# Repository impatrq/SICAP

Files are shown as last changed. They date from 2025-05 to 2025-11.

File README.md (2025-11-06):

erasebg-transformed (2)_Edited

<div align="center">

🔗 Visitanos en  
👉 <a href="https://sicap.site" target="_blank" rel="noopener noreferrer"><strong>sicap.site</strong></a>

## 🎥 Presentación oficial del proyecto

<a href="https://www.youtube.com/watch?v=k7C2opmh9fs" target="_blank" rel="noopener noreferrer">
  
</a>

<br><br>

<a href="https://www.instagram.com/proyecto.sicap/" target="_blank" rel="noopener noreferrer">
  Instagram
  @proyecto.sicap
</a>

</div>

---

## Logros y Reconocimientos

🏅 **Ganadores del 1° puesto en la categoría Prototipos - ONIET 2025** (puntaje: 96/100)  
🎖️ **5° puesto en SysApp - ONIET 2025** (puntaje: 87/100)  
📍 Representando a la **E.E.S.T. N°7 “Taller Regional Quilmes”**, Buenos Aires, Argentina

## Nuestra Propuesta

**SICAP** (Sistema Inteligente de Control de Almacén y Pañol) es una solución automatizada pensada para mejorar la gestión de herramientas, materiales e insumos en talleres, escuelas técnicas y empresas. Utiliza RFID, ESP32 y servidores locales para registrar entradas y salidas de forma confiable.

---

## Cómo surgió el proyecto

Observamos que muchos entornos técnicos carecen de un sistema eficiente para controlar el stock de herramientas. Esto genera pérdidas, desorganización y retrabajo. A partir de esa problemática, decidimos desarrollar SICAP como una solución real, útil y adaptable.

---

## Características Principales

- Lectura RFID con ESP32  
- Interfaz web responsive  
- Base de datos local  
- Control por ID de usuario  
- Placa RS232 a TTL desarrollada a medida  
- Registro de entradas/salidas automático  
- Acceso desde cualquier dispositivo conectado a la red

---

## Arquitectura del Sistema

SICAP se compone de tres módulos principales:

1. **Módulo de Lectura RFID (Hardware):**  
   Basado en un lector UHF SAMSys MP9320 y un microcontrolador **ESP32**, encargado de enviar los datos de las etiquetas detectadas al servidor mediante HTTP.

2. **Servidor Backend (Software):**  
   Desarrollado en **Django (Python)**, gestiona la base de datos, las peticiones del ESP32 y la administración del sistema.

3. **Interfaz Web (Frontend):**  
   Programada en **TypeScript con Ionic**, permite visualizar, editar y gestionar los registros de herramientas, empleados e insumos de forma intuitiva.

---

## Integrantes

WhatsApp Image 2025-08-27 at 11 02 59
<div align="center">

| Nombre | Contacto | Redes |
|:--|:--|:--|
| **Patella Tiziano** | 📧 tizianopatella40@gmail.com |  &nbsp;  &nbsp;  |
| **Lautaro Santolucito** | 📧 lauty.santolucito@icloud.com |  &nbsp;  &nbsp;  |
| **Facundo Spagnoletta** | 📧 facu.spagnoleta@gmail.com |  &nbsp;  &nbsp;  |
| **Facundo Ledesma** | 📧 facundoledesma140@gmail.com |  &nbsp;  &nbsp;  |
| **Pablo Osores** | 📧 pablooosores@gmail.com |  &nbsp;  &nbsp;  |

</div>

---

## Agradecimientos

Agradecemos a nuestros docentes, especialmente al profesor **Medina y Carlassara**, por su acompañamiento constante, y a **Transporte Miloser S.A.; Ledmull; La Popular Hamburguesas; Checkpoint** por su apoyo como sponsor durante el desarrollo del proyecto.

---
## Información de Contacto

🌐 Sitio web oficial: [sicap.site](https://sicap.site)  
📸 Instagram: [@proyecto.sicap](https://www.instagram.com/proyecto.sicap/) 📱🙌🎉  
📧 Correo: **proyecto.sicap08@gmail.com**

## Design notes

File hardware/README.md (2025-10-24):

# 🧰 Hardware – Proyecto SICAP

El directorio **`hardware/`** reúne todos los diseños, esquemas, prototipos y componentes físicos desarrollados para el proyecto **SICAP**.  
Aquí se documenta la parte **electrónica y estructural** del sistema, incluyendo las placas de conexión, adaptadores, antenas y configuraciones del lector RFID.

---

## ⚙️ Propósito del módulo de hardware

El objetivo del área de hardware dentro del proyecto SICAP es **garantizar la comunicación estable y confiable entre el lector RFID SAMSys MP9320, el microcontrolador ESP32 y las antenas UHF**, asegurando que el sistema funcione correctamente tanto a nivel eléctrico como de señal.

## 🔩 Componentes principales

| Componente | Función | Descripción |
|---|---|---|
| **SAMSys MP9320** | Lector RFID UHF | Captura las etiquetas EPC Gen2. |
| **ESP32 DevKit V1** | Microcontrolador | Ejecuta el firmware y envía datos al servidor. |
| **Conversor RS232–TTL** | Adaptador de señal | Permite la comunicación entre el lector y el ESP32. |
| **Antenas UHF** | Módulo lector pasivo | Detectan las etiquetas dentro del área de cobertura. |

---

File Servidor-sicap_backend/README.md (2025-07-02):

# SICAP - Backend

Este es el backend del sistema S.I.C.A.P., hecho con Django. Se encarga de recibir los datos enviados por el ESP32 (por ejemplo, los tags RFID) y guardarlos automáticamente en una base de datos.

Dicho en pocas palabras, el servidor interno de S.I.C.A.P.

---

## ¿Qué hace este servidor?

- Recibe datos a través del endpoint `/api/recibir/` en formato JSON.
- Guarda esos datos en la base, incluyendo el tag y la fecha/hora en que llegó.
- Más adelante, estos datos se van a poder consultar desde la web del proyecto.

---

## ¿Qué estructura tiene el proyecto?

- El proyecto Django se llama `sicap_backend`.
- Adentro hay una app llamada `registros`, que maneja todo lo relacionado a los tags RFID.

---

## ¿Qué modelo usamos para guardar los datos?

Dentro de la app `registros`, hay un modelo llamado `RegistroTag`. Guarda dos cosas:
- `tag_id`: el tag que mandó el ESP32.
- `fecha_hora`: se guarda automáticamente cuando llega el dato.

---

## ¿Qué falta?

- Conectar el ESP32 y hacer que mande el JSON real.
- Hacer pruebas con hardware real.
- En el futuro, conectar este backend con la página web para consultar todos los registros.

---

## Estado: 🟡 En pruebas

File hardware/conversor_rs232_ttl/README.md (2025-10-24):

# 🔌 Placa Conversora RS232 ↔ TTL – Proyecto SICAP

La **placa conversora RS232 ↔ TTL** fue diseñada como parte del sistema **SICAP** con el fin de permitir la comunicación directa entre el **lector RFID industrial SAMSys MP9320** y el **microcontrolador ESP32**.  
Dado que ambos dispositivos trabajan con niveles eléctricos diferentes, este circuito actúa como **interfaz de adaptación de señal** para garantizar una comunicación serial estable, segura y bidireccional.

---

## ⚙️ Propósito de la placa

- Adaptar los niveles de voltaje entre el lector RFID (RS232 ±12 V) y el ESP32 (TTL 3.3 V).  
- Permitir la transmisión y recepción de comandos seriales sin distorsión.  
- Asegurar la integridad de los datos durante la comunicación continua.  
- Reducir el riesgo de daño en los pines del microcontrolador por diferencia de tensiones.

---

## 🧠 Descripción técnica

El circuito está basado en el integrado **MAX3232**, un conversor de nivel de voltaje compatible con microcontroladores modernos de 3.3 V.  
Su función es traducir las señales **TX** y **RX** del lector RFID a niveles seguros y comprensibles para el ESP32, y viceversa.

### Características principales
- **Chip:** MAX3232 (compatible con 3.3 V y 5 V).  
- **Alimentación:** 3.3 V proveniente del ESP32.  
- **Entradas/salidas:**  
  - Lado RS232: conector DB9 (lector RFID).  
  - Lado TTL: pines TX, RX, GND hacia el ESP32.  
- **Frecuencia de transmisión:** hasta 250 kbps.  
- **Protección:** capacitores de desacople y diodos de protección en líneas críticas.

---

## 🧩 Integración en el sistema

La placa conversora forma parte del **bloque de hardware principal** del proyecto.  
Cumple el rol de intermediario entre el lector RFID y el microcontrolador:

Lector RFID (RS232)  ⇄  Placa Conversora  ⇄  ESP32 (TTL 3.3V)
El firmware del ESP32 se comunica a través de esta placa utilizando comandos ASCII, como por ejemplo `A,0!`, `Rd`, `Z!`, etc.  
El lector responde con tramas del tipo `{Rd,d:300833B2DDD9014035050000,t:EPC1G2}`, que son luego interpretadas por el firmware y enviadas al servidor SICAP.

---

## 🧪 Pruebas de validación

- **Conversión de señal:** Verificada con osciloscopio y mediciones en ambos lados.  
- **Comunicación estable:** Confirmada entre el lector y el ESP32 a distintas tasas de baudios.  
- **Integridad de datos:** Sin pérdida de información en lecturas prolongadas.  
- **Protección eléctrica:** Validada sin sobrecargas ni fallos por inversión de polaridad.  

---

## 🔩 Materiales utilizados

- 1 × Integrado **MAX3232**  
- 4 × Capacitores de 0.1 µF (para carga y desacople)  
- 1 × Conector DB9 hembra (para el lector)  
- 1 × Header macho 3 pines (TX, RX, GND hacia el ESP32)  
- 1 × Placa PCB diseñada y fabricada por el grupo SICAP  
- Cables Dupont y jumpers de conexión

---

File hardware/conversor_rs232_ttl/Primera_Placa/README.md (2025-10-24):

# ⚙️ Primera Placa – Conversor RS232 ↔ TTL

Esta carpeta contiene los archivos y documentación correspondientes a la **primera versión** de la **placa conversora RS232 ↔ TTL** desarrollada para el proyecto **SICAP**.  
Fue el primer prototipo funcional diseñado para adaptar las señales eléctricas entre el **lector RFID SAMSys MP9320** (nivel RS232 ±12V) y el **microcontrolador ESP32** (nivel TTL 3.3V).

---

## 🧠 Objetivo

El objetivo de esta primera placa fue **probar la comunicación física entre el lector y el ESP32**, validando la correcta conversión de voltajes y la transmisión de datos por puerto serial.

Se buscó construir un **circuito compacto, confiable y reproducible**, que reemplazara los adaptadores comerciales utilizados durante las pruebas iniciales.

---

## ⚠️ Error detectado en la versión

Durante las pruebas de funcionamiento se detectó un **error en el diseño del circuito impreso (PCB)**.  
El problema consistía en **una pista faltante** que impedía la correcta conexión entre una de las líneas de transmisión del chip MAX3232 y el conector correspondiente.

Como resultado:
- El circuito **alimentaba correctamente el integrado**,  
  pero **no transmitía señal entre el lector y el ESP32**.  
- Las pruebas con osciloscopio mostraron ausencia de datos en el pin TX del lado TTL.  
- Se descartaron fallas del chip o del cableado, confirmando un **error de diseño** en la placa.

---

## 🔄 Resultado y corrección

A partir de este error, se procedió al rediseño completo de la placa, dando origen a la **Segunda_Placa**, que incluyó:
- Corrección de la pista faltante.  
- Reubicación de componentes para mayor claridad.  
- Trazado más limpio de las líneas de comunicación.  
- Testigo de funcionamiento (LED)
- Verificación del esquema con simulación previa a la fabricación.

Esta mejora permitió establecer una comunicación estable y definitiva entre el **lector RFID** y el **ESP32**.

---

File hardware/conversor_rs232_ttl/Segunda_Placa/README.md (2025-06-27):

# RS232 a TTL

Este módulo es un conversor de señal RS232 a TTL, utilizado en el proyecto SICAP para permitir la comunicación entre el microcontrolador ESP32 y el lector RFID que trabaja con señal RS232.

---

**¿Por qué lo hicimos?**  
Los lectores RFID comerciales que conseguimos trabajan bajo el protocolo RS232, pero el ESP32 solo puede interpretar señales TTL (3.3V/5V). Por eso, diseñamos e implementamos esta plaqueta para hacer la conversión y asegurar una lectura estable y sin errores.

---

**🛠️ Componentes usados**  
- MAX232
- Capacitores de desacople (1µF)  
- PCB diseñada a medida (archivos incluidos)  
- Pines macho para conexión a protoboard

---

**📂 Archivos incluidos**  
- `esquematico.pdf`: Diagrama del circuito  
- `pcb_layout.png`: Imagen de la placa diseñada  
- `README.md`: Este archivo  

> Si aún no subiste los archivos, podés preparar esos .pdf y capturas para completar este README.

---

**📈 Estado del módulo**  
✅ Probado con ESP32 y lector RFID  
✅ Confirmada la lectura estable de tarjetas

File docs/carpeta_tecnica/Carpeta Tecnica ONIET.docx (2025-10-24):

# Proyecto S.I.C.A.P – Carpeta Técnica Oficial

Sistema Integral de Control Automatizado del Pañol (SICAP)

“Orden inteligente, control eficiente”

## 1. Introducción y Objetivos

El Proyecto S.I.C.A.P. (Sistema Integral de Control Automatizado del Pañol) surge como respuesta a un problema cotidiano en talleres, escuelas técnicas y empresas: la pérdida de herramientas y la falta de trazabilidad en su uso. Este sistema propone modernizar la gestión del pañol de herramientas mediante tecnología RFID e IoT, evitando pérdidas, mejorando la organización y permitiendo decisiones informadas basadas en datos actualizados .

Objetivo general: Desarrollar e implementar un sistema integral y automatizado de control de activos (herramientas) en un pañol, capaz de registrar en tiempo real la entrada y salida de herramientas y quién las toma, eliminando registros manuales y mejorando la eficiencia en la gestión.

Objetivos específicos:

- Identificación automática por RFID: Equipar cada herramienta con una etiqueta RFID UHF y cada usuario con una tarjeta/pulsera RFID para detectar su identidad al retirar o devolver herramientas.
- Detección y registro en tiempo real: Implementar un portal RFID en la entrada/salida del pañol que, mediante antenas y un lector controlado por ESP32, detecte automáticamente qué herramienta sale o ingresa y qué usuario la porta.
- Servidor local de datos: Desplegar un servidor local (Raspberry Pi) con una base de datos integrada que reciba los datos de cada evento (herramienta retirada/devuelta, usuario, fecha y hora) y los almacene automáticamente.
- Interfaz de gestión web: Desarrollar una aplicación web accesible desde cualquier dispositivo en la red interna, para visualizar el inventario en tiempo real (qué herramientas están disponibles o en uso, quién las tiene, cuándo fueron retiradas), así como administrar usuarios y herramientas.
- Seguridad y control: Restringir el sistema a una red local dedicada para asegurar que solo el personal autorizado pueda acceder, y mantener un registro histórico de movimientos para auditorías o análisis futuros.
- Integración pedagógica: Permitir a los desarrolladores (estudiantes) aplicar conocimientos de electrónica, redes y programación en un proyecto integrador real, aprendiendo sobre microcontroladores, bases de datos, backend web y desarrollo frontend, al tiempo que resuelven un problema concreto de su entorno educativo.

## 2. Justificación Técnica y Pedagógica

Justificación técnica: Muchas instituciones educativas y talleres enfrentan pérdida de herramientas, desorden y falta de control en sus pañoles. Un sistema automatizado como SICAP mejora significativamente la eficiencia al eliminar registros manuales y reducir extravíos, brindando control y responsabilidad compartida. La tecnología RFID UHF fue elegida por su capacidad de identificar múltiples objetos a distancia, incluso varios metros, sin requerir línea de vista. Esto la hace ideal para monitorear herramientas en tiempo real sin intervención humana, evitando errores y registrando todo automáticamente. Además, el uso de una arquitectura IoT local (ESP32 + servidor Raspberry Pi) garantiza que el sistema funcione aunque no haya Internet, manteniendo los datos dentro de la institución para mayor seguridad y velocidad de acceso.

Justificación pedagógica: El proyecto SICAP se desarrolló en un contexto escolar técnico, por lo que su implementación tuvo también fines educativos. Los estudiantes involucrados reforzaron competencias en diversas áreas de la tecnología:

- Electrónica y hardware: diseño de circuitos (por ejemplo, un conversor RS232-TTL para el lector RFID), integración de sensores/antenas RFID con microcontroladores, y ensamblaje de un portal de detección.
- Programación embebida: desarrollo de código en MicroPython para el ESP32, manejando comunicación serial (UART) y protocolos de red (WiFi).
- Administración de sistemas: configuración de un servidor Linux (Raspberry Pi), instalación de servicios (servidor web Django, base de datos SQLite) y configuración de redes LAN/WiFi.
- Desarrollo web: implementación de un backend con Django (incluyendo APIs REST) y una interfaz web frontend (web app) usando frameworks modernos (Ionic/Angular), aplicando principios de diseño web responsivo.
- Gestión de proyectos: documentación técnica completa, pruebas de funcionamiento y trabajo colaborativo, simulando un entorno de desarrollo profesional. Se integraron áreas de software y hardware, lo que brindó a los alumnos una experiencia holística de ingeniería de sistemas.

Desde el punto de vista pedagógico, SICAP sirvió como proyecto integrador que permitió a los estudiantes aplicar en la práctica contenidos de años anteriores y resolver problemas reales de su institución. Asimismo, se fomentó el trabajo en equipo, la resolución de problemas, la creatividad en el diseño de soluciones y la comunicación efectiva (por ejemplo, presentando el proyecto a la comunidad y buscando sponsors para componentes). En resumen, SICAP no solo aporta una solución tecnológica versátil y funcional al control de activos físicos , sino que también representa un valioso logro pedagógico al consolidar el aprendizaje multidisciplinar en un proyecto tangible.

## 3. Alcance y Limitaciones

Alcance del sistema: El alcance de SICAP es modular y escalable, lo que significa que puede adaptarse a distintos entornos y escalas de uso . Inicialmente, el proyecto se centró en un pañol de herramientas de un taller escolar, pero la misma solución es aplicable a otros escenarios:

- En bibliotecas, para control automatizado de préstamos y devoluciones de libros mediante etiquetas RFID en libros y carnés .
- En depósitos de insumos o almacenes, para monitorear stock en tiempo real y registrar movimientos de inventario automáticamente .
- En laboratorios, para seguimiento de equipos y materiales sensibles.
- En general, cualquier espacio que necesite gestión eficiente y trazable de objetos físicos podría beneficiarse de SICAP .

El sistema abarca todos los componentes necesarios para su funcionamiento autónomo dentro de la institución:

- Un portal RFID físico instalado en el acceso al pañol.
- Múltiples etiquetas RFID UHF adheridas a cada herramienta, y tags RFID personales para identificar usuarios (p. ej., en tarjetas o pulseras).
- Un dispositivo lector (ESP32) conectado a las antenas RFID del portal, encargado de leer los tags y transmitir los datos.
- Una infraestructura de red local (router WiFi dedicado) que conecta inalámbricamente el ESP32 con el servidor central.
- Un servidor central (Raspberry Pi) ejecutando el backend (Django) y alojando la base de datos local donde se almacenan los registros.
- Una aplicación web accesible a través de la red local para consultar el estado del sistema e interactuar (gestionar usuarios, etc.).

Limitaciones del proyecto: Si bien SICAP se diseñó para ser versátil, en su implementación actual presenta las siguientes limitaciones:

- Alcance físico limitado: El sistema está pensado para operar en la red local de la institución. No cuenta con acceso remoto vía Internet (aunque podría incorporarse en el futuro), lo que significa que para usar la web app o consultar datos, el dispositivo cliente debe estar conectado al router interno de SICAP.
- Cobertura RFID específica: Se emplearon etiquetas y antenas UHF optimizadas para distancias de varios metros. Sin embargo, la efectividad de detección puede variar según el ambiente: presencia de metal u obstáculos, orientación de las etiquetas, interferencias, etc. Es posible que algunas lecturas fallen si una etiqueta está bloqueada o demasiado alejada de la antena. Se calibró el portal para cubrir la entrada del pañol, pero áreas más amplias o múltiples accesos requerirían antenas adicionales (no implementadas en este prototipo).
- Capacidad de procesamiento local: La Raspberry Pi y la base de datos SQLite manejan eficientemente la escala de un pañol escolar (decenas de herramientas y usuarios, eventos diarios). En instalaciones mucho más grandes (ej. cientos de herramientas pasando continuamente), podría requerirse un servidor más robusto o una base de datos diferente (PostgreSQL/MySQL) para mejor rendimiento.
- Seguridad básica: La red WiFi dedicada emplea contraseña WPA2 para acceso. El backend Django actualmente no implementa autenticación sofisticada para la API de recepción de tags (se permitió envío sin token ni TLS dado el entorno cerrado). Para producción se recomendaría añadir autenticación en la API, cifrado en tránsito (HTTPS) y gestión de roles de usuario en la aplicación web.
- Disponibilidad de energía y mantenimiento: El portal RFID requiere que el lector ESP32 y las antenas estén alimentados continuamente mientras el pañol está en uso. Se debe prever una fuente de alimentación estable cerca de la puerta. Asimismo, las etiquetas RFID en herramientas pueden dañarse o despegarse con el uso rudo; se debe implementar un mantenimiento periódico para reponer etiquetas defectuosas y calibrar el lector.
- Integración con sistemas existentes: Actualmente SICAP funciona de manera autónoma y no está integrado con otros sistemas de la escuela (por ejemplo, no se enlaza con sistemas de gestión escolar). Su adopción masiva requeriría evaluar cómo vincular o exportar datos a plataformas de gestión si fuese necesario.
- Estado de prototipo: Este proyecto es un prototipo funcional de fin de curso. Si bien cumple con las funcionalidades básicas esperadas, no ha sido sometido a uso prolongado en un entorno de producción. Algunas características avanzadas quedaron fuera del alcance (ver sección de mejoras futuras), y podrían implementarse en desarrollos posteriores.

## 4. Arquitectura General del Sistema

Descripción general: La arquitectura de SICAP sigue un modelo IoT local, con componentes distribuidos que se comunican a través de una red interna. A continuación se presenta el diagrama de bloques e interconexiones entre los módulos principales:

- Etiquetas RFID (UHF): Cada herramienta del pañol lleva adherida una etiqueta RFID pasiva UHF on-metal, con un código único. Asimismo, cada usuario autorizado posee una pulsera RFID UHF personal. Estas etiquetas son los identificadores que permiten al sistema distinguir qué objeto y qué persona están interactuando.
- Portal RFID de acceso: En la entrada/salida del pañol se instaló un portal con antenas RFID UHF capaces de leer las etiquetas a distancia. El portal está compuesto por un marco (similar al de detectores de metales en accesos) donde se montan las antenas de forma que cubren el ancho del paso (ver diseño en la imagen a continuación). Cuando un usuario ingresa o sale por el portal llevando herramientas, las antenas detectan simultáneamente la etiqueta del usuario y las de las herramientas en cuestión .

Figura 1: Diseño del portal RFID UHF para el ingreso al pañol. Se muestran las dimensiones estructurales y ubicación de antenas. Este marco permite detectar automáticamente qué herramientas pasan y quién las lleva al atravesar el portal .

- Módulo ESP32 (Lector RFID): Un microcontrolador ESP32 ubicado en el portal actúa como cerebro embebido del lector RFID. Está conectado a las antenas mediante un módulo lector RFID UHF. En este proyecto se utilizó un lector cuyo módulo de radiofrecuencia comunicaba por interfaz serial (RS-232) los códigos de etiquetas detectadas. Dado que el ESP32 funciona a niveles TTL, se incorporó un conversor RS232-TTL personalizado para interconectar el lector con el ESP32 (ver Figura 2). El ESP32 se encarga de:
  - Leer continuamente los datos enviados por el módulo RFID (códigos de tags de 8 bytes en nuestro caso, recibidos por UART).
  - Filtrar y procesar los eventos de lectura: por ejemplo, evita registrar duplicados inmediatos del mismo tag (misma herramienta pasando varias veces en corto tiempo) usando temporizadores.
  - Determinar cuándo se ha detectado un usuario y una o más herramientas simultáneamente al pasar por el portal.
  - Conectarse a la red WiFi interna y enviar los datos al servidor. Cuando se identifica un evento válido (p. ej., herramienta X retirada por usuario Y), el ESP32 formatea esa información en un mensaje JSON y lo envía vía HTTP POST al endpoint del servidor Django (ver sección 5.4).
- Router y Red Local (LAN): Para la comunicación, se instaló un router WiFi dedicado con SSID propio (en nuestro caso llamado "SICAP") y contraseña WPA2. Tanto el ESP32 como la Raspberry Pi servidor se conectan a este router, formando una red local aislada. No se requiere acceso a Internet para el funcionamiento, aunque el router podría estar conectado a Internet para actualizaciones si se desea. La elección de un router dedicado garantiza un canal de comunicación confiable y privado.
  - Configuración de red: Se configuró el router con el rango de IP 192.168.111.0/24 (por ejemplo) para evitar conflictos con otras redes comunes. La Raspberry Pi tiene una IP fija (o reservada por DHCP) – en el prototipo se usó 192.168.111.218 – de modo que el ESP32 conoce de antemano a qué dirección enviar los datos del tag leído. Es importante asignar IP fija al servidor para que los dispositivos embebidos puedan apuntar siempre al mismo host.
  - La red interna permite también que otros dispositivos (p. ej. una PC, tablet o smartphone del encargado) se conecten vía WiFi para acceder a la aplicación web de SICAP. Al ser una intranet local, solamente quienes tengan la contraseña WiFi podrán conectarse, añadiendo una capa de seguridad.
- Servidor Principal (Raspberry Pi): El corazón del sistema es una Raspberry Pi 4 (u otro modelo equivalente), que actúa como servidor web y base de datos local. La Raspberry Pi se conectó por WiFi al router SICAP (y puede también estar conectada por cable Ethernet al mismo router para mayor estabilidad). En este servidor corren los siguientes servicios:
  - Backend Django: Una aplicación web desarrollada con el framework Django (Python) que expone endpoints para recibir datos y una interfaz administrativa para gestionar la información. El rol del backend es recibir los mensajes JSON enviados por el ESP32 con cada lectura de RFID y almacenarlos en la base de datos. Además, provee una API para que la aplicación web de gestión pueda consultar los registros de herramientas, estado de usuarios, etc. (Ver detalles en sección 5.4).
  - Base de datos local: Se utiliza una base de datos SQL alojada en la misma Raspberry Pi para persistir los datos. Cada evento de retirada/devolución de una herramienta se guarda como un nuevo registro (con ID de tag). Asimismo, se almacenan tablas de usuarios autorizados, herramientas, y otros datos de configuración del sistema. La elección de SQLite simplifica la instalación (no requiere un servidor de BD separado) y es suficiente para el alcance del proyecto. No obstante, la arquitectura Django permite migrar fácilmente a otro motor de base de datos en el futuro si es necesario.
  - Servidor web y aplicación de gestión: La Raspberry Pi también sirve la aplicación web de SICAP, accesible a través de un navegador por URL local (http://192.168.111.218:5000). Esta interfaz web permite a un administrador o encargado del pañol visualizar información y administrar el sistema (ver sección 5.5). Django provee la entrega de esta interfaz, ya sea mediante templates renderizados en servidor o sirviendo una aplicación frontend separada. En el prototipo, se implementaron plantillas HTML básicas para login y dashboard, y también se integró un proyecto front-end separado para explorar funcionalidades más avanzadas (descrito más adelante).
- Dispositivos cliente (Web App): Cualquier dispositivo (PC de escritorio, laptop, tablet, smartphone) conectado al WiFi interno de SICAP puede acceder a la aplicación web a través del navegador. Esto permite, por ejemplo, que:
  - El bibliotecario o encargado del pañol consulte en su computadora qué herramientas están fuera y con quién.
  - Los docentes desde sus teléfonos vean si hay herramientas disponibles o quién las tomó.
  - Se realicen altas/bajas de herramientas o usuarios desde una interfaz amigable.

El siguiente esquema resume el flujo principal del sistema:

1. Identificación RFID: Cuando un usuario atraviesa el portal con herramientas, las antenas RFID leen simultáneamente la etiqueta personal del usuario y las etiquetas de cada herramienta que lleva .
2. Procesamiento embebido: El ESP32 recibe los códigos de tags vía UART, los interpreta y determina el evento (ej. “Herramienta A y B retiradas por Usuario X”). Aplica un filtro de repetición para evitar múltiples envíos del mismo evento. En nuestro código, si un tag leído es distinto al último enviado o ha transcurrido más de 2 segundos, lo consideramos un nuevo evento válido.
3. Envío al servidor: El ESP32 se asegura de estar conectado al WiFi (SSID “SICAP”). Luego envía un mensaje JSON al servidor Django haciendo una petición HTTP POST al endpoint correspondiente (por ejemplo /api/v1/register/tag/) con el contenido {"tag": "<ID_lectura>"}. Cada lectura se envía inmediatamente (con un pequeño retardo programado de ~1 segundo entre lecturas para no saturar).
4. Registro en base de datos: Al llegar la petición al backend, la vista de Django correspondiente parsea el JSON, extrae el tag y crea un nuevo registro en la base de datos con el código de tag y la fecha/hora actual. De esta forma queda persistente la operación. Si el tag corresponde a un usuario o herramienta conocidos, se puede enlazar esa referencia (en este prototipo, por simplicidad, se almacenan los tags crudos; un desarrollo futuro podría tener tablas separadas y relaciones, ver sección 6).
5. Visualización web: Los registros guardados pueden ser consultados desde la aplicación web. Por ejemplo, un módulo de “Movimientos” listaría las últimas entradas/salidas con campos de herramienta, usuario, hora, etc. También se ofrece al usuario de la web app una vista general del inventario actualizado en tiempo real: qué herramientas están en el pañol y cuáles están actualmente prestadas (y en manos de quién) . Esto es posible porque cada vez que llega un registro nuevo, la base de datos refleja el cambio de estado de esa herramienta (pasó de disponible a en uso, o viceversa). La web app puede consultar periódicamente o vía solicitud del usuario para refrescar estos datos.

Esta arquitectura modular garantiza que cada subsistema (embebido, red, servidor, frontend) pueda desarrollarse y diagnosticarse de forma independiente, a la vez que se integran en un todo funcional.

## 5. Descripción Detallada de los Módulos

A continuación, se describen en detalle todos los módulos y componentes del proyecto SICAP, incluyendo hardware y software, con ejemplos de código, esquemas y consideraciones técnicas para replicar cada parte.

### 5.1 Módulo ESP32 (Lector RFID)

Rol en el sistema: El módulo basado en ESP32 funciona como dispositivo lector RFID inteligente en el portal. Su responsabilidad es captar los datos crudos de las etiquetas RFID a través del lector/antena y procesarlos mínimamente para luego enviarlos al servidor central. Esto descarga al servidor de la tarea de lidiar con la comunicación de bajo nivel con el hardware RFID.

Hardware utilizado:

- Microcontrolador ESP32 (modelo ESP32-WROOM-32 dev kit): seleccionado por su conectividad WiFi integrada, su buen desempeño y su familiaridad en programación (soporta entornos Arduino C++ o MicroPython). Se alimenta con 5V (por el cable USB o fuente externa) y regula internamente a 3.3V.
- Módulo lector RFID UHF externo: se empleó un lector UHF de largo alcance que comunica las lecturas vía interfaz serial RS-232. Este módulo está conectado a antenas UHF (al menos 2 antenas para cubrir ambos lados del portal). Los detalles específicos del modelo pueden variar; en nuestro prototipo se utilizó un kit con antenas tipo panel UHF y un módulo lector capaz de leer tags EPC Class1 Gen2.
- Conversor RS-232 a TTL: dado que la UART del ESP32 maneja niveles TTL (3.3V) y el lector entregaba RS-232 (+/- 12V), se fabricó un pequeño conversor basado en MAX3232. Este circuito incluye un MAX3232CPE y capacitores de bomba de carga para traducir las señales RX/TX. El conversor se implementó en una placa impresa casera (Figura 2) con un conector DB9 hacia el módulo lector y pines hembra hacia el ESP32 (GPIO17 y GPIO16 utilizados para RX/TX respectivamente en el UART2 del ESP32).

Figura 2: Fotografía del conversor RS232-TTL diseñado para conectar el lector RFID serial al ESP32. Se observa el chip MAX3232 y el conector DB9 para la interfaz RS-232 del módulo RFID. Este conversor adapta los niveles de voltaje y permite al ESP32 comunicarse con el lector sin dañar sus puertos.

- Antenas RFID: antenas UHF polarización circular, montadas en el marco del portal. Conectadas al módulo lector mediante coaxiales (tipo SMA/N). Se ubicaron de forma enfrentar la zona de paso, garantizando un campo de lectura adecuado.
- Fuente de alimentación: El ESP32 y el conversor se alimentan con 5V (tomado del USB del ESP32 o una fuente regulada). El módulo lector RFID UHF suele requerir 12V DC y consume corriente significativa al activar las antenas (varios amperios pico); se usó una fuente de 15V 4A dedicada para el lector. Importante conectar todas las tierras comunes.

Conexiones principales:

- ESP32 GPIO16 (RX2) ⇔ TX del conversor (desde lector RFID).
- ESP32 GPIO17 (TX2) ⇔ RX del conversor (hacia lector RFID) – aunque en nuestro caso el lector se configura para output continuo de tags, por lo que la comunicación es principalmente unidireccional. Aun así, se dejó conectada la vía de transmisión por si se requiere enviar comandos al lector (p.ej. para configurar potencia, inicio/parada de lectura).
- ESP32 3.3V ⇔ Vcc del MAX3232 (el MAX3232 opera a 3.3V).
- Conversor DB9 ⇔ Puerto serie del lector RFID.
- ESP32 VIN (5V) ⇔ Fuente 5V (alimentación del ESP32).
- Lector RFID 12V ⇔ Fuente 12V.
- Todos GND unidos (ESP32 GND, conversor GND, lector GND, fuente negativa común).

Programación del ESP32:

Se optó por programar el ESP32 usando MicroPython por su rapidez de desarrollo y facilidad de legibilidad, aunque una alternativa podría haber sido usar C/C++ (framework Arduino ESP32). MicroPython ofreció la ventaja de contar con librerías como urequests para realizar fácilmente peticiones HTTP.

El código se estructuró en tres archivos principales cargados en el ESP32:

- wifi.py – encargado de conectar el ESP32 a la red WiFi SICAP al iniciar.
- Reader.py – clase RFIDReader para manejar la UART y leer bytes de tags.
- app.py – bucle principal que combina todo: inicializa WiFi, instancia el lector, espera detecciones y envía peticiones al servidor.

Conexión WiFi: En wifi.py definimos la función de conectar, fijando SSID y password de la red. Por simplicidad, estos están codificados como constantes en el código:

# Fragmento de wifi.py

import network
import time

def connect_to(ssid : str, passwd : str) -> None:
"""Conecta el microcontrolador a la red indicada.

Parameters
----------
ssid : str
Nombre de la red a conectarse
passwd : str
Contraseña de la red
"""

import network
from time import sleep

sta_if = network.WLAN(network.STA_IF)
if not sta_if.isconnected():
print("Connecting to network...")
sta_if.active(True)
sta_if.connect(ssid, passwd)
while not sta_if.isconnected():
print(".",end="")
sleep(.05)

print()
print("Network config:", sta_if.ifconfig())
print()

Cuando se energiza el ESP32, intenta unirse a la red WiFi interna. Si no lo logra en el lapso dado, se imprime un error crítico y (en nuestro código) se detiene el programa, dado que sin conexión no tendría sentido leer etiquetas. En la práctica, se podría programar reintentos indefinidos.

Lectura de tags por UART: La clase RFIDReader configura la UART2 del ESP32 a 57600 baudios (protocolo del lector RFID). Por ejemplo:

from machine import UART
import time

class RFIDReader:
def __init__(self, tx=17, rx=16, baudrate=57600, uart_id=1):
# Ajustá uart_id/pines/baud según tu hardware
self.uart = UART(uart_id, baudrate=baudrate, tx=tx, rx=rx,
timeout=100, timeout_char=20)
self._buf = "" # acumulador de texto

def _extract_epc_from_text(self, text):

start = text.find("d:")
if start == -1:
return None
start += 2
# Buscar fin de campo
end_candidates = []
for ch in (',', ';', '}'):
pos = text.find(ch, start)
if pos != -1:
end_candidates.append(pos)
if not end_candidates:
return None
end = min(end_candidates)
epc = text[start:end].strip().upper()
# Validamos que sea HEX (0-9 A-F)
if epc and all(c in "0123456789ABCDEF" for c in epc):
return epc
return None

def read_tag(self):
"""
Lee del UART, acumula y devuelve un EPC (Tag ID) si aparece.
Si no hay EPC completo, devuelve None.
"""
data = self.uart.read()
if data:
try:
chunk = data.decode('latin1', 'ignore')
except:
chunk = ""
if chunk:
self._buf += chunk

# Procesar por líneas si vienen \r\n
if '\n' in self._buf or '\r' in self._buf:
lines = self._buf.splitlines(True) # conserva separadores
# Dejo el último fragmento (posible incompleto) en el buffer
tail = ""
for ln in lines:
if ln.endswith('\n') or ln.endswith('\r'):
epc = self._extract_epc_from_text(ln)
if epc:
return epc
else:
tail += ln
self._buf = tail

# Por si vienen sin saltos de línea, buscar en el buffer entero
epc = self._extract_epc_from_text(self._buf)
if epc:
# recorto el buffer para que no crezca infinito
self._buf = self._buf[-256:]
return epc

# limpieza preventiva
if len(self._buf) > 4096:
self._buf = self._buf[-512:]

return None

En nuestro caso, cada tag RFID UHF proporciona un identificador único de 8 bytes que representamos en formato hexadecimal. La función read_tag() devuelve el código del tag leído (por ejemplo "4B01020304AABBCC") o None si no se leyó nada en ese instante. El módulo RFID está en modo continuous read, enviando el ID inmediatamente al detectar una etiqueta nueva dentro del rango.

Lógica principal de envío de datos: En app.py se combinan la conexión WiFi, la lectura de tags y el envío HTTP. Un pseudocódigo simplificado:

1. Conectar WiFi (usando wifi.conectar()).
2. Imprimir “Listo. Esperando tags…” e iniciar bucle infinito.
3. En cada iteración del loop, llamar tag_detectado = lector.read_tag().
4. Si tag_detectado no es None, entonces:
  - Obtener timestamp actual (time.time()).
  - Si el tag es distinto al último enviado o ha pasado más de TIMEOUT_TAG segundos desde el último envío, procesarlo:
    - Imprimir por consola del ESP32 el tag detectado.
    - Formar un JSON {"tag": tag_detectado}.
    - Hacer response = urequests.post(API_URL, json=json_data) donde API_URL es la URL del endpoint del servidor (por ejemplo http://192.168.111.218:8000/api/v1/register/tag/ en nuestro caso).
    - Verificar response.status_code: si está en rango 200 (OK), imprimir confirmación; si es error (>=400), imprimir código y texto de error.
    - Llamar response.close() para liberar la conexión HTTP.
    - Guardar ultimo_tag_enviado = tag_detectado y tiempo_ultimo_envio = tiempo_actual para el control de duplicados.
  - Si el tag es igual al último y ocurrió muy recientemente, se ignora (esto evita inundar de lecturas repetidas cuando una misma etiqueta permanece en rango).
5. Volver al inicio del loop (pequeño delay interno de 1 seg entre iteraciones para no saturar CPU).

import time
from Reader import RFIDReader
import urequests
import wifi

SSID = "SICAP"
PASSWORD = "graciasamigo"
SERVER_IP = "192.168.111.218" # Django
API_URL = f"http://{SERVER_IP}:5000/api/v1/register/tag/"

# Parámetros de robustez
LOOP_DELAY_MS = 50 # 20 Hz de chequeo
STABLE_READS = 3 # lecturas consecutivas iguales para considerar "estable"
ABSENCE_MS = 600 # tiempo sin leer nada = tag retirado

lector = RFIDReader(tx=17, rx=16)

# Estado
current_tag = None # tag "latched" (enviado y sostenido)
stable_tag = None # último tag visto para conteo de estabilidad
stable_count = 0 # lecturas consecutivas del mismo tag
last_seen_ms = time.ticks_ms() # última vez que se leyó ALGÚN tag

print("Iniciando programa...")
wifi.connect_to(SSID, PASSWORD)
print("\nListo. Esperando tags...")

def send_tag(tag_val):
try:
payload = {"tag": tag_val}
resp = urequests.post(API_URL, json=payload)
status = resp.status_code
body = ""
try:
body = resp.text
except Exception:
pass
resp.close()

if 200 <= status < 300:
print("✅ Servidor respondió: Tag registrado.")
else:
print(f"❌ Error del servidor: {status} {body}")

except Exception as e:
print("❌ Error de conexión al enviar el tag:", e)

while True:
now = time.ticks_ms()
tag_detectado = lector.read_tag() # Devuelve el EPC (Tag ID) o None

if tag_detectado:
print(tag_detectado) # 📡 imprime el Tag ID crudo

# Actualizamos la última vez que vimos un tag
last_seen_ms = now

# Debounce por lecturas consecutivas
if tag_detectado == stable_tag:
stable_count += 1
else:
stable_tag = tag_detectado
stable_count = 1

# Si el tag se mantiene estable, lo enviamos al servidor
if current_tag is None and stable_count >= STABLE_READS:
print(f"Tag detectado estable: {stable_tag}. Enviando al servidor...")
send_tag(stable_tag)
current_tag = stable_tag # quedamos en HELD

else:
# Si no hay tag leído y antes había uno, chequeamos si se retiró
if current_tag is not None and time.ticks_diff(now, last_seen_ms) > ABSENCE_MS:
print("Tag retirado. Listo para próximo registro.")
current_tag = None
stable_tag = None
stable_count = 0

time.sleep_ms(LOOP_DELAY_MS)

(Notar que en el código del prototipo se usó un endpoint dentro de /admin/ por simplicidad, aunque finalmente se habilitó uno en /api/v1/. Lo correcto es usar el endpoint de API para no depender de la interfaz admin de Django).

Consideraciones de programación del ESP32:

- El ESP32 se programó cargando MicroPython firmware primero. Luego mediante la herramienta Thonny IDE o ampy, se subieron los archivos .py al sistema de archivos interno del ESP32.
- Se configuró un main.py para que al reiniciar el ESP32 arranque automáticamente el script principal (app.py). Así, en cuanto recibe alimentación, el dispositivo se conecta al WiFi y empieza a monitorear y reportar tags sin intervención manual.
- Se implementaron prints de depuración en serie (como se ve en el código) de modo que durante el desarrollo, conectando el ESP32 por USB al PC, se podía ver en la consola (REPL) qué tags leía y las respuestas del servidor.
- La gestión de errores incluyó reconectar WiFi en caso de desconexión y manejo de excepciones en el envío HTTP (por ejemplo, si el servidor no responde, se imprime el error pero el ESP32 sigue funcionando y tratando de reenviar en la siguiente detección).
- Timing: Dado que el lector UHF puede detectar muchas etiquetas casi simultáneamente, un posible reto es leer múltiples tags juntos. En esta versión, el código read_tag() está orientado a leer de a uno (asumiendo que el módulo RFID envía un tag ID a la vez). Si hubieran múltiples, el módulo suele enviar secuencialmente varias tramas. El ESP32 las irá procesando en bucle. Existe la posibilidad de que si pasan 5 herramientas juntas, se envíen 5 POST seguidos. Esto fue considerado aceptable para nuestro caso ya que la red local puede soportarlo. Sin embargo, si se quisiera optimizar, podría enviarse un solo POST con una lista de tags detectados en un intervalo corto, reduciendo carga. Este tipo de optimización quedó como mejora futura no implementada.

En resumen, el módulo ESP32 actúa como puente entre el mundo físico RFID y el backend digital, dotando al sistema de la capacidad de sentir qué ocurre en el pañol (qué se mueve y quién lo hace) y comunicarlo en tiempo real al servidor.

## 5.2 Módulo Raspberry Pi (Servidor Principal)

### Función

La Raspberry Pi es el servidor central de SICAP: aloja la lógica de backend (Django), la base de datos y expone las APIs REST consumidas por la web app y por el ESP32. Permanece encendida durante el horario de uso del pañol, lista para recibir lecturas RFID y atender consultas desde la interfaz web.

### Hardware y SO

- Raspberry Pi 4 Model B (4 GB RAM). El sistema es liviano; podría correr en una Pi 3.
- Raspberry Pi OS (Bullseye, 32 bits), basado en Debian.
- Conexión recomendada: Ethernet al router (más estable); alternativa: Wi-Fi.
- Configuración inicial con monitor/teclado; operación habitual por SSH.
- IP reservada en el router para acceso consistente en LAN (ej. 192.168.111.218).

### Instalación del entorno software

- Python 3 + venv para aislar dependencias del proyecto.
- Django como framework del backend.
- Django REST Framework (DRF) para las APIs.
- corsheaders para permitir solicitudes desde el front Angular cuando corre en otro origen/puerto.
- WhiteNoise para servir estáticos sin depender de Nginx.
- Gunicorn como servidor WSGI de producción.
- systemd para arranque automático y reinicio del servicio si falla.
- Base de datos por defecto: SQLite3 (suficiente para el alcance del proyecto; escalable a PostgreSQL/MariaDB si se requiere).

### Código del backend

Estructura (carpetas principales del proyecto SICAP_Backend):

- sicap_backend/ (proyecto): settings.py, urls.py, wsgi.py.
- registros/ (app principal):
  - models.py: modelo RegistroTag.
  - views.py: vistas de ingesta de tags, listado y edición.
  - serializers.py: serialización DRF (cuando aplica).
  - urls.py: rutas del módulo.
- usuarios_login/ (autenticación/gestión de usuarios): vistas y serializers básicos para login y administración.
- templates/ (plantillas simples de apoyo para prototipos).

Modelo de datos (extracto conceptual, basado en tu implementación):

from django.db import models
from django.utils import timezone
class RegistroTag(models.Model):
CATEGORIA_AELEGIR = (
('persona', 'Persona'),
('insumo', 'Insumo'),
)
nombre = models.CharField(max_length=100, blank=True, null=True)
tag = models.CharField(max_length=100)
fecha_hora = models.DateTimeField(default=timezone.now)
categoria = models.CharField(max_length=20, choices=CATEGORIA_AELEGIR, blank=True, null=True, default=None )
def __str__(self):
return f"{self.tag} - {self.fecha_hora}"
class Panol(models.Model):
nombre = models.CharField(max_length=100)
icono = models.CharField(max_length=50, default='cube')
def __str__(self):
return self.nombre
class Asignacion(models.Model):
persona_tag = models.CharField(max_length=100)
persona_nombre = models.CharField(max_length=100, blank=True, null=True)
item_tag = models.CharField(max_length=100)
item_nombre = models.CharField(max_length=100, blank=True, null=True)
asignado_en = models.DateTimeField(default=timezone.now)
devuelto_en = models.DateTimeField(blank=True, null=True)
activo = models.BooleanField(default=True)
def __str__(self):
estado = "activo" if self.activo else "devuelto"
return f"{self.persona_tag} <- {self.item_tag} ({estado})"

Nota: nombre y categoria son opcionales para permitir personalización gradual; tag es el identificador efectivo leído por el ESP32.

### Configuración de Django (puntos clave)

- ALLOWED_HOSTS: incluir la IP local de la Pi y localhost para acceso LAN.
- Zona horaria: TIME_ZONE = "America/Argentina/Buenos_Aires" y USE_TZ = True para almacenar en UTC y mostrar en hora local coherente.
- Archivos estáticos: WhiteNoise en MIDDLEWARE y STATIC_ROOT definido para poder colectar/servir CSS/JS del admin y de la app.
- CORS: habilitado (seguro en LAN) cuando el front se sirve desde otro origen (Angular/Ionic).
- REST Framework: permisos por defecto conservadores y relajados en los endpoints públicos (p. ej., ingesta de tags) según necesidad del prototipo.

### Despliegue y servicio (producción en la Pi)

- Gunicorn ejecuta el proyecto Django en 0.0.0.0:5000, permitiendo acceso desde la LAN.
- systemd gestiona un servicio llamado sicap.service:
  - Se inicia automáticamente al encender la Pi.
  - Reinicia el proceso si se cae.
  - Depende de la red (arranca cuando la red está disponible).
- WhiteNoise sirve estáticos (admin y front compilado si se integra) sin necesidad de Nginx.
- Logs: se consumen con journalctl para ver peticiones y errores en tiempo real, útil para diagnóstico con el ESP32 y la web app.

Resultado: el servidor queda siempre prendido y listo para recibir lecturas y atender la web sin intervención manual.

### Endpoints principales del backend (visión funcional)

- Ingesta de tags (/api/v1/register/tag/):
  - Método: POST (desde ESP32).
  - Cuerpo: JSON con "tag".
  - Efecto: crea un RegistroTag y responde estado.
- Listado rápido para la web (/api/v1/register/tag/list/):
  - Método: GET.
  - Devuelve: id, tag, nombre, categoria y created_at (hora local formateada).
- Edición/Personalización (/api/v1/register/tag/<id>/editar/):
  - Método: PUT/PATCH.
  - Cuerpo: puede incluir "nombre" y/o "categoria".
  - Efecto: actualiza el registro (sin cambiar el tag salvo que se envíe explícitamente).
- Admin de Django (/admin/):
  - Gestión visual de RegistroTag, usuarios, etc., pensado para desarrollo/soporte.

(Otros endpoints de usuarios_login/ permiten login y altas simples de usuarios en el entorno del prototipo.)

### Interacción de módulos

- ESP32 → Raspberry (Django): El microcontrolador envía un POST con el tag leído; el backend registra el evento con timestamp y opcionalmente lo muestra nombrado si se personalizó previamente.
- Web App → Raspberry (Django): La web consulta el listado para renderizar tablas y llama a editar para asignar nombre/categoria a cada tag.

### Consideraciones de operación y mantenimiento

- Hora correcta: la Pi usa la zona America/Argentina/Buenos_Aires y sincroniza por NTP; la API convierte la hora a local al exponer created_at.
- Resiliencia: systemd mantiene el servicio arriba; los logs permiten diagnóstico rápido.
- Seguridad: en LAN, CORS habilitado para el front; en despliegues más abiertos conviene limitar orígenes y activar autenticación para endpoints críticos.
- Escalabilidad: la base SQLite del prototipo es migrable a PostgreSQL/MariaDB; el esquema y el uso de Django/DRF permiten extender modelos (p. ej., entidad Herramienta/Usuario con relaciones) sin romper APIs existentes.

### Conclusión

La Raspberry Pi se configuró como servidor de producción liviano: Django + DRF para la lógica y APIs, Gunicorn como WSGI, WhiteNoise para estáticos y systemd para autoarranque y recuperación. Esta arquitectura hace que SICAP sea confiable (siempre disponible), mantenible (logs y admin) y extensible (campos nombre y categoria, nuevos modelos y vistas) dentro de un contexto escolar/industrial ligero.

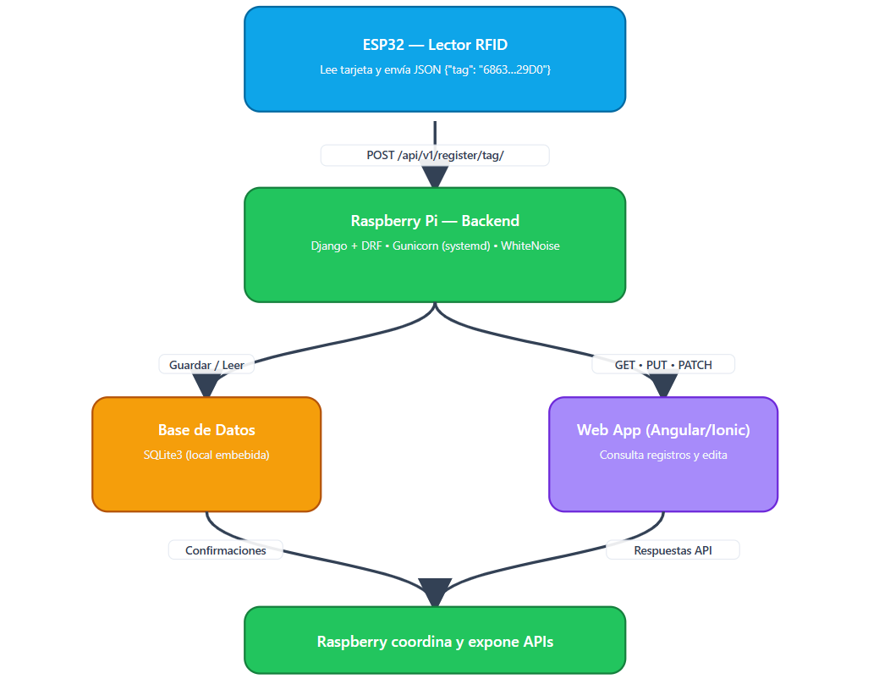
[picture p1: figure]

Figura 5.2: Flujo de comunicación en el módulo Raspberry Pi. El ESP32 captura el tag RFID y lo envía mediante una petición POST al servidor Django corriendo en la Raspberry Pi (gestionado por Gunicorn y systemd). El backend procesa y almacena los datos en la base de datos SQLite3 y expone endpoints REST. La Web App (Angular/Ionic) consume estos endpoints para consultar los registros y permitir operaciones como edición o gestión de los tags.

### 5.3 Módulo Router (Red Interna)

El router dedicado para la red interna de SICAP es un componente sencillo pero fundamental para la comunicación entre los demás módulos. Sus funciones principales son:

- Proveer una red WiFi local segura (SSID propio y contraseña) para conectar el ESP32 y la Raspberry Pi (y eventualmente dispositivos clientes).
- Asignar direcciones IP locales y enrutar la comunicación dentro de la LAN.
- Aislar el sistema de la red institucional general o de internet, salvo que se requiera lo contrario, para mayor seguridad y estabilidad.

Configuración realizada:

- Se utilizó un router TP-Link TL-WR840N (por ejemplo) operando en modo estándar (NAT activado, servidor DHCP activo). Se configuró el SSID = “SICAP” y clave WPA2-PSK = “graciasamigo” (como se ve en el código WiFi del ESP32) para que ambos dispositivos pudieran autenticarse inalámbricamente.
- Rango IP: Se definió el rango 192.168.111.1 – 192.168.111.254 para la red. El router tomó la IP 192.168.111.1. Esto se hizo para evitar colisión con otras redes comunes (como 192.168.0.x o 192.168.1.x) y distinguir claramente la subred de SICAP.
- DHCP: Activo en el router, entregando IPs automáticamente. Sin embargo, se reservó una IP fija para la Raspberry Pi para facilitar su localización. En las opciones DHCP del router, se asoció la dirección MAC de la Raspberry Pi a la IP 192.168.111.218 (en el prototipo). Así, cada vez que la Pi se conecta, recibe esa IP. Esto es importante porque el ESP32 necesita conocer a qué IP enviar los datos. Alternativamente, se pudo configurar la IP estática directamente en la Raspberry Pi, pero la reserva DHCP es conveniente centralmente.
- Puerto de servidor: El backend corre en el puerto 8000. Dentro de la LAN, no se requiere abrir puertos manualmente ya que el tráfico es local. Si se quisiera acceder desde fuera (por ejemplo monitorear desde internet), habría que configurar port forwarding (redireccionar el puerto 8000 a la IP de la Pi) y asegurarse de seguridad (idealmente VPN o firewall, ya que exponerlo públicamente no es recomendable sin auth fuerte). En este proyecto escolar, se decidió no exponer externamente el servidor.
- Sin conexión a internet: El router puede estar desconectado de internet (no tiene WAN). Todos los servicios funcionan offline. Esto es deliberado para que la dependencia sea nula de factores externos. Adicionalmente, al no haber salida a internet, se previene que el ESP32 intente resoluciones DNS o actualizaciones. Todo se maneja por IP locales. (Nota: Durante desarrollo, a veces se conectó temporalmente el router a internet para instalar paquetes en la Pi; pero en producción no haría falta.)

Cobertura WiFi y posicionamiento: El router se colocó en proximidad del pañol para garantizar buena señal. Tanto la Raspberry Pi como el ESP32 estaban en rango (unos pocos metros). El ESP32 en particular, con antena integrada, tenía señal fuerte a esa distancia. Si el pañol estuviera en un taller grande, se puede considerar ubi car el router en un punto central o usar extensores, pero usualmente la cobertura de un router hogareño es suficiente para un área de decenas de metros.

Seguridad de la red: Con WPA2 se asegura que solo personal autorizado con la contraseña pueda unirse. No se entregó la clave a cualquiera, solo al equipo del proyecto y docentes responsables, para evitar intrusos en la red. Por otro lado, dentro de la LAN, el protocolo de envío de tags es sin cifrar (HTTP plano). Esto fue considerado aceptable ya que para interceptarlo alguien tendría que haber roto la WiFi primero. Una mejora sería usar HTTPS incluso en LAN (certificado autofirmado en Pi), pero implica complejidad adicional de manejo de certs en MicroPython. Otra medida implementada: el endpoint de recibir tag está oculto tras /api/v1/ sin anuncio público, y la app web de gestión requiere login. Con esto, aunque alguien se conecte a la WiFi, no puede alterar datos fácilmente.

Configuración de red en Raspberry Pi: La Pi se configuró para usar la IP fija al boot (via DHCP reservado). También se editó el hostname a “sicap-server” para identificarla en la red. El archivo /etc/hosts se ajustó para que sicap-server resolviera a 192.168.111.218 localmente. Esto permitió, por ejemplo, que en el navegador de un cliente se pudiera teclear http://sicap-server:8000 en vez de memorizar la IP (alternativamente se podría usar mDNS/Bonjour con hostname.local). Este detalle es opcional pero aporta comodidad.

Pruebas del router y red: Se verificó que:

- El ESP32 obtenía IP (usando wlan.ifconfig() se pudo ver su IP, máscara, gateway).
- El ESP32 podía hacer ping al Raspberry Pi y viceversa (MicroPython no tiene ping fácil, pero se deduce por el éxito de las peticiones HTTP).
- Latencia en la LAN < 2 ms, pérdidas 0%. Esto asegura que los POSTS del ESP32 llegan casi instantáneamente.
- En la Raspberry Pi, se pudo resolver nombres si se necesitaba (aunque sin internet, solo es relevante para mDNS).
- No hubo interferencias ya que se usó un canal WiFi poco congestionado (el router en canal 6, y se aisló de otras redes cercanas).

En resumen, el router configura un entorno de red controlado para que los dispositivos de SICAP se comuniquen de forma eficiente y segura. Para replicar el proyecto, cualquier router inalámbrico básico sirve, siempre que se configure el SSID/password esperados y se fije la IP del servidor. En caso de modificar esos datos, recordar cambiarlos también en el código del ESP32 y en la documentación.

### 5.4 Backend en Django (Lógica del Servidor)

El backend de SICAP está construido con Django y Django REST Framework (DRF). Expone endpoints REST para:

1. recibir lecturas RFID desde el ESP32,
2. listar/editar esas lecturas,
3. administrar Pañoles (perfiles/espacios del sistema) consumidos por la web-app (Ionic/Angular).

La API está versionada bajo /api/v1/ y entrega/acepta JSON.

## 5.4.1 Estructura de proyecto (módulo registros)

sicap_backend/ # Proyecto Django

├─ sicap_backend/

│ ├─ settings.py # Config global (CORS/CSRF/DRF, apps)

│ └─ urls.py # Monta /api/v1/ → registros.urls

└─ registros/ # App de RFID + Pañoles

├─ models.py # Modelos de datos

├─ serializer.py # Serializadores DRF

├─ views.py # Vistas (funcionales) y ViewSets (DRF)

├─ urls.py # Router + endpoints

└─ admin.py # Registro en Django Admin

El versionado en /api/v1/ permite agregar breaking changes en /api/v2/ sin romper integraciones vigentes.

## 5.4.2 Modelos de datos

### RegistroTag

Representa una lectura RFID.

# registros/models.py

from django.db import models

from django.utils import timezone

class RegistroTag(models.Model):

nombre = models.CharField(max_length=100, blank=True, null=True)

tag = models.CharField(max_length=100, db_index=True)

fecha_hora = models.DateTimeField(default=timezone.now)

categoria = models.CharField(max_length=100, blank=True, null=True)

def __str__(self):

return f"{self.tag} - {self.fecha_hora:%Y-%m-%d %H:%M:%S}"

- tag está indexado para consultas rápidas (p. ej. filtrar por tag).
- nombre/categoria permiten anotar lecturas (ej: T99999 → “Taladro”, U12345 → “Juan Pérez”).
- fecha_hora usa timezone.now para generar un timestamp en el servidor (evita depender del reloj del dispositivo).

### Panol

Espacio/“perfil” administrable en el menú.

# registros/models.py

class Panol(models.Model):

nombre = models.CharField(max_length=100, unique=True)

icono = models.CharField(max_length=50, default='cube')

def __str__(self):

return self.nombre

- nombre es único (dos pañoles no deben llamarse igual).
- icono acompaña el estilo tipo “Netflix” del front.

Extensibilidad: si más adelante necesitás “Herramienta” o “Operario”, se agregan modelos relacionados (FK) sin tocar los contratos existentes.

## 5.4.3 Serializer (DRF)

Los serializers definen el contrato JSON expuesto/aceptado por la API.

# registros/serializer.py

from rest_framework import serializers

from .models import Panol, RegistroTag

class PanolSerializer(serializers.ModelSerializer):

class Meta:

model = Panol

fields = ['id', 'nombre', 'icono']

class RegistroTagSerializer(serializers.ModelSerializer):

# Alias de fecha_hora para el front: campo sólo lectura

created_at = serializers.DateTimeField(source='fecha_hora', read_only=True)

class Meta:

model = RegistroTag

fields = ['id', 'tag', 'nombre', 'categoria', 'fecha_hora', 'created_at']

Notas de diseño:

- Se introduce created_at como alias de fecha_hora porque el front lo consume con ese nombre.
- created_at es read-only (la fuente de verdad es fecha_hora).

## 5.4.4 Vistas y ViewSets

El módulo combina:

- Vistas funcionales (para hardware/ESP32 donde conviene deshabilitar CSRF), y
- ViewSets de DRF (CRUD REST completo para entidades como Panol).

### A) Endpoints “simples” (funcionales)

from django.http import JsonResponse
from django.views.decorators.http import require_GET
from rest_framework.decorators import api_view, permission_classes
from django.views.decorators.csrf import csrf_exempt, ensure_csrf_cookie
from django.db.models import F
from django.utils.timezone import localtime
from django.utils import timezone
from rest_framework.response import Response
from rest_framework import status
from rest_framework import viewsets, mixins, status
from rest_framework.viewsets import ModelViewSet
from rest_framework.decorators import api_view, permission_classes
from rest_framework.permissions import IsAuthenticatedOrReadOnly, AllowAny
from .models import RegistroTag, Panol, Asignacion
from django.shortcuts import get_object_or_404
from .serializer import PanolSerializer, RegistroTagSerializer, AsignacionSerializer
import json

@csrf_exempt
def recibir_tag(request):
if request.method == 'POST':
try:
data = json.loads(request.body)
tag = data.get('tag')
print(tag)
if tag:
RegistroTag.objects.create(tag=tag)
return JsonResponse({'status': 'ok'})
else:
return JsonResponse({'error': 'tag faltante'}, status=400)
except Exception as e:
return JsonResponse({'error': str(e)}, status=500)

return JsonResponse({'error': 'método no permitido'}, status=405)

@csrf_exempt
def editar_tag(request, id):
if request.method == 'PUT':
tag_obj = get_object_or_404(RegistroTag, pk=id)
data = json.loads(request.body or "{}")

if 'nombre' in data:
tag_obj.nombre = data['nombre']

if 'categoria' in data:
raw = data['categoria']
if raw in (None, '', 'null'):
tag_obj.categoria = None
else:
categoria = str(raw).lower().strip()
if categoria not in ['persona', 'insumo']:
return JsonResponse({
'error': 'valor de categoría inválido. Debe ser "persona" o "insumo".'
}, status=400)
tag_obj.categoria = categoria

tag_obj.save()
return JsonResponse({
'status': 'ok',
'id': tag_obj.id,
'nombre': tag_obj.nombre,
'categoria': tag_obj.categoria,
})
return JsonResponse({'error': 'Método no permitido'}, status=405)

@ensure_csrf_cookie
def csrf_ping(request):

return JsonResponse({"detail": "ok"})

@require_GET
def listar_tags(request):
rows = list(
RegistroTag.objects
.order_by("-fecha_hora")
.values("id", "tag", "nombre", "fecha_hora", "categoria")[:200]
)
for r in rows:
r["created_at"] = localtime(r["fecha_hora"]).strftime("%Y-%m-%d %H:%M:%S")
del r["fecha_hora"]

return JsonResponse(rows, safe=False)


@api_view(['POST'])
@permission_classes([AllowAny])
def assignments_auto(request):
data = request.data or {}
persona_tag = str(data.get('persona_tag', '')).strip()
persona_nombre = (data.get('persona_nombre') or '').strip() or None
items = data.get('items') or []

if not persona_tag or not items:
return Response({'error': 'persona_tag e items son obligatorios'}, status=400)

asignados, devueltos = []

for it in items:
item_tag = str((it or {}).get('tag', '')).strip()
item_nombre = ((it or {}).get('nombre') or '').strip() or None
if not item_tag:
continue


a = Asignacion.objects.filter(persona_tag=persona_tag, item_tag=item_tag, activo=True).first()

if a:

a.activo = False
a.devuelto_en = timezone.now()
a.save(update_fields=['activo', 'devuelto_en'])
devueltos.append({
'id': a.id,
'item_tag': item_tag,
'item_nombre': item_nombre or a.item_nombre,
'devuelto_en': a.devuelto_en,
})
else:
Asignacion.objects.filter(item_tag=item_tag, activo=True).update(
activo=False,
devuelto_en=timezone.now()
)

a = Asignacion.objects.create(
persona_tag=persona_tag,
persona_nombre=persona_nombre,
item_tag=item_tag,
item_nombre=item_nombre,
asignado_en=timezone.now(),
activo=True
)
asignados.append({
'id': a.id,
'item_tag': item_tag,
'item_nombre': item_nombre,
'asignado_en': a.asignado_en,
})

return Response({
'status': 'ok',
'persona_tag': persona_tag,
'persona_nombre': persona_nombre,
'asignados': asignados,
'devueltos': devueltos,
'total_asignados': len(asignados),
'total_devueltos': len(devueltos),
}, status=200)


@api_view(['GET'])
@permission_classes([AllowAny])
def assignments_list(request):
qs = Asignacion.objects.all().order_by('-asignado_en')
activo = request.GET.get('activo')
if activo is not None:
qs = qs.filter(activo=(str(activo).lower() in ['1','true','t','yes','y']))
persona_tag = request.GET.get('persona_tag')
if persona_tag:
qs = qs.filter(persona_tag=persona_tag)
ser = AsignacionSerializer(qs, many=True)
return Response(ser.data)


@api_view(['PUT'])
@permission_classes([AllowAny])
def assignments_devolver(request, pk: int):
a = Asignacion.objects.filter(pk=pk, activo=True).first()
if not a:
return Response({'error': 'asignación no encontrada o ya devuelta'}, status=404)
a.activo = False
a.devuelto_en = timezone.now()
a.save()
return Response(AsignacionSerializer(a).data)



class PanolViewSet(ModelViewSet):
queryset = Panol.objects.all().order_by('nombre')
serializer_class = PanolSerializer
permission_classes = [AllowAny]

class RegistroTagViewSet(mixins.CreateModelMixin, mixins.ListModelMixin,viewsets.GenericViewSet):

queryset = RegistroTag.objects.all().order_by('-fecha_hora')
serializer_class = RegistroTagSerializer
permission_classes = [AllowAny]

#### 1) Recibir lectura RFID (ESP32)

@csrf_exempt

def recibir_tag(request):

"""POST JSON {"tag": "..."} desde ESP32."""

if request.method == 'POST':

try:

data = json.loads(request.body or "{}")

tag = data.get('tag')

if not tag:

return JsonResponse({'error': 'tag faltante'}, status=400)

RegistroTag.objects.create(tag=tag)

return JsonResponse({'status': 'ok'})

except Exception as e:

return JsonResponse({'error': str(e)}, status=500)

return JsonResponse({'error': 'método no permitido'}, status=405)

- CSRF: exento para que un microcontrolador pueda postear sin headers especiales.
- Contratos: espera {"tag": "..."}; responde {"status":"ok"} o {"error": "..."}
- Códigos HTTP: 200, 400 (validación), 405 (método), 500 (excepción).

#### 2) Listar últimas lecturas (para la web-app)

@require_GET
def listar_tags(request):
"""Últimos 200 registros, con 'created_at' (alias de fecha_hora)."""
rows = list(
RegistroTag.objects
.order_by("-fecha_hora")
.values("id", "tag", "nombre", "fecha_hora", "categoria")[:200]
)
for r in rows:
r["created_at"] = localtime(r["fecha_hora"]).strftime("%Y-%m-%d %H:%M:%S")
del r["fecha_hora"]
return JsonResponse(rows, safe=False)

- Se expone un array JSON ya con created_at en formato legible.
- Se limita a 200 para evitar respuestas gigantes.

#### 3) Anotar/editar una lectura

@csrf_exempt
def editar_tag(request, id):
"""PUT JSON {"nombre": "...", "categoria": "..."} para anotar un tag."""
if request.method == 'PUT':
tag_obj = get_object_or_404(RegistroTag, pk=id)
data = json.loads(request.body or "{}")
if 'nombre' in data:
tag_obj.nombre = data['nombre']
if 'categoria' in data:
tag_obj.categoria = data['categoria']
tag_obj.save()
return JsonResponse({
'status': 'ok',
'id': tag_obj.id,
'nombre': tag_obj.nombre,
'categoria': tag_obj.categoria,
})
return JsonResponse({'error': 'Método no permitido'}, status=405)

- Permite asignar alias y categoría a una lectura específica.
- Respuesta compacta con el estado final del recurso.

#### 4) CSRF “ping” para inicializar cookies (web-app)

@ensure_csrf_cookie
def csrf_ping(request):
"""Deja cookie CSRF para la web-app."""
return JsonResponse({"detail": "ok"})

- Útil para Angular/Ionic con HttpClientXsrfModule (el navegador guarda cookie y Angular la reenvía en X-CSRFToken).

### B) ViewSets (DRF)

#### PanolViewSet (CRUD REST)

class PanolViewSet(ModelViewSet):
"""CRUD de pañoles para el menú."""
queryset = Panol.objects.all().order_by('nombre')
serializer_class = PanolSerializer
permission_classes = [AllowAny] # endurecer en producción

def create(self, request, *args, **kwargs):
# Evitar duplicados por nombre
nombre = (request.data.get("nombre") or "").strip()
if not nombre:
return Response({"detail": "nombre requerido"},
status=status.HTTP_400_BAD_REQUEST)
icono = request.data.get("icono") or "cube"
obj, created = Panol.objects.get_or_create(
nombre=nombre, defaults={"icono": icono}
)
ser = self.get_serializer(obj)
return Response(ser.data,
status=status.HTTP_201_CREATED if created else status.HTTP_200_OK)

Contratos:

- GET /api/v1/panoles/ → [{id, nombre, icono}, ...]
- POST /api/v1/panoles/ body {"nombre":"...", "icono":"..."} → 201 Created o 200 OK si ya existía.
- PUT/PATCH/DELETE por id (si el front luego los implementa).

#### RegistroTagViewSet (opcional DRF)

class RegistroTagViewSet(mixins.CreateModelMixin,
mixins.ListModelMixin,
viewsets.GenericViewSet):
"""Listar/crear registros vía DRF (alternativa a endpoints simples)."""
queryset = RegistroTag.objects.all().order_by('-fecha_hora')
serializer_class = RegistroTagSerializer
permission_classes = [AllowAny]

- Alternativa REST “pura” a recibir_tag/listar_tags. Útil si el front prefiere un único estilo.

## 5.4.5 Mapeado de Rutas (URLConf)

from django.urls import path, include
from rest_framework.routers import DefaultRouter
from rest_framework import routers
from .views import recibir_tag, listar_tags, PanolViewSet, csrf_ping, RegistroTagViewSet, editar_tag, assignments_list, assignments_auto, assignments_devolver

router = DefaultRouter()
router.register(r'panoles', PanolViewSet, basename='panoles')
router.register(r'tags', RegistroTagViewSet, basename='register-tag')

urlpatterns = [
path('auth/csrf/', csrf_ping,name='csrf-ping'),
path('', include (router.urls)),
path('register/tag/', recibir_tag, name= "recibir-tag"),
path('register/tag/list/', listar_tags, name="listar-tags"),
path('register/tag/<int:id>/editar/', editar_tag, name="editar-tag"),
path('assignments/', assignments_list, name='assignments_list'),
path('assignments/auto/', assignments_auto, name='assignments_auto'),
path('assignments/<int:pk>/devolver/', assignments_devolver, name='assignments_devolver'),
]

urlpatterns += router.urls

Criterio: Se mantiene un estilo híbrido por necesidades del hardware (endpoints simples, sin CSRF) y del front (ViewSets DRF limpios).

## 5.4.6 Formato de datos (contratos)

### Lectura RFID — POST /api/v1/register/tag/

Request

{ "tag": "68630808080235D0" }

Response

{ "status": "ok" }

Errores

{ "error": "tag faltante" } // 400
{ "error": "..." } // 500

### Listado de lecturas — GET /api/v1/register/tag/list/

Response

[
{
"id": 183,
"tag": "68630808080235D0",
"nombre": "Taladro",
"categoria": "herramienta",
"created_at": "2025-09-20 10:09:13"
},
...
]

### Editar una lectura — PUT /api/v1/register/tag/183/editar/

Request

{ "nombre": "Martillo", "categoria": "herramienta" }

Response

{ "status": "ok", "id": 183, "nombre": "Martillo", "categoria": "herramienta" }

### Pañoles — GET/POST /api/v1/panoles/

POST Request

{ "nombre": "Pañol Principal", "icono": "cube" }

POST Response (201 o 200 si ya existía)

{ "id": 1, "nombre": "Pañol Principal", "icono": "cube" }

## 5.4.7 CSRF y CORS (integración con Angular/Ionic)

- Los endpoints DRF (como /panoles/) requieren CSRF si se usan cookies/sesiones.
- Flujo típico del front:
  1. Llamar a /api/v1/auth/csrf/ para que el servidor envíe la cookie csrftoken.
  2. Angular, con HttpClientXsrfModule, reenvía esa cookie como header X-CSRFToken automáticamente.
  3. A partir de ahí, POST/PUT/DELETE funcionan sin fricción.
- CORS: en settings.py se definen los orígenes permitidos del front (ej. http://localhost:4200, http://raspberrypi.local:4200).

Los endpoints del ESP32 están exentos de CSRF por diseño (@csrf_exempt), ya que un microcontrolador no maneja cookies/headers de navegador.

## 5.4.8 Seguridad y permisos

- En desarrollo, los ViewSets usan AllowAny por practicidad.
- En producción, se recomienda:
  - IsAuthenticated o IsAdminUser según el caso,
  - separar endpoints de ingesta IoT (permitidos por IP/red interna o con token precompartido),
  - limitar editar_tag a usuarios autenticados/autorizados.

Ejemplo (endurecer panoles):

# views.py

from rest_framework.permissions import IsAuthenticated

class PanolViewSet(ModelViewSet):
permission_classes = [IsAuthenticated]

## 5.4.9 Administración (Django Admin)

# registros/admin.py

from django.contrib import admin
from .models import Panol, RegistroTag

@admin.register(Panol)
class PanolAdmin(admin.ModelAdmin):
list_display = ("id", "nombre", "icono")
search_fields = ("nombre",)

@admin.register(RegistroTag)
class RegistroTagAdmin(admin.ModelAdmin):
list_display = ("id", "tag", "nombre", "categoria", "fecha_hora")
search_fields = ("tag", "nombre", "categoria")
list_filter = ("categoria", "fecha_hora")

- Permite verificar en segundos que las lecturas llegan y que los pañoles existen, sin depender del front.

## 5.4.10 Extensión prevista (futuro cercano)

- Modelo Herramienta: tag (FK opcional a RegistroTag o CharField), nombre, estado, pertenece_a = FK Panol.
- Modelo Movimiento: agrupar lecturas cercanas (usuario + herramienta ± ventana de segundos) para inferir retiro/devolución.
- Reglas de negocio: alertas por no devolución, bloqueo de herramientas sensibles, trazabilidad por usuario y pañol.
- Paginación DRF y filtros (por fecha/tag/categoría/panol).
- Autenticación basada en sesiones o JWT para paneles de gestión.

### Conclusión del Funcionamiento del Backend:

Con los fragmentos anteriores, el módulo del backend queda:

- Autodocumentado (contratos JSON claros),
- Estable (versionado, validaciones básicas),
- Listo para el front (campos, alias created_at, CSRF/CORS),
- Escalable (nuevos modelos y viewsets sin romper el existente).

### 5.5 Aplicación Web (Interfaz de Gestión de Insumos y Usuarios)

La capa de interfaz de SICAP se implementa como una SPA con Ionic + Angular y consume la API REST de Django. Este apartado documenta la arquitectura, el flujo entre pantallas (Login → Menú de usuarios → Home por usuario), el manejo de cookies/CSRF para operaciones de escritura, y los fragmentos esenciales de código que materializan cada función.

## 5.5.1 Tecnologías y organización

Stack UI

- Ionic Framework (componentes móviles responsivos).
- Angular (enrutado, módulos, DI, HttpClient).
- TypeScript (lógica de componentes/servicios).
- HTML5 + SCSS (maquetación, estilos).
- RxJS (polling y composición de flujos).

Estructura relevante

src/
app/
login/ # Pantalla de autenticación
menu/ # Selección/creación de usuarios (perfiles)
home/ # Panel por usuario, con secciones internas
app-routing.module.ts
app.module.ts
assets/ # Imágenes, logos, animación MP4/Lottie
environments/
environment.ts # API_BASE (dev)
environment.prod.ts # API_BASE (prod)
global.scss

Configuración de entorno (única fuente de verdad para la API)

// environments/environment.ts

export const environment = {
production: false,
API_BASE: 'http://raspberrypi.local:5000/api/v1/' // terminar SIEMPRE con /
};

Módulos Angular utilizados

- HttpClientModule para llamadas a la API.
- FormsModule / IonicModule para formularios y UI.

## 5.5.2 Login (autenticación inicial)

Objetivo. Validar credenciales contra el backend y, en caso de éxito, navegar al Menú de usuarios. En esta versión no se persiste token; la verificación es stateless (se procesa la respuesta y se redirige).

Interfaz. Formulario minimalista con 2 campos (username, password) y botón de envío. Se aplican estilos de Ionic y, opcionalmente, una animación de fondo (Lottie o video MP4 en assets/).

Flujo.

1. El usuario completa el formulario.
2. POST /usuarios/login/ con { username, password }.
3. Si la respuesta es { success: true }, se navega a /menu.

Fragmentos esenciales

HTML:

<ion-header [translucent]="true" *ngIf="animacionTerminada">
</ion-header>

<ion-content [fullscreen]="true">

<div *ngIf="!animacionTerminada" class="splash-container">
<lottie-player
src="assets/Animaciones/animacion.login.json"
background="transparent"
speed="1"
autoplay
(complete)="onAnimationComplete()">
</lottie-player>
</div>

<div *ngIf="animacionTerminada" class="login-content ion-padding">

<div class="logo-container">
<img src="assets/Images/Sicap-grande.png" alt="Logo SICAP" />
</div>

<ion-card>
<ion-card-content>
<form (ngSubmit)="login()">
<ion-item>
<ion-icon name="person-outline" slot="start" color="medium"></ion-icon>
<ion-label position="floating">Usuario</ion-label>
<ion-input type="text" [(ngModel)]="username" name="username"></ion-input>
</ion-item>

<ion-item>
<ion-icon name="lock-closed-outline" slot="start" color="medium"></ion-icon>
<ion-label position="floating">Contraseña</ion-label>
<ion-input type="password" [(ngModel)]="password" name="password"></ion-input>
</ion-item>

<br>

<ion-button type="submit" expand="block" shape="round">
Ingresar
<ion-ripple-effect></ion-ripple-effect>
</ion-button>
</form>
</ion-card-content>
</ion-card>
</div>

</ion-content>


TypeScript:
import { Component } from '@angular/core';

import { NavController, AlertController, LoadingController } from '@ionic/angular';

@Component({
selector: 'app-login',
templateUrl: './login.page.html',
styleUrls: ['./login.page.scss'],
standalone: false,
})
export class LoginPage {

animacionTerminada: boolean = false;
username = '';
password = '';


constructor(
private navCtrl: NavController,
private alertCtrl: AlertController,
private loadingCtrl: LoadingController
) { }

onAnimationComplete() {
this.animacionTerminada = true;
}

async login() {

const loading = await this.loadingCtrl.create({
message: 'Verificando...',
});
await loading.present();

try {
const response = await fetch('http://192.168.111.218:5000/usuarios/login/', {
method: 'POST',
headers: { 'Content-Type': 'application/json' },
body: JSON.stringify({ username: this.username, password: this.password })
});

await loading.dismiss();

if (!response.ok) {

throw new Error('Error en el servidor');
}

const data = await response.json();

if (data.success) {
this.navCtrl.navigateForward('/menu');
} else {

this.mostrarAlerta('Error de Login', data.message || 'Credenciales incorrectas.');
}
} catch (error) {

await loading.dismiss();
this.mostrarAlerta('Error de Conexión', 'No se pudo conectar con el servidor. Por favor, intente más tarde.');
}
}

async mostrarAlerta(titulo: string, mensaje: string) {
const alert = await this.alertCtrl.create({
header: titulo,
message: mensaje,
buttons: ['OK']
});
await alert.present();
}
}

Notas técnicas.

- withCredentials: true se deja habilitado desde el comienzo para mantener coherencia con endpoints que sí requieren cookie/CSRF.
- Si en el futuro se añade sesión basada en cookies o JWT, el punto de integración permanece encapsulado en este mismo método.

## 5.5.3 Menú de usuarios (creación y selección)

El Menú lista los usuarios/perfiles (modelo Pañol en el backend) y permite crear uno nuevo. La pantalla emula un “selector Netflix”: una tarjeta para “Crear Usuario” y tarjetas para cada perfil existente. Al seleccionar un perfil, se navega a su Home.

Requisitos de seguridad. Las operaciones de creación requieren CSRF:

- Antes de operar, se hace GET /api/v1/auth/csrf/ para plantar la cookie csrftoken.
- Peticiones subsecuentes que incluyan { withCredentials: true } enviarán X-CSRFToken automáticamente (con CORS y CSRF confiados correctamente configurados en el backend).

Flujo.

1. Al inicializar la página: GET /auth/csrf/ y luego GET /panoles/.
2. Creación: POST /panoles/ con { nombre, icono }.
3. Navegación: router.navigate(['/home', id]).

Fragmentos esenciales

TypeScript:

import { Component, OnInit } from '@angular/core';
import { HttpClient } from '@angular/common/http';
import { environment } from 'src/environments/environment';
import { Router } from '@angular/router';

type Panol = { id?: number; nombre: string; icono?: string };

@Component({
selector: 'app-menu',
templateUrl: './menu.page.html',
styleUrls: ['./menu.page.scss'],
standalone: false,
})
export class MenuPage implements OnInit {
private API_BASE = environment.API_BASE;
private PANOLES_URL = `${this.API_BASE}panoles/`;
private CSRF_PING_URL = `${this.API_BASE}auth/csrf/`;

panoles: Panol[] = [];
loading = false;
error?: string;

creating = false;
nombreNuevo = '';
saving = false;

constructor(private http: HttpClient, private router: Router) {}

ngOnInit() {
// 1) Plantar cookie CSRF y luego cargar pañoles
this.http.get(this.CSRF_PING_URL, { withCredentials: true }).subscribe({
next: () => this.cargar(),
error: () => this.cargar(), // aunque falle, intento cargar
});
}

cargar() {
this.loading = true;
this.error = undefined;

console.log('👉 PANOLES_URL =', this.PANOLES_URL);

this.http.get<any>(this.PANOLES_URL, { withCredentials: true }).subscribe({
next: (res) => {
this.panoles = Array.isArray(res) ? res : (res?.results ?? []);
this.loading = false;
},
error: () => {
this.error = 'No pude cargar los pañoles';
this.loading = false;
},
});
}

abrirCrear() {
this.nombreNuevo = '';
this.creating = true;
}

cancelarCrear() {
this.creating = false;
this.nombreNuevo = '';
}

crear() {
const nombre = this.nombreNuevo.trim();
if (!nombre) return;

this.saving = true;

this.http
.post<Panol>(
this.PANOLES_URL,
{ nombre, icono: 'cube' },
{ withCredentials: true }
)
.subscribe({
next: (p) => {
this.saving = false;
this.creating = false;
this.nombreNuevo = '';
// lo muestro al toque
this.panoles.unshift(p);
},
error: () => {
this.saving = false;
this.error = 'No pude crear el pañol';
},
});
}

abrirPanol(p: Panol) {
if (!p.id) return;
this.router.navigate(['/home', p.id]);
}
}



HTML:
<ion-content [fullscreen]="true" class="page">
<div class="wrap">

<div class="center" *ngIf="loading"><ion-spinner></ion-spinner></div>
<ion-text color="danger" class="center" *ngIf="!loading && error">{{ error }}</ion-text>

<section class="grid" *ngIf="!loading">

<article class="card new" (click)="abrirCrear()">
<div class="poster plus">+</div>
<div class="name">Crear Usuario</div>
</article>

<article class="card" *ngFor="let p of panoles">
<button class="poster" (click)="abrirPanol(p)">
<ion-icon [name]="'cube'"></ion-icon>
</button>
<div class="name">{{ p.nombre }}</div>
</article>
</section>

<ion-modal mode="md" cssClass="tarjeta-modal" [isOpen]="creating" (didDismiss)="cancelarCrear()" [presentingElement]="null">
<ng-template>
<ion-header>
<ion-toolbar>
<ion-title>Personalizar</ion-title>
<ion-buttons slot="end">
<ion-button (click)="cancelarCrear()" class="btn-close">
<ion-icon name="close-outline"></ion-icon>
</ion-button>
</ion-buttons>
</ion-toolbar>
</ion-header>
<ion-content class="ion-padding">
<ion-item>
<ion-input label="Nombre" labelPlacement="floating" [(ngModel)]="nombreNuevo"></ion-input>
</ion-item>
<div class="row mt">
<ion-button [disabled]="saving || !nombreNuevo.trim()" (click)="crear()">Crear</ion-button>
<ion-button fill="clear" (click)="cancelarCrear()">Cancelar</ion-button>
</div>
<ion-text color="danger" *ngIf="error">{{ error }}</ion-text>
</ion-content>
</ng-template>
</ion-modal>

</div>
</ion-content>

El diseño de cuadrícula se resuelve con SCSS local (tarjetas, poster circular/ícono, hover, etc.), manteniendo la estética “selector de perfiles”.

## 5.5.4 Home por usuario (secciones internas)

El Home se instancia por ruta (/home/:panolId) y concentra cuatro secciones:

- Interfaz Visual (clasificación en tiempo real de tags “En Taller” vs “Fuera del Taller”).
- Inventario (vista única por tag con nombre/categoría).
- Empleados (listado orientado a personas).
- Personalización (reservado para ajustes).

Orígenes de datos.

- GET /api/v1/register/tag/list/ entrega los últimos registros en JSON.
- PUT /api/v1/register/tag/{id}/editar/ permite editar nombre y categoría de un registro.

Animación de fondo. Se utiliza un video MP4 (assets/Animaciones/animacion_sicap.mp4) en bucle, con superposición (.bg-overlay) para fortalecer contraste del contenido.

Interfaz Visual (lógica).

- Se mantiene en memoria un diccionario tagsEstado: { [tag]: 'taller' | 'fuera' }.
- Por cada nuevo registro de un tag:
  - Si el tag no existe aún → se coloca en En Taller.
  - Si estaba En Taller → pasa a Fuera del Taller.
  - Si estaba Fuera del Taller → regresa a En Taller.
- La sección se actualiza cada 3 segundos con RxJS interval.

Fragmentos (procesamiento y polling):

// home.page.ts (fragmento)

const BASE = environment.API_BASE.replace(/\/$/, '');
const API_LIST = `${BASE}/register/tag/list/`;
const API_EDIT = `${BASE}/register/tag`;

activarSeccion(nombre: string) {
this.seccionActiva = nombre;
if (nombre === 'Interfaz Visual') {
this.cargarRegistros();
this.sub = interval(3000).subscribe(() => this.cargarRegistros());
} else {
this.sub?.unsubscribe();
}
}

private procesarRegistro(nuevo: Registro) {
const tag = nuevo.tag;
const estado = this.tagsEstado[tag]; // 'taller' | 'fuera' | undefined
if (!estado) { this.tagsTaller.unshift(nuevo); this.tagsEstado[tag] = 'taller'; return; }
if (estado === 'taller') {
this.tagsTaller = this.tagsTaller.filter(t => t.tag !== tag);
this.tagsFuera.unshift(nuevo);
this.tagsEstado[tag] = 'fuera';
} else {
this.tagsFuera = this.tagsFuera.filter(t => t.tag !== tag);
this.tagsTaller.unshift(nuevo);
this.tagsEstado[tag] = 'taller';
}
}

cargarRegistros() {
this.http.get<Registro[]>(API_LIST).subscribe(rows => {
this.registros = rows;
rows.forEach(reg => {
const yaClasificado = this.tagsTaller.some(t => t.id === reg.id) || this.tagsFuera.some(t => t.id === reg.id);
if (!yaClasificado) this.procesarRegistro(reg);
});
});
}

Inventario (tags únicos).
Se deriva una colección sin duplicados por tag, conservando el más reciente:

// home.page.ts (fragmento)

get tagsUnicos(): Registro[] {
const vistos = new Set<string>();
const unicos: Registro[] = [];
for (let i = this.registros.length - 1; i >= 0; i--) {
const r = this.registros[i];
if (!vistos.has(r.tag)) { vistos.add(r.tag); unicos.unshift(r); }
}
return unicos;
}

Edición inline (nombre/categoría).
Desde Inventario o Empleados se abre un ion-alert con inputs y se envía un PUT:

// home.page.ts (fragmento)

editarTag(reg: Registro, nombre: string, categoria: string) {
this.http.put(`${API_EDIT}/${reg.id}/editar/`, { nombre, categoria })
.subscribe(() => { reg.nombre = nombre; reg.categoria = categoria; });
}

Estructura HTML (extractos clave).
Barra lateral para secciones + contenedor de tarjetas por columna:

<!-- home.page.html (fragmentos) -->
<div class="vertical-toolbar" [class.activa]="seccionActiva">
<ion-button *ngFor="let opcion of opcionesMenu"
[disabled]="opcion === seccionActiva"
(click)="activarSeccion(opcion)">{{ opcion }}</ion-button>
<ion-button color="medium" (click)="volverAlMenuCentral()">Volver</ion-button>
</div>

<!-- Interfaz Visual: dos columnas -->
<div class="cajas-tags" *ngIf="seccionActiva === 'Interfaz Visual'">
<div class="caja-tags">
<h3>En Taller</h3>
<ion-card *ngFor="let r of tagsTaller">...</ion-card>
</div>
<div class="caja-tags">
<h3>Fuera del Taller</h3>
<ion-card *ngFor="let r of tagsFuera">...</ion-card>
</div>
</div>

## 5.5.5 Enrutado

El ruteo conecta las tres pantallas principales y permite instanciar el Home por identificador de usuario:

// app-routing.module.ts (fragmento)

const routes: Routes = [
{ path: '', redirectTo: 'login', pathMatch: 'full' },
{ path: 'login', loadChildren: () => import('./login/login.module').then(m => m.LoginPageModule) },
{ path: 'menu', loadChildren: () => import('./menu/menu.module').then(m => m.MenuPageModule) },
{ path: 'home/:panolId', loadChildren: () => import('./home/home.module').then(m => m.HomePageModule) },
];

## 5.5.6 Estilos y composición visual

Video de fondo
El Home aplica un video en loop con superposición semitransparente para mejorar la legibilidad de tarjetas/labels:

/* home.page.scss (fragmento) */
.has-video-bg {
#bg-video {
position: fixed; inset: 0; width: 100%; height: 100%;
object-fit: cover; z-index: 0;
}
.bg-overlay {
position: fixed; inset: 0;
background: rgba(0,0,0,.35);
z-index: 1;
}
.vertical-toolbar, .visual-content, .botones-menu-central { z-index: 2; position: relative; }
}

Barra lateral y área de trabajo

/* home.page.scss (fragmento) */
.vertical-toolbar {
position: fixed; top: 56px; left: 0; width: 220px;
height: calc(100vh - 56px); padding: 10px; background: #888;
display: flex; flex-direction: column; gap: 8px;
}
.visual-content { margin-left: 220px; padding: 20px; }
.cajas-tags { display: grid; grid-template-columns: 1fr 1fr; gap: 16px; }

Grid del Menú (selector de usuarios)

/* menu.page.scss (fragmento) */
.grid { display: grid; grid-template-columns: repeat(auto-fill, minmax(160px,1fr)); gap: 16px; }
.card { display: grid; gap: 8px; text-align: center; }
.poster { aspect-ratio: 1/1; border-radius: 12px; display: grid; place-items: center; }
.plus { font-size: 48px; }

## 5.5.7 Cookies, CSRF y CORS (desde el frontend)

- CSRF: previo a POST/PUT/DELETE, se realiza GET /api/v1/auth/csrf/ para que el backend emita la cookie csrftoken.
- withCredentials: todas las llamadas que mutan estado se envían con { withCredentials: true } para que el navegador remita cookies y Angular agregue X-CSRFToken.
- CORS: el backend publica CORS_ALLOWED_ORIGINS y CSRF_TRUSTED_ORIGINS coherentes con el host del frontend. No se requiere configuración adicional en el cliente.

### Resumen funcional

1. Login valida credenciales y redirige a Menú.
2. Menú planta CSRF, lista usuarios y permite crear nuevos.
3. Home por usuario consume registros, actualiza la Interfaz Visual en tiempo real, muestra Inventario de tags únicos y permite edición inline (nombre/categoría).

La combinación de Angular (estructura y datos), Ionic (UI) y el contrato de API de Django (JSON simple con CSRF/credenciales) deja un frontend cohesionado, escalable y mantenible.

## 6. Base de Datos: Modelo Relacional, Migraciones y Pruebas

La base de datos de SICAP es el componente que almacena de forma permanente toda la información relevante del sistema: principalmente los registros de movimientos (lecturas RFID), así como datos de usuarios y potencialmente herramientas. Al ser un proyecto de alcance local y relativamente pequeño, se optó por un modelo de base de datos relacional sencillo usando SQLite, que viene integrado con Django.

Modelo de datos (relacional): A continuación se describe el esquema de tablas más importante. Para mejor visualización, se presenta en formato de tabla:

- registros_registrotag – (Tabla de los registros de tags leídos)  Columnas:  • id (Integer, PK, auto-incremental)  • tag (Text) – Almacena el identificador del tag RFID leído. Puede contener letras y números (en formato hex u otro). Ejemplos de valores: “4B01020304AABBCC”.  • fecha_hora (DateTime) – Marca temporal de cuándo se insertó el registro. Ej: “2025-10-03 14:22:10”.  Descripción: Cada fila representa una detección de una etiqueta RFID en el portal, registrada automáticamente al recibirse del ESP32. La combinación de tag + fecha_hora indica qué tag fue detectado y en qué momento exacto.
- auth_user – (Tabla de usuarios, estándar de Django)  Columnas principales: id, username, password (hashed), email, first_name, last_name, is_staff, is_superuser, etc.  Descripción: Almacena las cuentas de usuario para acceder al sistema web. Por defecto Django crea esta tabla. En nuestro caso, contendrá por ejemplo: usuario “admin” (superuser), y cualquier otro creado (p. ej. “juan”, “maria” para operarios con acceso a la web). Contraseñas en hash (no visibles). El campo is_staff se usa para permitir acceso al /admin; is_superuser para todos permisos.
- usuarios_login_pañol – (Tabla de pañoles administrados)  Columnas:  • id (PK)  • nombre (varchar(100)) – Nombre del pañol, ej: “Pañol Electrónica”.  • usuario_id (FK -> auth_user.id) – Referencia al usuario encargado de ese pañol.  Descripción: Si la institución tuviera múltiples pañoles (herramientas, insumos, biblioteca), esta tabla los lista y vincula cada uno a un usuario responsable. En el prototipo se podría tener una fila: nombre=“Pañol Taller”, usuario_id = (id de admin). Esto no se usó ampliamente en la lógica, pero sienta base para expansión multi-área.
- usuarios_login_programmer – (Tabla de programadores del proyecto, auxiliar)  Columnas: id, fullname (varchar(100)).  Descripción: Lista miembros del equipo de desarrollo. Este modelo no interactúa con el funcionamiento de SICAP en producción; fue más bien utilizado para registrar a los desarrolladores como parte del proyecto escolar. Se puede ignorar para replicación (no afecta funcionalidades).
- (Posibles tablas ausentes en esta versión):  Si se extendiera el modelo, podrían agregarse:  • herramientas_herramienta – con campos id, tag, nombre, descripcion, estado, etc.  • operarios_usuario – lista de personas que usan herramientas, si se quieren separar de la tabla auth_user (o se podría reutilizar auth_user con grupos/roles).  • prestamos_prestamo – tabla relacional que vincule herramienta, usuario, fecha_salida, fecha_entrada, etc., de modo explícito en vez de deducir de registros.  En la versión actual, estos no existen; en su lugar, la lógica se infiere de registros.

Migraciones: Django maneja las migraciones de esquema. En el repositorio, en registros/migrations/ se encuentra, por ejemplo, 0001_initial.py (creada al hacer makemigrations) que define la creación de la tabla RegistroTag. También hay 0002_rename_tag_id_registrotag_tag.py – esto sugiere que inicialmente el campo se llamaba tag_id y luego se renombró a tag. Efectivamente, el README menciona tag_id pero en código final quedó tag. Esta migración renombra la columna en la BD.

Al replicar, si se ejecuta migrate, Django aplicará directamente la última estructura (se saltará rename porque será primera vez). Las migraciones se incluyen más por integridad que por necesidad para un nuevo entorno.

Integridad de datos: Actualmente no hay restricciones de clave externa entre RegistroTag y otras tablas, porque guardamos solo el tag string. Esto significa que la integridad referencial (por ejemplo, asegurar que un tag corresponde a una herramienta existente) recae en la capa de aplicación, no en la BD. Para replicar el funcionamiento tal cual, esto no es un problema. Sin embargo, al ampliar, sería recomendable asociar RegistroTag con, por ejemplo, un modelo Herramienta para evitar tags desconocidos. También se podría establecer relación de RegistroTag con User (para registrar quién sacó qué, si el sistema detectara el usuario tag en mismo evento).

Consultas típicas:

- Últimos movimientos: SELECT tag, fecha_hora FROM registros_registrotag ORDER BY fecha_hora DESC LIMIT 10; – Muestra los 10 eventos más recientes.
- Filtrar por tag: SELECT * FROM registros_registrotag WHERE tag = "ABC123" ORDER BY fecha_hora; – ver histórico de un tag en particular (útil para ver cuántas veces se usó una herramienta).
- Usuarios: SELECT username, id FROM auth_user; – lista de usuarios del sistema web.
- Combinar info: Dado que no hay foreign keys directas, una consulta para saber qué usuario tenía tal herramienta en cierto momento requiere deducción. Se podría correlacionar: “buscar registro de usuario X y herramienta Y con timestamps cercanos”. Esto en SQL puro es complejo; es más fácil procesarlo en Python tras obtener listas.

Pruebas de la base de datos: Durante el desarrollo, se realizaron algunas pruebas para asegurar que los modelos funcionaban:

- Tras migrar, se usó la shell de Django (python manage.py shell) para crear manualmente un RegistroTag:

from registros.models import RegistroTag

r = RegistroTag.objects.create(tag="TESTTAG123")

print(r.id, r.fecha_hora)

- Esto confirmó que se guardaba con timestamp actual.
- También se probó leer los registros:

for reg in RegistroTag.objects.all():

print(reg.tag, reg.fecha_hora)

- Esto mostró en consola los que se habían guardado (vía pruebas con curl, etc.).
- Se ingresaron datos de prueba para usuarios (createsuperuser ya crea uno). Adicionalmente:

from django.contrib.auth.models import User

u = User.objects.create_user('juan', password='1234')

- Este usuario luego se probó con la API login (devolviendo success True con contraseñas correctas).
- Integridad: como no hay muchas restricciones, la principal preocupación era no tener duplicados no deseados. Se consideró si debíamos evitar registrar el mismo tag repetido en milisegundos. Ese control se puso en ESP32. En BD no hay restricción unique sobre tag, porque se espera repeticiones a distintos tiempos.

Scripts de prueba automatizados: No se llegaron a integrar scripts de prueba completos, pero se podría crear un script Python para simular la entrada de datos:

import requests, time

tags = ["AAA111", "BBB222"]

for t in tags:

requests.post("http://192.168.111.218:8000/api/v1/register/tag/", json={"tag": t})

Primero envía AAA111 (supongamos es user) luego BBB222 (herramienta). Repetir en orden inverso para simular devolución:

time.sleep(5)

for t in reversed(tags):

requests.post(..., json={"tag": t})

Luego consultar base de datos a ver si hay 4 nuevos registros. Esto fue mentalmente verificado más que codificado.

Respaldo y administración: La BD SQLite es un archivo db.sqlite3 en el directorio del proyecto. Es importante hacer respaldos regulares, sobre todo antes de actualizaciones. Se puede copiar directamente el archivo (con el servidor apagado para consistencia). También se puede usar python manage.py dumpdata > backup.json para exportar datos en JSON si se desea migrar a otra BD.

Para la presentación del proyecto, se podría pre-cargar la BD con algunos datos ficticios para demostrar la interfaz, por ejemplo, unos registros de ejemplo, usuarios de prueba, etc.

Conclusión de BD: La base de datos fue diseñada minimalista pero funcional. Para replicar el proyecto, bastará con ejecutar las migraciones en la nueva instalación, lo cual creará el esquema adecuado. Dado el bajo nivel de complejidad de relaciones en este esquema, es poco propenso a errores de integridad y sencillo de entender para cualquier persona que tome el proyecto. A la vez, es fácil de extender en el futuro conforme se requiera persistir más información (por ejemplo, agregar campos de ubicación de herramienta, estado de mantenimiento, etc.).
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

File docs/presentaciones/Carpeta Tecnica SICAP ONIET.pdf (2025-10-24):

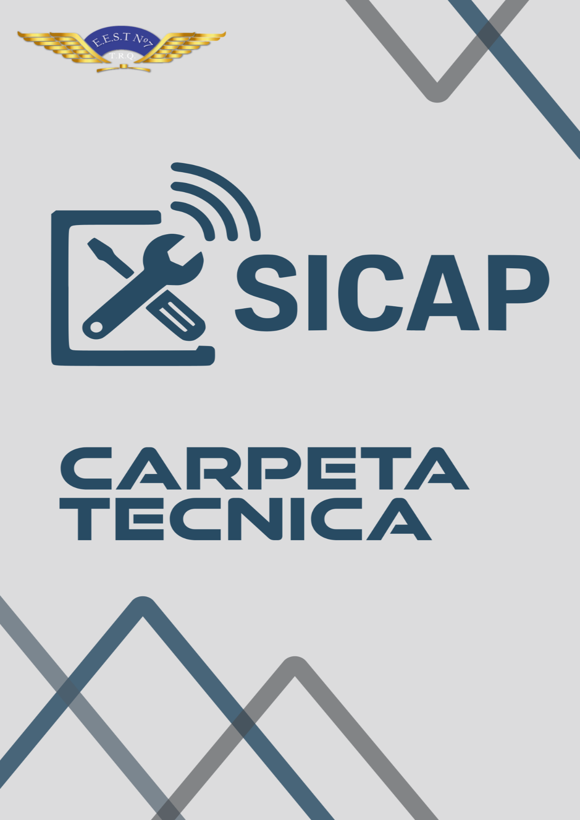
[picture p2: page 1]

# Proyecto S.I.C.A.P – Carpeta Técnica Oficial

Sistema Integral de Control Automatizado del Pañol (SICAP)

“Orden inteligente, control eficiente”

## 1. Introducción y Objetivos

El Proyecto S.I.C.A.P. (Sistema Integral de Control Automatizado del Pañol) surge como respuesta a un problema cotidiano en talleres, escuelas técnicas y empresas: la pérdida de herramientas y la falta de trazabilidad en su uso. Este sistema propone modernizar la gestión del pañol de herramientas mediante tecnología RFID e IoT, evitando pérdidas, mejorando la organización y permitiendo decisiones informadas basadas en datos actualizados .

Objetivo general: Desarrollar e implementar un sistema integral y automatizado de control de activos (herramientas) en un pañol, capaz de registrar en tiempo real la entrada y salida de herramientas y quién las toma, eliminando registros manuales y mejorando la eficiencia en la gestión.

Objetivos específicos:

- Identificación automática por RFID: Equipar cada herramienta con una etiqueta RFID UHF y cada usuario con una tarjeta/pulsera RFID para detectar su identidad al retirar o devolver herramientas.
- Detección y registro en tiempo real: Implementar un portal RFID en la entrada/salida del pañol que, mediante antenas y un lector controlado por ESP32, detecte automáticamente qué herramienta sale o ingresa y qué usuario la porta.
- Servidor local de datos: Desplegar un servidor local (Raspberry Pi) con una base de datos integrada que reciba los datos de cada evento (herramienta retirada/devuelta, usuario, fecha y hora) y los almacene automáticamente.
- Interfaz de gestión web: Desarrollar una aplicación web accesible desde cualquier dispositivo en la red interna, para visualizar el inventario en tiempo real (qué herramientas están disponibles o en uso, quién las tiene, cuándo fueron retiradas), así como administrar usuarios y herramientas.
- Seguridad y control: Restringir el sistema a una red local dedicada para asegurar que solo el personal autorizado pueda acceder, y mantener un registro histórico de movimientos para auditorías o análisis futuros.
- Integración pedagógica: Permitir a los desarrolladores (estudiantes) aplicar conocimientos de electrónica, redes y programación en un proyecto integrador real, aprendiendo sobre microcontroladores, bases de datos, backend web y desarrollo frontend, al tiempo que resuelven un problema concreto de su entorno educativo.

## 2. Justificación Técnica y Pedagógica

Justificación técnica: Muchas instituciones educativas y talleres enfrentan pérdida de herramientas, desorden y falta de control en sus pañoles. Un sistema automatizado como SICAP mejora significativamente la eficiencia al eliminar registros manuales y reducir extravíos, brindando control y responsabilidad compartida. La tecnología RFID UHF fue elegida por su capacidad de identificar múltiples objetos a distancia, incluso varios metros, sin requerir línea de vista. Esto la hace ideal para monitorear herramientas en tiempo real sin intervención humana, evitando errores y registrando todo automáticamente. Además, el uso de una arquitectura IoT local (ESP32 + servidor Raspberry Pi) garantiza que el sistema funcione aunque no haya Internet, manteniendo los datos dentro de la institución para mayor seguridad y velocidad de acceso.

Justificación pedagógica: El proyecto SICAP se desarrolló en un contexto escolar técnico, por lo que su implementación tuvo también fines educativos. Los estudiantes involucrados reforzaron competencias en diversas áreas de la tecnología:

- Electrónica y hardware: diseño de circuitos (por ejemplo, un conversor RS232-TTL para el lector RFID), integración de sensores/antenas RFID con microcontroladores, y ensamblaje de un portal de detección.
- Programación embebida: desarrollo de código en MicroPython para el ESP32, manejando comunicación serial (UART) y protocolos de red (WiFi).
- Administración de sistemas: configuración de un servidor Linux (Raspberry Pi), instalación de servicios (servidor web Django, base de datos SQLite) y configuración de redes LAN/WiFi.
- Desarrollo web: implementación de un backend con Django (incluyendo APIs REST) y una interfaz web frontend (web app) usando frameworks modernos (Ionic/Angular), aplicando principios de diseño web responsivo.

- Gestión de proyectos: documentación técnica completa, pruebas de funcionamiento y trabajo colaborativo, simulando un entorno de desarrollo profesional. Se integraron áreas de software y hardware, lo que brindó a los alumnos una experiencia holística de ingeniería de sistemas.

Desde el punto de vista pedagógico, SICAP sirvió como proyecto integrador que permitió a los estudiantes aplicar en la práctica contenidos de años anteriores y resolver problemas reales de su institución. Asimismo, se fomentó el trabajo en equipo, la resolución de problemas, la creatividad en el diseño de soluciones y la comunicación efectiva (por ejemplo, presentando el proyecto a la comunidad y buscando sponsors para componentes). En resumen, SICAP no solo aporta una solución tecnológica versátil y funcional al control de activos físicos , sino que también representa un valioso logro pedagógico al consolidar el aprendizaje multidisciplinar en un proyecto tangible.
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

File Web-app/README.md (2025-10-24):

# 💻 Web App – Proyecto SICAP

La **aplicación web** del proyecto **SICAP** fue desarrollada para ofrecer una **interfaz moderna, accesible y adaptable a distintos dispositivos**, desde la cual se puede visualizar y gestionar la información proveniente del sistema RFID en tiempo real.  

Este módulo representa la parte **interactiva y visual** del proyecto, permitiendo al usuario consultar datos, verificar lecturas, controlar el estado del sistema y navegar de forma intuitiva entre las distintas secciones.

---

## 🎯 Objetivo

- Mostrar de manera dinámica los datos enviados por el **servidor SICAP**.  
- Permitir el **monitoreo de etiquetas RFID**, antenas activas y estados del sistema.  
- Brindar una interfaz **multiplataforma**, accesible desde navegadores y dispositivos móviles.  
- Integrar visualmente todas las áreas del proyecto (hardware, firmware y backend).

---
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

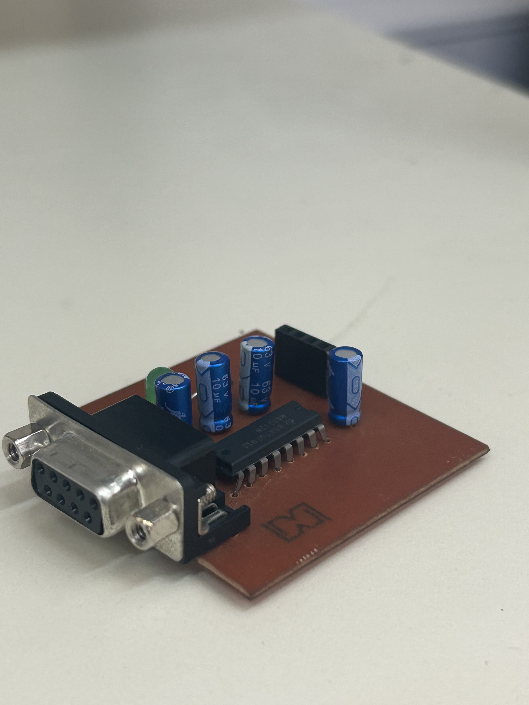
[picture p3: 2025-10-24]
hardware/conversor_rs232_ttl/Segunda_Placa/Imagen_referencia.png

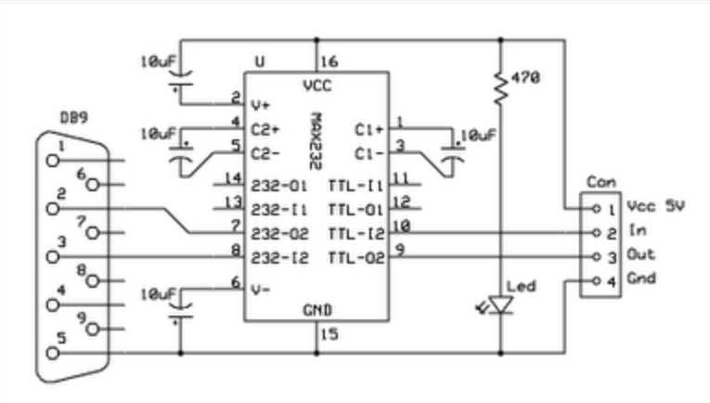
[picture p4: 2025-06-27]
hardware/conversor_rs232_ttl/Segunda_Placa/Esquematico.png

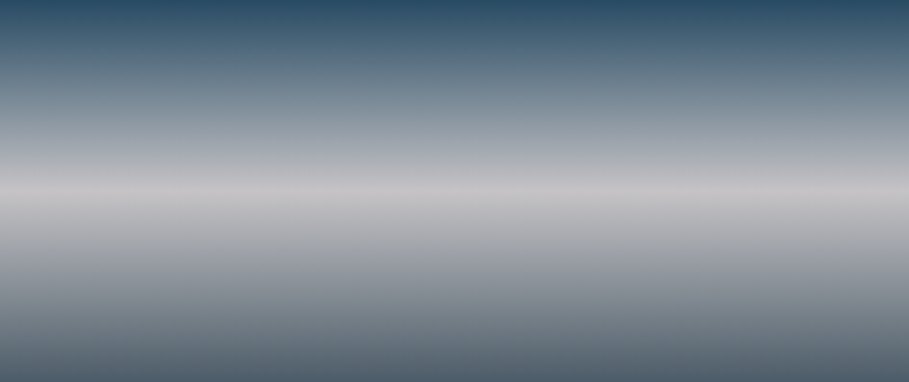
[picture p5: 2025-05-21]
Pagina Web/images/pantalla principal 3.png

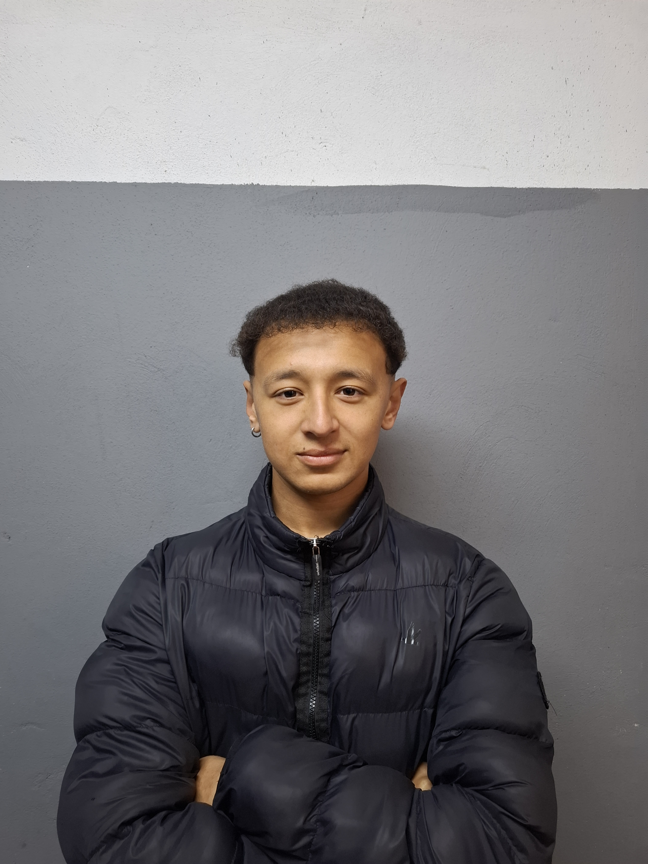
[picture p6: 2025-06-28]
Pagina Web/images/new-titi.jpg

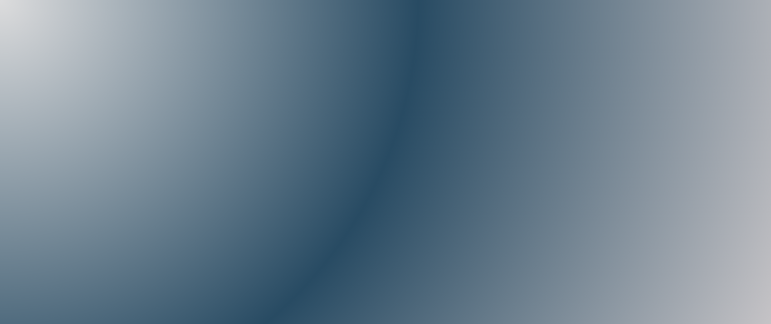
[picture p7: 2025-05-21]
Pagina Web/images/background 1.png

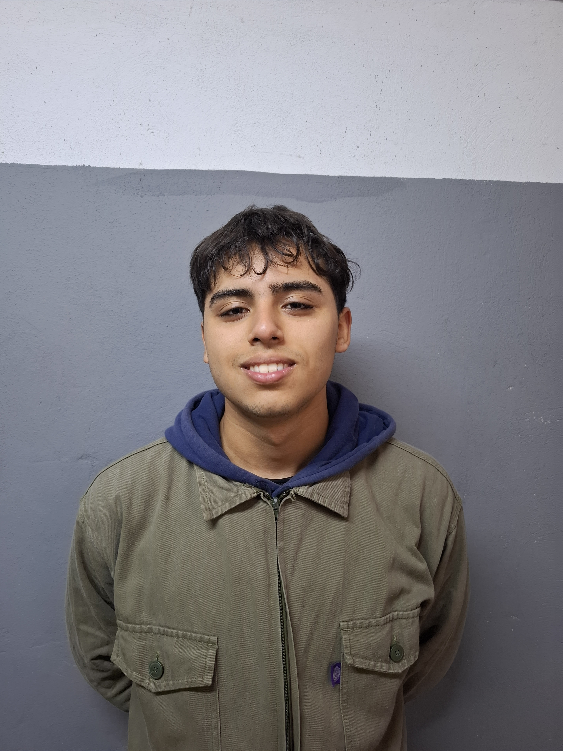
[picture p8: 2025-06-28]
Pagina Web/images/new-facus.jpg

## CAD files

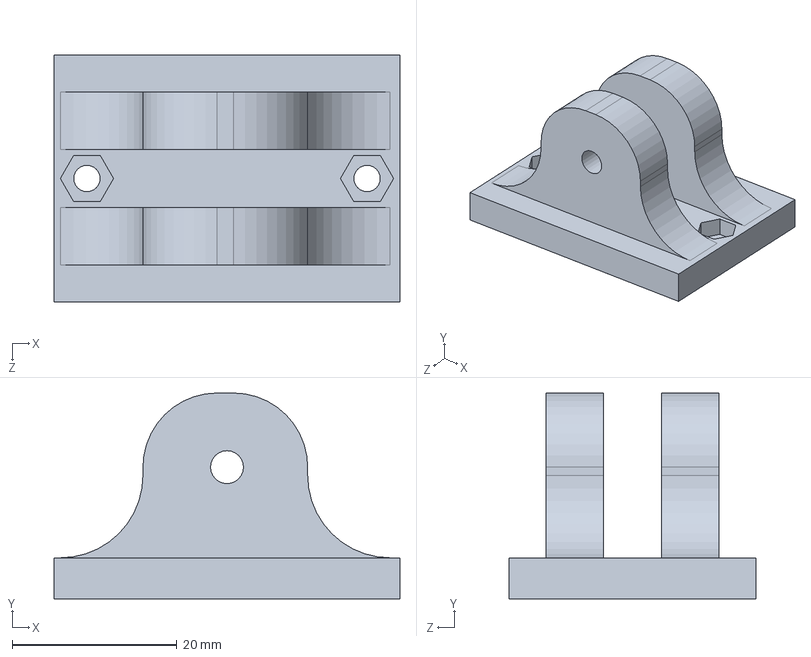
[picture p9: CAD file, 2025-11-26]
Diseños_SolidWorks/soporte antena mkll prt2.SLDPRT
42.0 x 25.0 x 30.0 mm

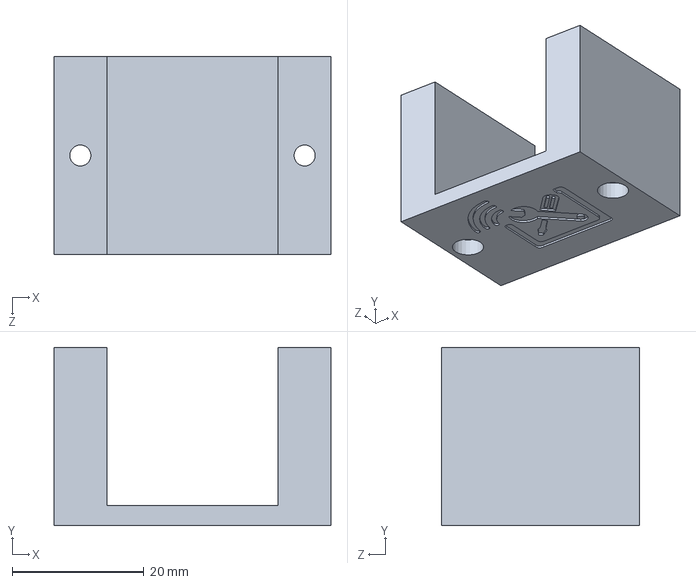
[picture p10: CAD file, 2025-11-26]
Diseños_SolidWorks/soporte antena prt1 mkll.SLDPRT
42.0 x 27.0 x 30.0 mm

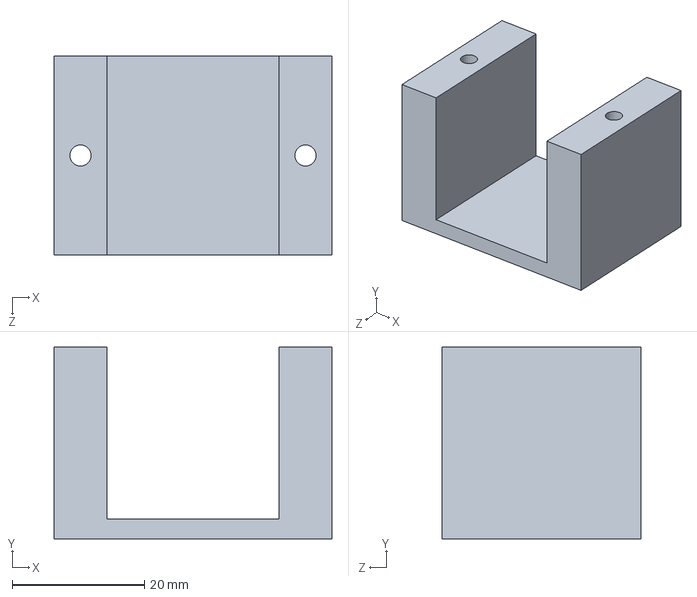
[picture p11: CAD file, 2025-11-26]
Diseños_SolidWorks/soporte antena prt1.SLDPRT
42.0 x 29.0 x 30.0 mm

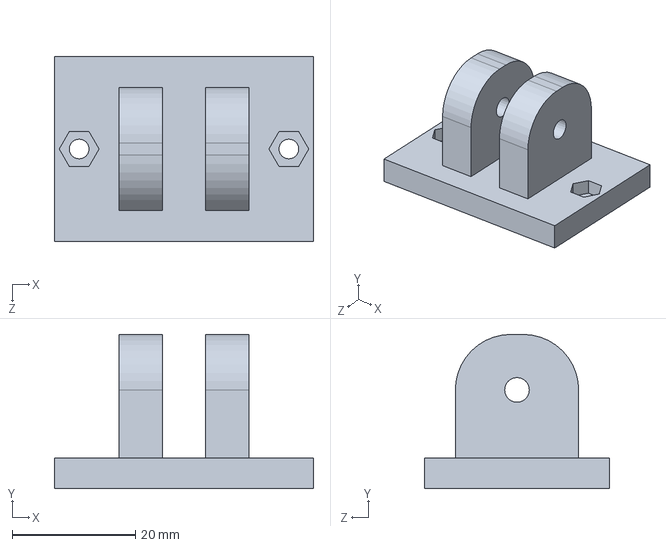
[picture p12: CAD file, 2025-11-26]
Diseños_SolidWorks/soporte antena prt2.SLDPRT
42.0 x 25.0 x 30.0 mm

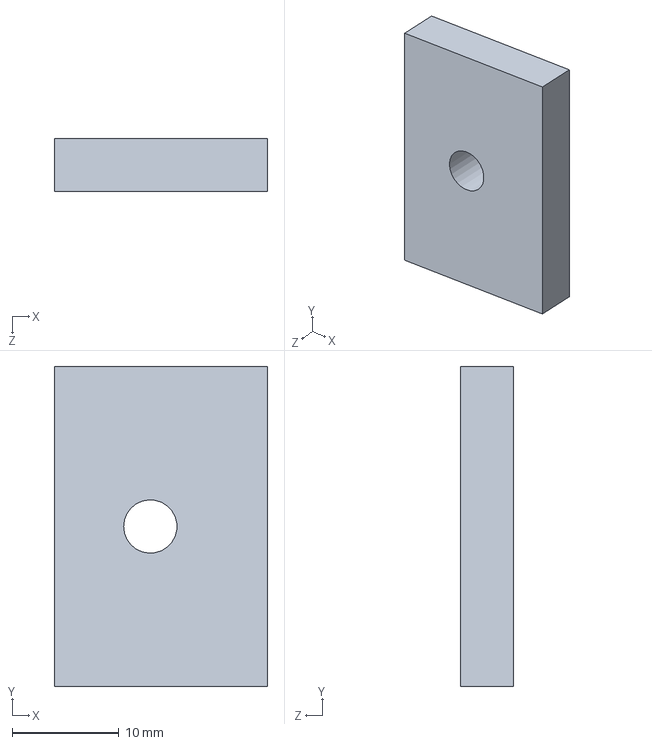
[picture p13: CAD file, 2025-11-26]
Diseños_SolidWorks/soporte de antena2.SLDPRT
20.0 x 30.0 x 5.00 mm

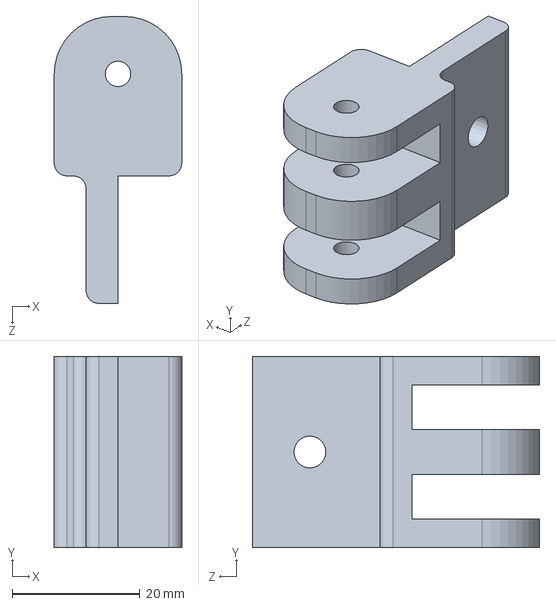
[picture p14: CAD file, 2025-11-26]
Diseños_SolidWorks/soporte de antena.SLDPRT
20.0 x 30.0 x 45.0 mm

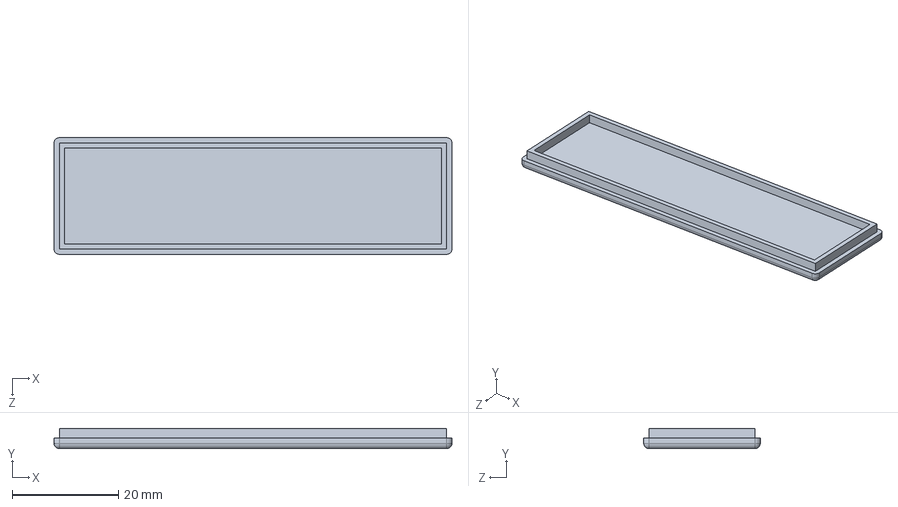
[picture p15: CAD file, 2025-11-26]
Diseños_SolidWorks/tapa pulsera.SLDPRT
75.0 x 3.80 x 22.0 mm

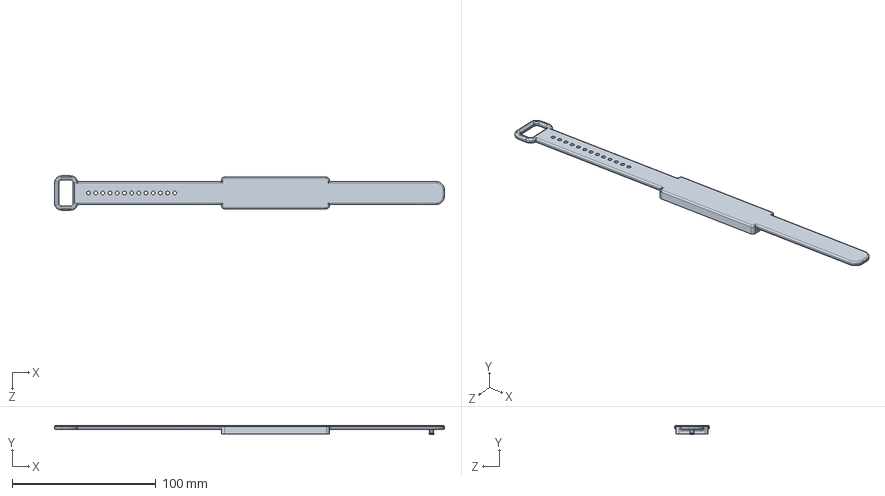
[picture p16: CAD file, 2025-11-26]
Diseños_SolidWorks/pulsera.SLDPRT
271.0 x 6.60 x 24.0 mm

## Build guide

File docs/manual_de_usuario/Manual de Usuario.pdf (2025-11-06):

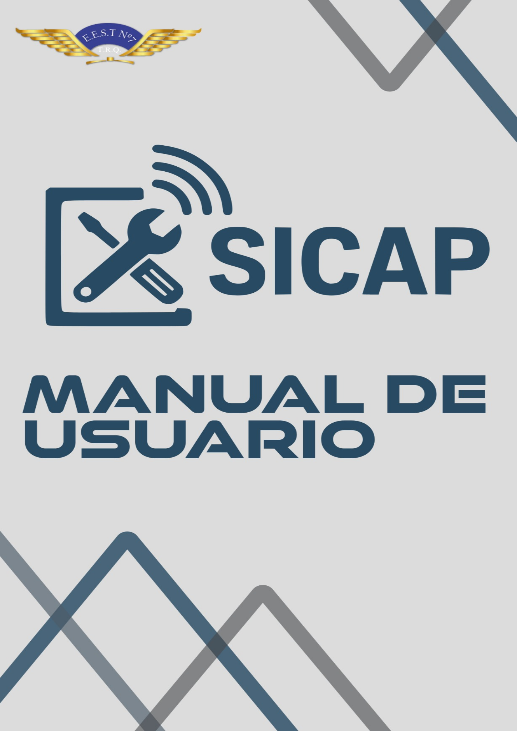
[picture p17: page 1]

# Manual de Usuario – SICAP (Sistema Integral de Control Automatizado del Pañol)

Versión: 2025

Proyecto desarrollado por: Lautaro Santolucito, Pablo Osores, Facundo Spagnoletta, Facundo Ledesma, Tiziano Patella – 7mo 1ra Aviónica

## Índice General

- 1. Glosario
- 2. Introducción

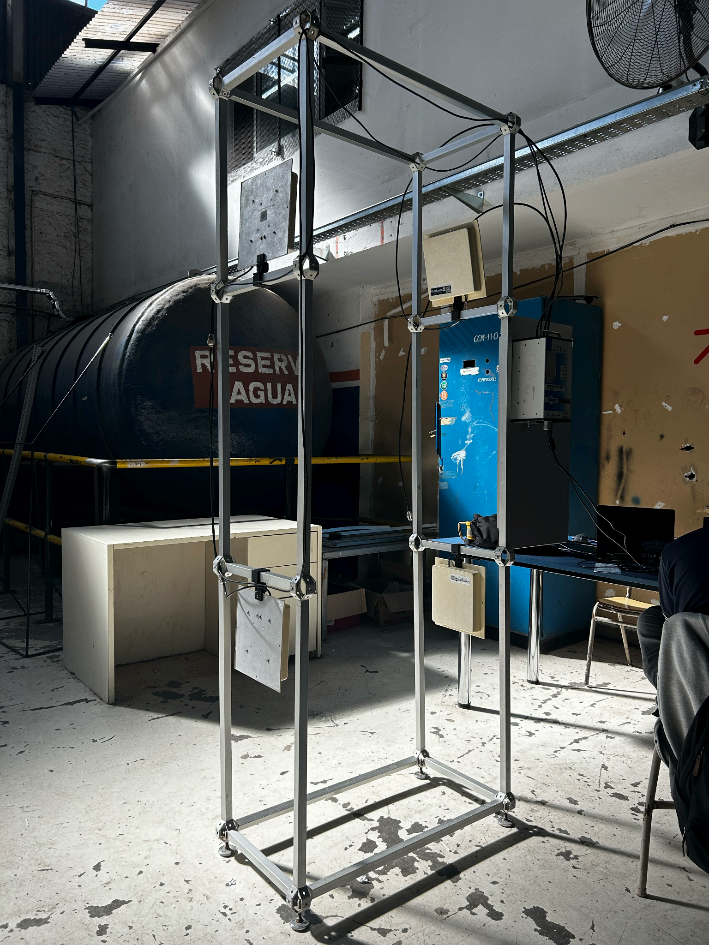
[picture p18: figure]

- 2.1. ¿Qué es SICAP?
- 2.2. Objetivo
- 2.3. Aplicaciones posibles
- 3. Hardware del Sistema
- 3.1. Lista de componentes y función de cada uno
- 4. Precauciones Generales
- 5. Instalación Física
- 5.1. Paso a paso del montaje
- 6. Configuración Inicial
- 7. Guía de Uso del Sistema
- 7.1. Registro inicial de herramientas en el sistema
- 7.2. Administración de herramientas en la interfaz
- 7.3. Registro de usuarios (operarios)
- 7.4. Operación automática del sistema (entradas, salidas, registros, historial)
- 8. Mantenimiento y Buenas Prácticas
- 9. Solución de Problemas Básicos
- 10. Contacto y Soporte Técnico

## 1. Glosario

- ESP32: Microcontrolador de bajo costo y bajo consumo con conectividad Wi-Fi y Bluetooth integrada. Desarrollado por Espressif Systems, cuenta con un procesador de 32 bits de doble núcleo y diversos periféricos, siendo sucesor del popular ESP8266. En SICAP, la placa ESP32 se utiliza como “cerebro” en campo para leer datos de las antenas RFID y comunicarlos al sistema central mediante Wi-Fi.
- RFID (Identificación por Radio Frecuencia): Tecnología de identificación automática que utiliza ondas de radio para identificar objetos a distancia mediante dispositivos llamados etiquetas o tags RFID. Cada etiqueta contiene un chip con información y una pequeña antena. Cuando la etiqueta entra en el campo electromagnético de un lector RFID, transmite su identidad única para ser registrada. Nota: En SICAP se emplea RFID de tipo UHF (Ultra Alta Frecuencia) para poder leer múltiples etiquetas simultáneamente a varios metros de distancia, ideal para controlar herramientas sin requerir escaneo manual.
- Router (Enrutador): Dispositivo de red que interconecta diferentes redes y dirige el tráfico de datos entre ellas, determinando la ruta óptima para enviar cada paquete al destino. En el sistema SICAP, un router Wi-Fi se usa para crear la red local a la que se conectan el ESP32, la Raspberry Pi y los dispositivos de los usuarios, permitiendo el acceso al sistema vía navegador web.
- Antena: Componente metálico diseñado para emitir o recibir ondas electromagnéticas. En RFID UHF, las antenas emiten radiofrecuencia para energizar las etiquetas pasivas y reciben la señal de respuesta de estas. SICAP utiliza al menos una antena RFID UHF conectada al lector; es crucial para detectar los tags cuando las herramientas (o las pulseras de usuarios) pasan por el portal.
- Etiqueta RFID (Tag): Dispositivo minúsculo (puede ser una tarjeta, adhesivo o encapsulado especial) que contiene un microchip y una antena. Las etiquetas pasivas no llevan batería: obtienen energía de la señal del lector RFID para responder con su identificación única. En SICAP, cada herramienta lleva una etiqueta RFID UHF (muchas son de tipo on-metal, aptas para adherir en superficies metálicas) y cada operario lleva una etiqueta RFID personal (por ejemplo, integrada en una pulsera) para su identificación.
- Portal RFID: Estructura física (similar a un arco o marco de puerta) equipada con antenas y un lector RFID UHF. Está diseñada para identificar y rastrear
automáticamente objetos con etiquetas RFID que pasan a través de ella. El portal de SICAP se instala en la entrada/salida del pañol; al atravesarlo, detecta qué herramientas pasan y qué usuario las lleva, sin necesidad de contacto ni acción manual.
- Raspberry Pi: Computadora de placa reducida (Single Board Computer) de bajo costo que corre un sistema operativo (por lo general Linux). En este proyecto, la Raspberry Pi actúa como servidor central: aloja la base de datos y la interfaz web de SICAP, procesando la información enviada por el ESP32 y permitiendo a los usuarios acceder al sistema desde un navegador.

- Pañol: Término utilizado para referirse al almacén o depósito de herramientas e insumos (común en entornos de talleres y escuelas técnicas). Es el espacio físico cuyo inventario es gestionado por SICAP de forma automatizada.

## 2. Introducción

2.1. ¿Qué es SICAP?

SICAP son las siglas de Sistema Integral de Control Automatizado del Pañol, una solución tecnológica creada para optimizar la gestión de herramientas y activos en talleres, escuelas técnicas y empresas. Surge como respuesta a problemas cotidianos: pérdida de materiales, falta de trazabilidad y desorganización en los espacios de trabajo. El sistema combina hardware RFID y software de registro para mejorar la eficiencia en el control del pañol. En esencia, SICAP permite saber en todo momento qué herramienta se retira, quién la retira y cuándo, de forma automática y en tiempo real. De este modo se eliminan las planillas manuales, se evitan extravíos y se promueve la responsabilidad en el uso de los recursos.

### 2.2. Objetivo

El objetivo principal de SICAP es modernizar la gestión de herramientas e insumos, ahorrando tiempo y reduciendo errores humanos en el control de inventario. Mediante la automatización con tecnología RFID, SICAP logra evitar pérdidas, mantener un registro fiable de entradas y salidas, y proporcionar información precisa y actualizada para la toma de decisiones. En pocas palabras, busca transformar un pañol tradicional en un pañol inteligente, donde cada movimiento quede registrado digitalmente sin esfuerzo adicional del personal.

### 2.3. Aplicaciones posibles

Si bien SICAP fue concebido para un pañol de herramientas, su enfoque modular y escalable permite aplicarlo a diversos entornos donde se requiera gestionar objetos físicos de forma eficiente. Algunas aplicaciones destacadas:

- Pañol de herramientas: Controla la retirada y devolución de herramientas en talleres o laboratorios. Registra automáticamente qué herramienta sale, quién la tomó y a qué hora, reemplazando el típico préstamo en papel. Esto aumenta la trazabilidad y la responsabilidad, reduciendo pérdidas y asegurando que las herramientas estén disponibles cuando se necesitan.
- Bibliotecas: Mediante etiquetas RFID en libros y en las credenciales de usuarios, los préstamos y devoluciones pueden registrarse sin intervención manual. Los usuarios simplemente pasan por un portal al llevarse o devolver libros, y el sistema anota la operación. Beneficios: préstamos más ágiles, menos errores y control total sobre el

inventario de libros.

- Control de activos en empresas: Cualquier institución o espacio que necesite saber qué objetos entran o salen y llevar un registro sin trabajo manual puede beneficiarse de SICAP. Por ejemplo, gestionar equipos de medición que se prestan entre departamentos: cada equipo con su tag y cada empleado con su tarjeta RFID, de modo que al mover el equipo quede registrado quién lo tiene. Las aplicaciones son muy amplias gracias a la versatilidad del sistema.

## 3. Hardware del Sistema

A continuación, se detalla la lista completa de componentes que conforman el sistema SICAP, junto con una breve descripción de la función de cada uno en el conjunto:

- Microcontrolador ESP32 (placa de desarrollo): Es el “cerebro” del sistema en campo. La placa ESP32 está programada para comunicarse con el lector RFID, detectar las etiquetas cercanas y enviar los datos relevantes al servidor central. Aprovecha su conectividad Wi-Fi para transmitir en tiempo real qué herramientas y usuarios han sido detectados por el portal. Su bajo consumo y tamaño compacto facilitan integrarlo cerca del lector RFID. (Ejemplo de hardware: módulo ESP32 DevKit V1, 32 bits dual-core, Wi-Fi 2.4 GHz y Bluetooth integrados.)

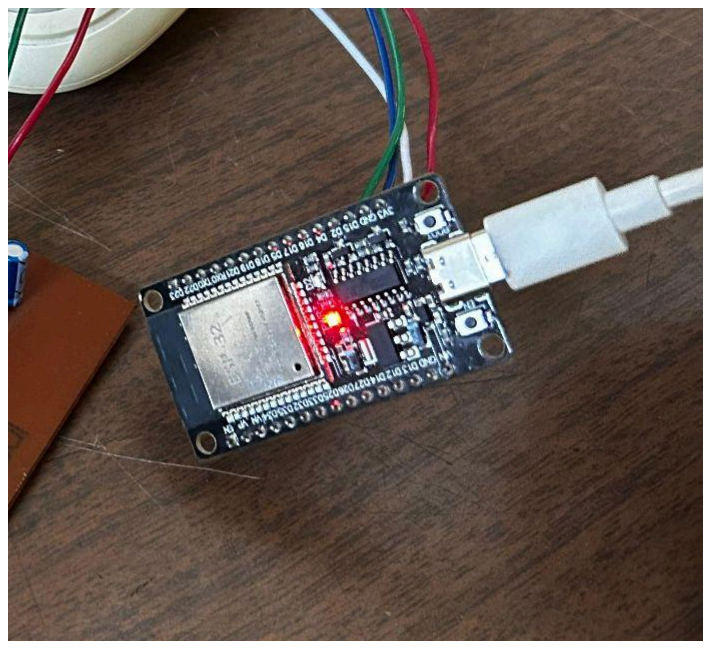
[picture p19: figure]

- Módulo Lector RFID UHF: Dispositivo encargado de emitir la señal de radiofrecuencia UHF y recibir las respuestas de las etiquetas RFID de ultra alta frecuencia. Este módulo genera el campo electromagnético necesario para energizar las etiquetas pasivas y leer sus identificadores únicos. Importante: a diferencia de pequeños lectores RFID de corto alcance, el módulo UHF de SICAP está diseñado para leer múltiples etiquetas a distancia (varios metros), por lo que trabaja con antenas externas y mayor potencia. Su salida de datos (por ejemplo vía interfaz serial UART o SPI) se conecta al ESP32 para el procesamiento de la información. (Modelo referencial: Lector RFID UHF capaz de trabajar en la banda 902–928 MHz, potencia ajustable, compatible con antenas externas.)

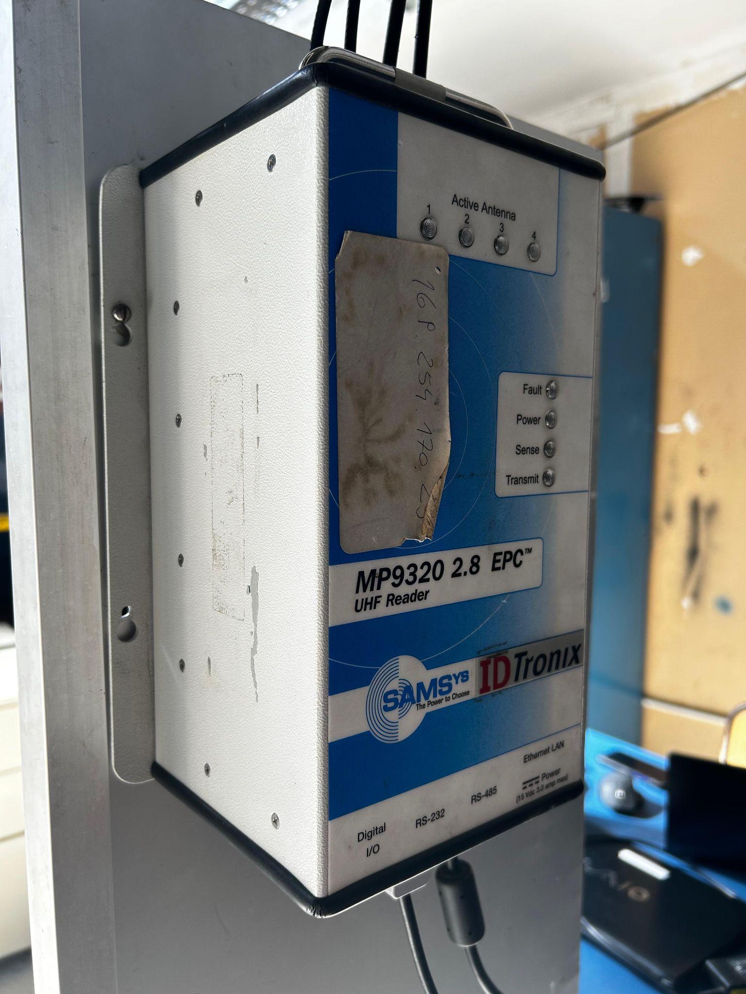
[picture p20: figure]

- Placa conversora RS232 a TTL: Nuevo componente de hardware incorporado para asegurar la comunicación entre el lector RFID UHF y el ESP32. Muchos lectores UHF industriales utilizan una interfaz serial RS232 (señales de ±12V) para enviar datos, mientras que el ESP32 opera con señales UART en nivel TTL (0–3,3V). Esta placa conversora adapta los niveles de voltaje y la lógica de la comunicación serial RS232 al nivel TTL que el ESP32 puede manejar. En otras palabras, convierte la señal serial del lector (voltajes altos RS232, con polaridad invertida) a señal serial compatible con el ESP32. Función: garantizar una comunicación fiable y proteger al ESP32 de voltajes inapropiados. Conexión: el puerto serial RS232 del lector se conecta a la entrada de esta placa (TX/RX RS232), y la salida TTL de la placa (TX/RX TTL) se conecta a los pines RX/TX del ESP32 (TX del conversor hacia RX del ESP32 y viceversa), compartiendo tierra común. Advertencias: alimentar correctamente la placa conversora según especificación (algunos módulos usan 5V, otros admiten 3,3V) y no conectar nunca la salida RS232 del lector directamente al ESP32 sin este conversor, pues podría dañar el microcontrolador.

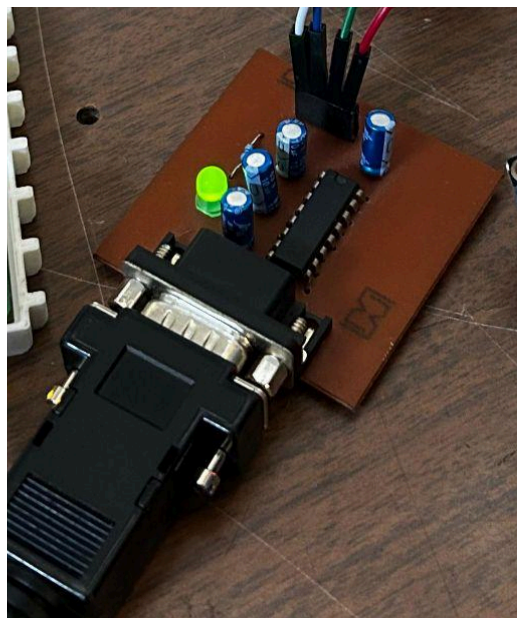
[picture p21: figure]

- Antena(s) RFID UHF: Panel o antena especializada que se conecta al lector RFID UHF. Emite las ondas de radio y recibe las señales de las etiquetas. SICAP incluye al menos una antena direccional UHF montada en el portal, orientada de forma que cubra la zona de paso de herramientas y usuarios. En algunos montajes se pueden usar dos antenas enfrentadas (una a cada lado del portal) para garantizar la cobertura total. La antena utilizada es apta para entornos con metal (muchas herramientas son metálicas) y está calibrada para la frecuencia UHF correspondiente. Su correcta colocación y conexión son críticas para el desempeño del sistema.

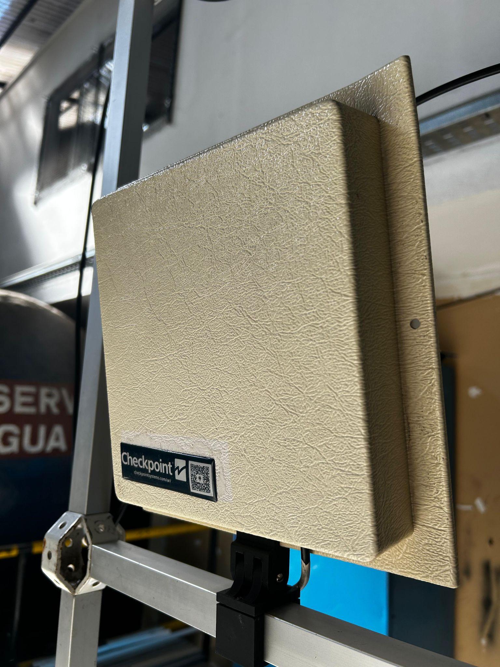
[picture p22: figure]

- Etiquetas RFID UHF pasivas: Pequeñas etiquetas que van adheridas a cada herramienta, y tarjetas o pulseras RFID UHF asignadas a cada usuario. Cada etiqueta contiene un código único identificable por el lector. En el caso de herramientas metálicas, se utilizan tags on-metal (especiales para adherir sobre metal sin perder capacidad de lectura). Las pulseras de los operarios contienen igualmente un tag UHF que identifica al portador. Estas etiquetas no requieren batería y pueden ser leídas simultáneamente por la antena del portal al pasar por ella. Son el elemento fundamental que permite identificar objetos y personas en SICAP.

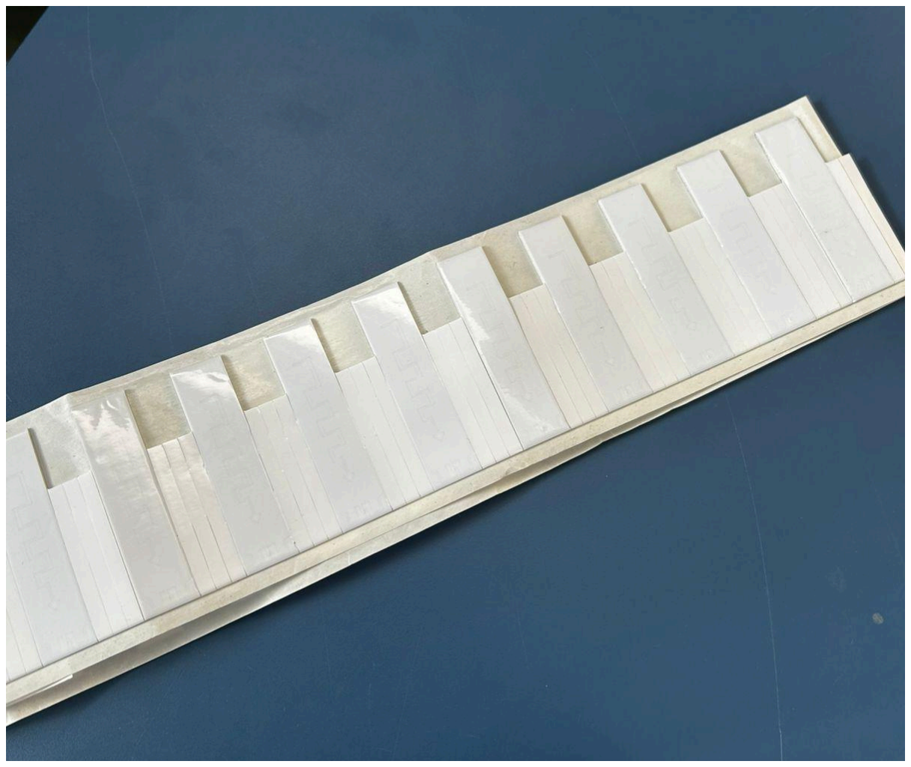
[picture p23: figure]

- Computadora Raspberry Pi (Servidor local): Una mini computadora que actúa como servidor central del sistema. La Raspberry Pi ejecuta el software backend y la base de datos donde se almacenan todos los registros (qué herramienta, quién, cuándo, etc.). También aloja el frontend (interfaz web) al que acceden los usuarios/técnicos desde un navegador. (Ejemplo: Raspberry Pi 4 con Raspberry Pi OS (Linux), conectada vía Ethernet o Wi-Fi al router local.) Su función es recibir los datos enviados por el ESP32, procesarlos (asociando herramientas con usuarios, actualizando el inventario) y ofrecer una plataforma donde visualizar y administrar toda la información.

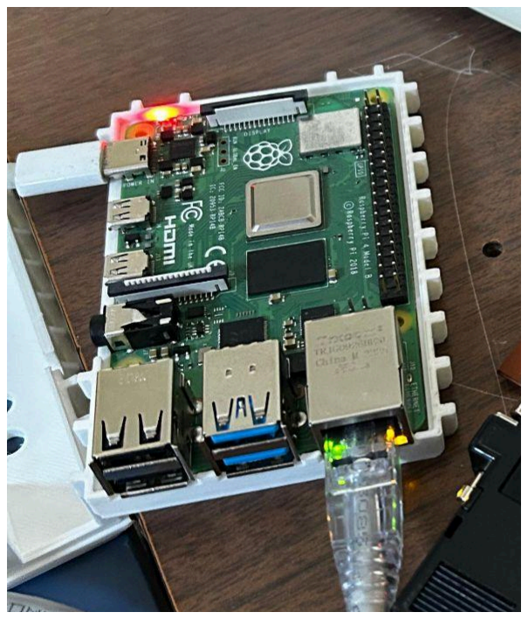
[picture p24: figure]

- Router Wi-Fi / Punto de Acceso: Un router inalámbrico se incluye para crear la red local dedicada al SICAP. Todos los dispositivos (ESP32, Raspberry Pi y cualquier PC o dispositivo móvil de los usuarios) se conectan a este router para comunicarse entre sí. El router asegura una conexión estable y aislada, de modo que el sistema pueda funcionar incluso sin internet, en una intranet local. Además, facilita el acceso al sistema desde, por ejemplo, una laptop o tablet del encargado, con solo conectarse a la red Wi-Fi del pañol. (El modelo de router puede variar; su configuración inicial se detalla más adelante.)

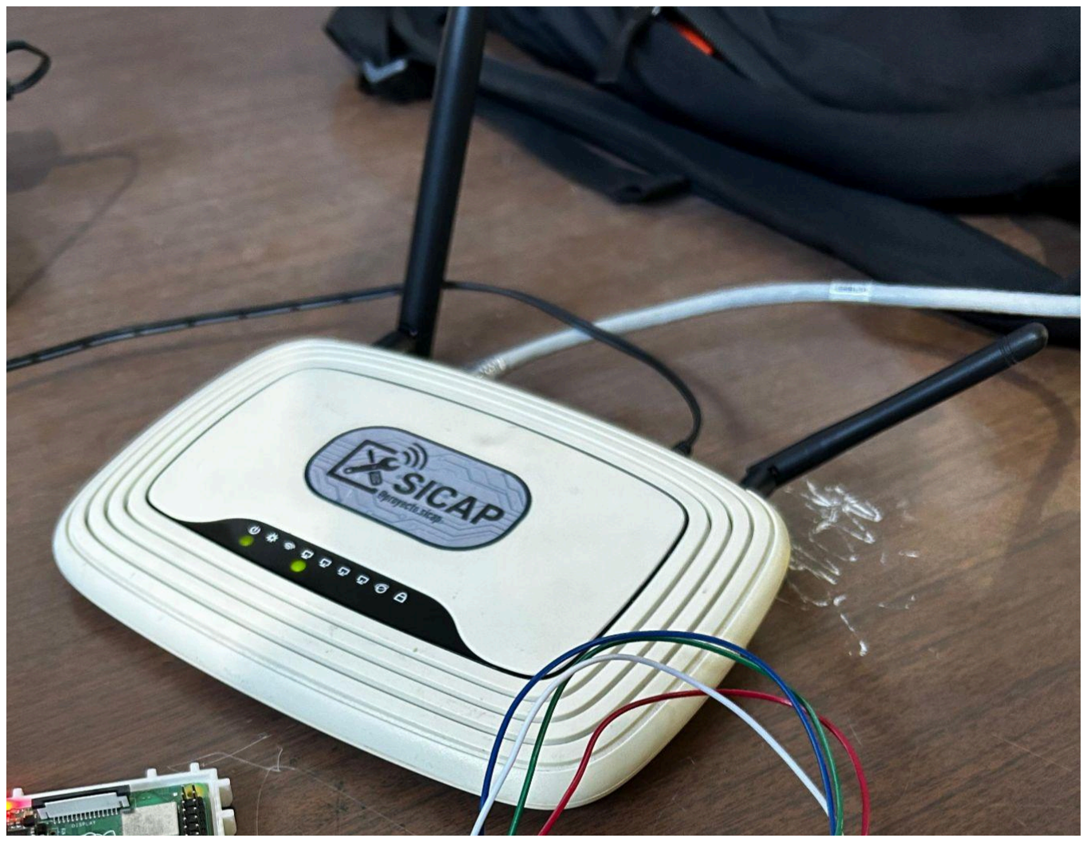
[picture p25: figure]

- Fuente(s) de alimentación: Conjunto de fuentes de poder necesarias para energizar los componentes. Típicamente: una fuente de 5V DC (2.5A o superior) para la Raspberry Pi; una fuente de 5V (o 3,3V) para la placa ESP32 (si no se alimenta vía USB desde la Pi u otro adaptador); y, en caso de que el módulo lector RFID UHF lo requiera, una fuente de 9–12V DC dedicada para darle la corriente suficiente para transmitir. Es vital usar las fuentes recomendadas para garantizar la estabilidad del sistema. Nota: Antes de encender, verificar que los voltajes y polaridades correspondan a cada equipo.
- Estructura de Portal: Soporte físico donde se instalan la(s) antena(s) RFID a la entrada del pañol. Puede ser un marco metálico o de PVC resistente, del tamaño de una puerta o arco por el cual pasarán las personas con sus herramientas. Esta estructura debe ser robusta (para sostener las antenas y soportar tránsito frecuente) y preferentemente fija al suelo o pared. Incluye abrazaderas o soportes para fijar las antenas a la altura y ángulo adecuados. En muchos casos, la electrónica (lector RFID, ESP32, placa conversora, cables coaxiales) está montada en la parte superior o lateral del portal, dentro de una caja de protección.
- Cables y accesorios de conexión: Todos los elementos necesarios para interconectar el sistema: cables coaxiales RF para conectar el lector a las antenas (con sus conectores adecuados, e.g. tipo N o SMA), cables USB/microUSB, cables de red Ethernet (para conectar la Raspberry Pi al router, si se usa conexión cableada), jumpers o arneses entre ESP32 y el módulo RFID (a través del conversor RS232-TTL, si aplica), etc. También entran aquí los elementos de montaje como tornillos, bridas, cintas de doble faz para fijar las etiquetas, cajas o gabinetes para proteger la electrónica, etc. Cada cable cumple un rol específico (datos, alimentación o RF), por lo que es importante identificarlos correctamente durante la instalación.

Resumen del hardware: En conjunto, estos componentes permiten que SICAP funcione de la siguiente manera: las antenas RFID del portal detectan las etiquetas en herramientas y usuarios cuando pasan; el lector RFID convierte esas señales en datos; el ESP32 recibe esos datos brutos (a través de la interfaz serial, usando la placa conversora en caso de RS232), los procesa localmente (filtrando lecturas duplicadas inmediatas, etc.) y los envía vía Wi-Fi al servidor Raspberry Pi. Allí el software registra la entrada/salida en la base de datos y actualiza la información que se muestra en la interfaz web. Todo esto apoyado por la red provista por el router y las etiquetas físicas colocadas en cada objeto/persona. El resultado es un sistema integrado de hardware y software que brinda control automatizado del pañol en tiempo real.

## 4. Precauciones Generales

Antes de poner en marcha el sistema o realizar mantenimiento, es fundamental tener en cuenta las siguientes precauciones de seguridad y buen uso:

- ¡No energizar el lector RFID sin las antenas conectadas! Siempre conecte la(s) antena(s) UHF al módulo lector antes de encender el sistema. Si el lector transmite sin tener una antena conectada (o con menos antenas de las que estén habilitadas en la configuración), la energía de RF no disipada puede dañar irreversiblemente el circuito transmisor. Este es un punto crítico: verifique dos veces las conexiones coaxiales de antena antes de encender. (Advertencia típica de equipos de RF de potencia.)
- Niveles de voltaje de comunicación: Nunca conecte interfaces RS232 directamente a microcontroladores de nivel TTL. Si el módulo lector RFID utiliza RS232, use siempre la placa conversora RS232-TTL para interconectarlo con el ESP32. Las señales RS232 operan con voltajes mucho más altos (y lógica invertida) que los pines del ESP32, lo que puede dañar sus entradas o impedir la comunicación. Asegúrese de cablear correctamente (TX del lector a RX del conversor, TX del conversor a RX del ESP32, y masa común) y de alimentar el conversor según sus requisitos.
- Corte de energía y manipulación segura: Desconecte la alimentación de todos los dispositivos antes de conectar o desconectar cables, componentes o antenas. Manipular los elementos con corriente puede causar cortocircuitos o choques eléctricos. Espere unos segundos tras desconectar para que se descarguen capacitores y luego proceda con la intervención. Use herramientas con aislamiento si es necesario y evite trabajar con las manos húmedas.
- Evitar sobrecalentamiento: Asegúrese de que la Raspberry Pi, el ESP32, la placa conversora y el módulo RFID tengan ventilación adecuada. No los cubra con materiales que atrapen calor. Si el lector RFID UHF va dentro de una caja, ésta debe tener aberturas o ventilación suficiente, ya que al emitir puede calentarse. Mantenga el equipo alejado de fuentes de calor externas y no lo exponga a la luz solar directa prolongadamente.
- No exponer a humedad ni polvo excesivo: Los componentes electrónicos deben estar protegidos en gabinetes o cajas, lejos de líquidos, lluvia o alta humedad que puedan causar corrosión o cortocircuitos. Si el pañol es un ambiente polvoriento (ej. taller mecánico), limpie periódicamente los alrededores del equipo y considere filtros o sellos en las cajas para impedir acumulación de polvo interno. Nunca limpie componentes con solventes fuertes; use paños secos o aire comprimido con el sistema apagado.
- Manejo adecuado de cables y antenas: No doblar excesivamente ni pellizcar los cables coaxiales de la antena; un cable dañado reduce drásticamente el alcance de lectura. Fije los cables para que no cuelguen sueltos ni puedan engancharse al paso de personas. Oriente la antena según las recomendaciones del fabricante (por lo general, de frente a la zona de paso) y fíjela firmemente para que no se mueva con vibraciones o golpes. Evite tocar la antena mientras el sistema está leyendo, para no interferir ni exponerse innecesariamente a la RF (si bien la potencia está dentro de límites seguros,

es buena práctica).

- Integridad de las etiquetas RFID: Las herramientas con etiquetas RFID on-metal deben manejarse con cuidado de no dañar la etiqueta. Aunque suelen ser resistentes, un golpe muy fuerte en la zona de la etiqueta, temperaturas extremas o intentos de despegarla pueden romper el chip o la antena interna. Instrúyase al personal a no quitar ni cubrir las etiquetas. Si una etiqueta se despega o daña, reemplácela por una nueva lo antes posible y actualice el registro del sistema (ver sección de Mantenimiento).
- Apagado correcto del servidor: Al finalizar la jornada, o cuando sea necesario apagar el sistema, apague primero la Raspberry Pi desde el software (por ejemplo, mediante la interfaz web de SICAP o vía comando de apagado en consola). No desconecte la alimentación de la Pi bruscamente sin un shutdown previo, ya que podría corromper la tarjeta SD o la base de datos. Una vez que la Pi indique que se detuvo, entonces sí corte la corriente. En cuanto al ESP32 y al lector RFID, si están alimentados por la Pi o comparten fuente, se apagarán conjuntamente; si no, apáguelos manualmente después de la Pi para evitar lecturas fuera de registro.
- Uso de elementos de protección personal: Si bien SICAP es un sistema electrónico de baja tensión, al instalar componentes en altura (por ejemplo, antenas en un portal elevado) use escaleras seguras y, de ser necesario, casco o guantes. Al manipular herramientas o máquinas cercanas durante la instalación, siga las normas de seguridad del taller. También, evite ubicarse directamente frente a la antena cuando el lector esté funcionando a máxima potencia por periodos prolongados; aunque la radiofrecuencia UHF es no ionizante y de baja potencia, es buena práctica no permanecer innecesariamente en la línea de emisión muy cerca de la antena.

Mantener estas precauciones garantizará una larga vida útil del equipamiento y la seguridad de los técnicos y usuarios que interactúan con el sistema. ¡La prevención es clave para un funcionamiento confiable y seguro de SICAP!

## 5. Instalación Física

En este apartado se describe el paso a paso del montaje físico de todos los componentes de SICAP, desde la instalación del portal RFID hasta la conexión del servidor y la red. Siga cuidadosamente cada paso y consulte las figuras o diagramas correspondientes (se recomienda añadir ilustraciones en esta sección para mayor claridad).

Pasos de montaje del sistema:

1. Montaje del portal RFID: Instale la estructura del portal en la entrada/salida del pañol. Asegúrese de que quede fija y estable. Lo ideal es ubicarla justo en el marco de la puerta o área de paso obligado, de modo que ninguna herramienta pueda salir o entrar sin atravesar el portal. Fije el portal al suelo o paredes utilizando tornillos, tarugos u otro sistema seguro. (Advertencia visual: utilice un nivel para alinear el portal verticalmente; evite inclinaciones que puedan afectar la lectura.)
2. Colocación de la antena RFID: Monte la antena UHF en la estructura del portal. Por ejemplo, si es un panel plano, puede atornillarla en la parte superior central del arco, orientada hacia abajo en diagonal cubriendo la zona de paso. Otra opción es fijarla a un lado del portal, apuntando hacia el lado opuesto para cubrir el ancho. La altura recomendada suele ser alrededor de 2 metros, para abarcar herramientas en mano o en un carro. Ajuste el ángulo si es direccional, siguiendo las indicaciones del fabricante para maximizar la zona de detección. No apriete en exceso los soportes de la antena para no dañar la carcasa, pero sí lo suficiente para que no se mueva. (Espacio para imagen: diagrama del ángulo correcto de la antena.)
3. Instalación del módulo lector RFID: Ubique el módulo lector RFID UHF cerca de la antena para minimizar la longitud del cable coaxial (los cables muy largos atenúan la señal). Lo usual es fijar el lector en la parte superior del portal, o en un lateral, dentro de una caja de protección (por ejemplo, una caja plástica con grado IP54) que lo resguarde del polvo y de manipulaciones no autorizadas. Taladre la caja para pasar los cables necesarios (coaxial de antena, cables de alimentación y cables de datos hacia el ESP32/placa conversora). Monte la caja firmemente en el portal. Asegúrese de que el lector esté apagado en este momento.
4. Conexión de la antena al lector: Tome el cable coaxial RF y conéctelo al puerto de antena del lector RFID UHF. Generalmente, el lector tiene uno o varios puertos etiquetados como ANT1, ANT2, etc. Conecte la antena principal en el puerto designado (por ejemplo ANT1, según documentación del lector). Enrosque el conector con cuidado y firmeza, usando solo la torsión necesaria; no forzar excesivamente para no dañar el conector. Recuerde: tal como se indicó en Precauciones, esta conexión debe estar hecha antes de encender el equipo. Es buena práctica usar cinta aisladora o una llave adecuada para un ajuste final suave, sin excederse.
5. Instalación de la placa ESP32 (y montaje del conversor RS232-TTL): Coloque la placa de desarrollo ESP32 dentro de la misma caja del lector RFID (si el espacio lo permite) u en otra caja cercana protegida. Junto a ella, instale la pequeña placa conversora RS232-TTL si su lector lo requiere (procure que ambas queden firmes, puede fijarlas con tornillos o cinta de doble faz para que no se muevan). El ESP32 debe conectarse con cables al puerto de comunicación del lector. Si el lector ofrece interfaz UART TTL o SPI, puede conectar directamente: por ejemplo pines TX/RX (UART) o pines MOSI/MISO/SCK (SPI) según corresponda al modelo. Si el lector utiliza RS232, conecte sus pines de salida RS232 (Tx, Rx y GND) a la entrada de la placa conversora, luego conecte la salida TTL del conversor a los pines UART del ESP32 (Tx del conversor a Rx0 del ESP32, Rx del conversor a Tx0 del ESP32, y tierras comunes).

Consulte el esquema de pines de su lector RFID para identificar correctamente las conexiones. Mantenga estos cables de datos lo más cortos posible y separados del cable de antena para evitar interferencias.

6. Fuente de alimentación del lector y ESP32: Monte la fuente de poder que alimentará el lector RFID (por ejemplo, una fuente de 12V DC) en un lugar cercano y seguro. Puede estar fuera de la caja del portal si no cabe dentro, pero siempre protegida de polvo/agua. Conecte la salida de esta fuente al puerto de alimentación del lector RFID (respete la polaridad + y − indicada). Si la fuente se conecta a la red eléctrica 220V, hágalo a un tomacorriente estable; se sugiere usar un UPS o protector de sobretensión para mayor seguridad. En cuanto al ESP32, si el lector o el conversor RS232-TTL proveen una salida de 5V, podría alimentarse de allí; de lo contrario, el ESP32 se puede alimentar luego desde la Raspberry Pi (por ejemplo a través de un cable USB) o con una fuente/regulador de 5V dedicado. No energice todavía ninguna de las fuentes; espere a completar todo el montaje antes de encender.
7. Instalación de la Raspberry Pi: Ubique la Raspberry Pi en un área segura de la oficina o del pañol. Nota: La Raspberry Pi no necesita estar físicamente cerca del portal, ya que se conectará por red. Usualmente se coloca en un escritorio o gabinete técnico donde se tenga fácil acceso para mantenimiento. Colóquela dentro de su caja protectora oficial (o una caja 3D impresa) para evitar cortocircuitos. Si es posible, sitúela en un lugar elevado o estante, alejada de imanes fuertes o motores que pudiera haber en el taller (esto evita potenciales interferencias tanto en su funcionamiento como en la señal Wi-Fi).
8. Conexión de la Raspberry Pi al router: Decida si la Raspberry Pi se conectará al router vía cable Ethernet o mediante Wi-Fi, y proceda según el caso:
- Conexión por cable: Conecte un cable de red desde el puerto Ethernet de la Pi hasta uno de los puertos LAN del router. Esta opción suele brindar mayor estabilidad en la comunicación.
- Conexión Wi-Fi: Alternativamente, puede configurar la Raspberry Pi para que se una por Wi-Fi a la red del router (esta configuración de software se realizará en la sección de Configuración Inicial). En caso de usar Wi-Fi, es recomendable ubicar físicamente el router relativamente cerca de la Raspberry Pi para asegurar una señal inalámbrica fuerte, o utilizar una antena/dongle Wi-Fi externo en la Pi si fuera necesario.
9. Coloque el router en una posición central respecto a la Raspberry Pi y el ESP32 (si este último usará Wi-Fi) para asegurar buena cobertura inalámbrica en toda el área.
10. Encendido del router y configuración de la red local: Conecte y encienda el router Wi-Fi. Configure la red local según las instrucciones del fabricante. Por defecto, muchos routers crean una red interna (por ejemplo, rango IP 192.168.0.x). Si el router viene preconfigurado, anote el SSID (nombre de la red inalámbrica) y la contraseña Wi-Fi predeterminada. Puede optar por cambiar el SSID a un nombre identificable (ej: “SICAP_Panol”) y establecer una contraseña conocida por los técnicos encargados. Si no es necesario acceso a Internet desde esta red, se puede dejar el router desconectado de WAN para aislar la red (opcional, según políticas de la institución). Verifique en este punto que, si la Raspberry Pi está conectada por cable, las luces de enlace del puerto Ethernet estén encendidas; o si va a usar Wi-Fi, que la configuración inalámbrica se realizará próximamente.
11. Energización secuencial del sistema: Una vez todo montado y verificado, proceda a encender los equipos en el siguiente orden:
- Encender Raspberry Pi: Enchufe la fuente de la Raspberry Pi (5V). La Pi iniciará su secuencia de arranque; espere ~30 segundos a 1 minuto hasta que esté operativa.
- Encender lector RFID (y ESP32): A continuación, encienda la fuente del lector RFID UHF, lo que energizará el lector (y también alimentará al ESP32 si éste toma corriente de la misma fuente o del lector/conversor). Nota: En algunos diseños, el ESP32 se alimenta desde la Raspberry Pi por USB; en tal caso, conecte el ESP32 a un puerto USB de la Pi o a su adaptador USB 5V dedicado y enciéndalo ahora, antes o al mismo tiempo que el lector.
- Verificar indicadores: Tras energizar, verifique que hay luces indicadoras en el ESP32 y en el lector (según el modelo del lector, puede tener LEDs de power/actividad). Esto indica que están alimentados correctamente. El ESP32 debería conectarse en cuestión de segundos a la red Wi-Fi del router (si ya fue preconfigurado con las credenciales de esta red durante su programación).
12. Muy importante: Asegúrese en este momento de que la(s) antena(s) RFID estén conectadas antes de que el lector comience a transmitir. Si todo es correcto, a esta altura el sistema físico ya estaría encendido y listo para las pruebas iniciales.
13. Pruebas iniciales de hardware: Con el montaje completo y energizado, es recomendable realizar pruebas básicas para confirmar que todo funciona:
- Lectura de una herramienta: Acerque una herramienta con etiqueta RFID al portal y verifique, por medio de la interfaz web de SICAP o mediante los logs de la Raspberry Pi, si el tag de la herramienta es detectado. Muchos lectores UHF tienen también un LED o algún indicador que parpadea al leer una etiqueta; observe estos indicios.

- Lectura de una pulsera de usuario: Haga lo mismo con una pulsera RFID de operario. Aún sin configurar nada en el software, debería detectarse la presencia de la etiqueta UHF de la pulsera cuando pase por el portal (aunque en ese momento el sistema no sabrá de quién es, la idea es verificar la lectura en crudo).
- Comunicación ESP32-Pi: Compruebe que el ESP32 esté comunicando con el servidor. Por ejemplo, si tiene acceso a la consola de depuración del ESP32 (vía USB serial), revise que esté enviando datos de lectura. Alternativamente, la interfaz web de SICAP podría mostrar un estado “Online” del ESP32.
- Recepción en la Raspberry Pi: Confirme que la Raspberry Pi está recibiendo información. Esto se podrá verificar más claramente en la siguiente etapa (configuración de software e interfaz), pero si hay una base de datos registrando, podría empezar a guardar eventos en crudo.
- Si algún paso falla (ej: no se detecta la etiqueta en una prueba), apague el sistema y revise las conexiones correspondientes: antena correctamente conectada, polaridad de las fuentes de alimentación, credenciales Wi-Fi del ESP32 (si no aparece conectado), cableado entre ESP32/conversor y lector, etc. No continúe hasta resolver el problema de hardware. Una vez ajustado, vuelva a encender en secuencia y repita las pruebas.

(En este documento, se pueden insertar diagramas o fotos en cada paso para ilustrar la instalación. Por ejemplo, una figura del portal montado con sus antenas, un esquema de cableado entre el ESP32 (con conversor) y el lector RFID, o una representación de la conexión del router y la Raspberry Pi. Estos recursos visuales ayudarán al técnico a replicar el montaje correctamente.)

Resumen de instalación: Monte el portal y antenas robustamente, conecte correctamente el lector, la placa conversora y el ESP32, configure la red local con el router, y luego encienda todo en el orden recomendado. Preste atención a las advertencias indicadas (especialmente sobre la antena) durante todo el proceso. Tras la instalación física, el sistema estará listo para la configuración de software y las pruebas funcionales.

## 6. Configuración Inicial

Con el hardware instalado y encendido, el siguiente paso es la configuración inicial de software y red para comenzar a usar SICAP. En esta sección se explica cómo acceder al sistema vía navegador web y qué datos iniciales se deben configurar. (Al inicio de este apartado, el técnico instalador puede completar campos específicos de la red, ya que pueden variar según la configuración.)

Pasos para la configuración inicial:

1. Conexión del dispositivo del usuario a la red SICAP: Tome un dispositivo con navegador web (puede ser una computadora portátil, PC de escritorio, tablet o incluso un smartphone) y conéctelo a la red Wi-Fi creada por el router del pañol. Si prefiere usar conexión cableada, conecte ese PC a uno de los puertos LAN del router mediante cable Ethernet. Asegúrese de que el dispositivo esté en la misma red local que la Raspberry Pi y el ESP32. (Ejemplo: si configuró la red Wi-Fi con SSID “SICAP_Panol”, únase a esa red con la contraseña establecida.)
2. Obtener la dirección IP del servidor (Raspberry Pi): Para acceder a la interfaz web, necesita la dirección de red de la Raspberry Pi. Por defecto, la Pi puede recibir una IP dinámica del router (vía DHCP). Si es posible, en la configuración del router asigne una IP fija a la Raspberry Pi para facilitar futuros accesos (por ejemplo, 192.168.0.100). Alternativamente, si el sistema SICAP y la red lo permiten, podría usarse un nombre de host mDNS (ej: sicap.local) para acceder sin conocer la IP numérica. Anote aquí la dirección IP asignada a la Raspberry Pi:

Dirección IP del servidor SICAP: [ ... ] (a completar por el instalador)

Nota: Si no conoce la IP, puede obtenerla entrando al panel de administración del router (buscando en la lista de clientes conectados) o conectando un monitor/teclado a la Raspberry Pi y ejecutando ifconfig en la consola. Es importante registrar la IP para referencia.

3. Acceder al sistema vía navegador: Abra un navegador web actualizado (se recomienda Chrome, Firefox o Edge) en el dispositivo conectado a la red SICAP. En la barra de direcciones, ingrese la URL con la IP o el hostname de la Raspberry Pi. Por ejemplo: http://192.168.0.100/ (reemplazando con la IP real del servidor SICAP obtenida en el paso anterior). Presione Enter. Debería cargar la página de inicio de sesión o bienvenida de SICAP en el navegador.
- Si el sistema está correctamente iniciado, verá la interfaz web de SICAP. En caso de que no cargue nada, verifique lo siguiente:

■ Confirme que el dispositivo esté conectado a la red Wi-Fi correcta del SICAP.

■ Revise que la Raspberry Pi esté encendida (LEDs activos) y que el servicio web del sistema esté corriendo en la Pi.

■ Compruebe si necesita anteponer http:// explícitamente en la dirección (en redes locales suele usarse HTTP por defecto, no HTTPS).

■ Si intentó usar el hostname (ej. sicap.local) y no carga, pruebe con la IP numérica directa.

4. Ingresar credenciales de inicio de sesión: Al acceder al sistema por primera vez, SICAP presentará una pantalla de login solicitando usuario y contraseña. Ingrese las credenciales predeterminadas del sistema o las proporcionadas por los desarrolladores:
- Usuario administrador: [usuario_por_defecto]
- Contraseña: [contraseña_por_defecto]
5. (Estos campos pueden completarse manualmente en el manual una vez conocidos. Por seguridad, se recomienda cambiar estas credenciales tras el primer acceso. Anote la nueva contraseña en un lugar seguro. Si este manual se imprime, puede agregar un espacio para escribir la contraseña actualizada.)

Configuraciones de red adicionales: Si necesita que SICAP sea accesible desde otra red o de forma remota (fuera del alcance del router local), será necesario configurar el acceso adecuadamente (por ejemplo, conectar el router a Internet y habilitar port forwarding o VPN, lo cual no se cubre en este manual básico). Para la mayoría de los usos internos, mantener la intranet local aislada es suficiente y más seguro.

6. Verificación de componentes en la interfaz: Una vez logueado con éxito, navegue por la interfaz web de SICAP para verificar que todos los componentes estén reportando correctamente:
- Compruebe en el panel de estado (si existe) que el lector RFID y el ESP32 figuran como conectados/en línea. Si hubiera algún indicador de error de comunicación, revise la configuración Wi-Fi del ESP32 (debería haberse programado con el SSID y contraseña del router SICAP durante la instalación del software del microcontrolador).
- Revise la sección de Inventario o Herramientas en la interfaz: inicialmente debería aparecer vacía (a menos que se hayan precargado herramientas de ejemplo). No se preocupe, en el siguiente paso se registrarán las herramientas reales.
- Revise la sección de Usuarios: deberían estar pre-registrados los operarios a quienes se entregaron pulseras RFID, si es que se cargaron de antemano. De lo contrario, se podrán agregar durante la etapa de uso del sistema.

En resumen, la configuración inicial consiste en conectar un dispositivo a la red SICAP, acceder vía navegador a la dirección IP del servidor, e iniciar sesión con las credenciales predeterminadas. Tras esto, el sistema estará listo para su uso y personalización (registro de herramientas y usuarios reales). Asegúrese de documentar en este manual la IP, usuario y contraseña establecida para futuras referencias. Si en algún momento se necesita reconfigurar la red (por ejemplo cambiar el SSID Wi-Fi o asignar otra IP fija), se deberá reprogramar el ESP32 con la nueva información de Wi-Fi y actualizar la documentación correspondiente.

## 7. Guía de Uso del Sistema

Una vez instalado y configurado, SICAP se convierte en una herramienta cotidiana para gestionar el pañol. En esta sección se explica cómo utilizar el sistema, desde registrar las herramientas en la base de datos, hasta entender el funcionamiento automático de entradas y salidas, y la consulta de historiales. La interfaz de usuario de SICAP está pensada para ser intuitiva; sin embargo, a continuación se detallan los principales procesos de uso.

### 7.1. Registro inicial de herramientas en el sistema

Antes de comenzar la operación normal, es necesario dar de alta todas las herramientas (y demás activos) que tendrán etiquetas RFID, asociándoles un nombre y datos descriptivos en el sistema. Esto se realiza a través del frontend (interfaz web) de SICAP con un usuario administrador. Siga estos pasos para registrar las herramientas:

1. Preparar las herramientas con sus etiquetas: Asegúrese de que cada herramienta física tenga adherida su etiqueta RFID UHF correspondiente. Idealmente, durante la instalación física ya se habrán colocado las etiquetas a todos los ítems. Verifique que cada etiqueta esté firmemente pegada; si la etiqueta tiene impreso un código (muchos tags UHF llevan un número hexadecimal o decimal impreso), anótelo para identificarla fácilmente al registrar.
2. Acceder a la sección de administración de herramientas: Ingrese al sistema desde un navegador con un usuario que tenga permisos administrativos. En el menú principal de la interfaz web, busque la sección denominada por ejemplo “Inventario” o “Herramientas”. Dentro de esa sección, haga clic en la opción “Agregar nueva herramienta” (también podría llamarse “Registrar herramienta” u similar, dependiendo de la traducción de la interfaz).
3. Escanear o ingresar el ID de la etiqueta: La interfaz le solicitará los datos de la nueva herramienta. Lo primero es obtener el código único (ID) de su etiqueta RFID:
- Lectura directa: Haga clic en un botón del formulario que diga “Escanear tag” (o similar) y luego acerque la herramienta (con su etiqueta puesta) al portal RFID o al lector designado. El sistema detectará la etiqueta UHF y automáticamente rellenará el campo de ID con el código leído.

- Ingreso manual: Alternativamente, puede introducir manualmente el código si lo tiene anotado. Esto es útil en caso de registrar la herramienta sin tenerla físicamente cerca en ese momento. Ingrese el número del tag cuidadosamente (generalmente es una cadena alfanumérica de 8 a 24 caracteres).
4. Nota: La lectura directa suele ser más cómoda y evita errores de tipeo. Si el sistema no detecta el tag al acercarlo, asegúrese de que el ESP32 esté en modo lectura y que el portal esté funcionando correctamente. Si se cuenta con un lector RFID USB independiente para altas (según implementación), también podría usarse para escanear el tag en la PC.
5. Completar datos descriptivos de la herramienta: Además del ID RFID, la interfaz le pedirá ingresar información sobre la herramienta. Complete los campos según corresponda:
- Nombre de la herramienta: Un nombre breve pero identificativo. Ejemplos: “Taladro percutor Bosch 500W”, “Llave fija 13mm N°3”, etc. Este nombre aparecerá en los registros y listados.
- Categoría o tipo: Si el sistema lo permite, seleccione la categoría de la herramienta (ej.: Herramienta eléctrica, Herramienta manual, Instrumento de medición, etc.).
- Descripción adicional / Observaciones: Campo opcional donde detallar el estado de la herramienta, número de serie, u otra identificación interna.
- Ubicación usual: Puede registrar dónde debería guardarse la herramienta (por ejemplo “Estante 2, caja verde”) para ayudar a localizarla cuando esté en el pañol.
6. Llene estos campos de acuerdo a las políticas de inventario de su institución, de manera que la información sea útil para identificar cada ítem.
7. Guardar el registro: Una vez completos los datos, haga clic en “Guardar” o “Agregar”. La nueva herramienta quedará registrada en la base de datos. El sistema típicamente mostrará un mensaje de confirmación (“Herramienta agregada exitosamente”) y la herramienta aparecerá en la lista general de inventario con su nombre e ID.
8. Repetir para cada herramienta: Proceda a registrar de esta forma todas las herramientas etiquetadas. Este proceso inicial puede ser laborioso si son muchas unidades, pero es necesario hacerlo una sola vez. Una vez ingresadas, ya no tendrá que volver a registrar esas herramientas, salvo que incorpore herramientas nuevas al

pañol en el futuro.

Consejo: Es conveniente llevar un orden durante el registro, por ejemplo, registrar por categorías o por estantes, para no olvidar ninguna herramienta. Si dispone de ayuda, dos personas pueden agilizar la tarea: una va pasando o escaneando las herramientas y la otra completando los datos en la interfaz.

Método alternativo – Registro mediante detección: Si prefiere, puede registrar herramientas sobre la marcha aprovechando la detección automática. Por ejemplo, simplemente pase una herramienta con tag por el portal RFID (con el sistema ya en funcionamiento); el sistema la detectará y en la interfaz aparecerá un registro de una etiqueta desconocida. Luego, ingrese a la sección de herramientas en la interfaz y edite ese nuevo ID para asignarle un nombre y detalles. De esta manera está “renombrando” la etiqueta detectada para que en adelante aparezca correctamente identificada. Este método puede usarse para dar de alta herramientas de manera más rápida tras verificar físicamente su lectura, pero asegúrese de documentar cada nueva herramienta adecuadamente luego de detectar su tag.

### 7.2. Administración de herramientas en la interfaz

Una vez registradas, puede ocurrir que con el tiempo se requiera editar la información de una herramienta en el sistema (por ejemplo, corregir un nombre, actualizar la ubicación, o reasignar una etiqueta si la original se dañó). Asimismo, puede haber casos en que se deba dar de baja una herramienta del inventario. Estas tareas se realizan desde la interfaz web, generalmente en la sección de Inventario/Herramientas, y suelen requerir permisos de administrador. A continuación se describen las principales operaciones de administración de herramientas:

- Editar o renombrar una herramienta: En la lista de herramientas del sistema, ubique la herramienta deseada (puede usar la barra de búsqueda si hay muchas entradas). Junto a cada registro suele haber iconos o botones de acción, como Editar (ícono de lápiz). Haga clic en editar para abrir el formulario de edición (similar al formulario de alta). Modifique el campo “Nombre” u otros campos que necesite cambiar (por ejemplo, agregar la potencia al nombre: de “Taladro Bosch” a “Taladro Bosch 550W”). Guarde los cambios. Automáticamente el nuevo nombre aparecerá en los listados y en futuros registros del sistema. (Nota: cambiar el nombre no suele afectar al historial pasado; los registros antiguos podrían seguir mostrando el nombre viejo a menos que el sistema implemente actualización retroactiva. Esto normalmente no es un problema, pero téngalo presente.)*
- Reemplazar la etiqueta RFID de una herramienta: Si una etiqueta se pierde o se rompe y necesita pegar una nueva en la herramienta, hay que actualizar su ID en el sistema. Para hacerlo, edite la herramienta correspondiente en la interfaz y localice el campo de código RFID/ID de tag. Escanee la nueva etiqueta (ya adherida a la herramienta) utilizando la función de lectura, o ingrese manualmente el nuevo código en ese campo. Guarde los cambios. A partir de ese momento, el sistema reconocerá ese nuevo tag como la misma herramienta. Importante: Asegúrese de retirar o inutilizar la etiqueta anterior para que no cause confusiones (por ejemplo, si la etiqueta vieja quedó tirada en el pañol y todavía transmite, podría generar lecturas fantasmas; es mejor descartarla físicamente).
- Baja de una herramienta: Si un objeto deja de formar parte del inventario (ejemplo: herramienta dada de baja permanente, extraviada sin retorno, o retirada del servicio), el sistema ofrece la opción de desactivar o eliminar esa herramienta. Use esta función con precaución, pues podría eliminar también su historial asociado. En algunas implementaciones se prefiere marcar la herramienta como inactiva en lugar de borrarla completamente. Siga las indicaciones de la interfaz (generalmente la opción de baja aparece junto al editar, con un icono de papelera o similar). Confirme la acción cuando se le pregunte. Después de esto, el tag RFID de esa herramienta ya no será reconocido como un ítem válido (si alguien intenta pasarlo por el portal, el sistema lo tomará como etiqueta desconocida, hasta que se vuelva a asignar).
- Revisar herramientas desconocidas: En operación, si el sistema detecta una etiqueta no registrada (por ejemplo una herramienta nueva no dada de alta), esta podría aparecer en la interfaz de alguna forma (un evento de “tag desconocido”). En esos casos, deberá registrar esa etiqueta como herramienta nueva (siguiendo los pasos del punto 7.1) o asociarla a una existente, para que quede identificada correctamente a futuro.
- Registro de usuarios (operarios): Aunque el foco principal son las herramientas, para aprovechar la trazabilidad completa de SICAP es necesario que cada usuario (operario, estudiante, etc.) esté registrado con su identificación RFID (la pulsera u tarjeta asignada). Normalmente hay un módulo de “Usuarios” en la interfaz web. Para añadir un nuevo usuario, ingrese en dicha sección y utilice la opción “Agregar usuario”. Complete el nombre del empleado/estudiante, algún identificador adicional (legajo, departamento, etc. si se requiere) y escanee la pulsera RFID del usuario para capturar su código único, o escríbalo manualmente. Guarde el registro. Una vez hecho esto, el sistema podrá reflejar “quién” retira/deposita las herramientas al leer la pulsera en el portal. Asegúrese de mantener actualizado este listado de usuarios (por ejemplo, dar de baja o desactivar usuarios que ya no están en la institución, y registrar al personal nuevo entregándoles pulseras vinculadas).

### 7.4. Operación automática del sistema (entradas, salidas, registros)

Con todas las herramientas y usuarios cargados, SICAP funciona automáticamente para monitorear las entradas y salidas de herramientas del pañol en el día a día. A continuación se describe cómo es el flujo normal de uso y qué hace el sistema por sí solo, así como consideraciones para el encargado del pañol:

Detección de retiro de herramienta: Cuando un operario necesita una herramienta, él/ella (llevando su pulsera RFID personal) ingresa al pañol, toma la herramienta deseada y sale pasando por el portal RFID con la herramienta en la mano. En ese instante, el portal detecta simultáneamente la etiqueta de la herramienta y la de la pulsera del usuario. El sistema SICAP, a través del ESP32, combina esa información y determina que “el Usuario X está retirando la Herramienta Y”. Automáticamente se crea un registro de Salida en la base de datos, con campos como: Herramienta Y – Retirada por Usuario X – Fecha/Hora tal. Todo esto ocurre sin que el usuario deba detenerse a anotar nada. Si varias herramientas salen juntas (por ejemplo, alguien saca un kit de varias piezas a la vez), las antenas detectarán múltiples tags en la pasada y se registrarán múltiples salidas bajo el mismo usuario (siempre que la pulsera del usuario haya sido leída en ese momento).

Detección de devolución de herramienta: De forma análoga, al retornar la herramienta, el usuario entra al pañol atravesando el portal con la herramienta que va a devolver. El sistema lee nuevamente la etiqueta de la herramienta y la pulsera, registrando ahora un evento de Entrada: Herramienta Y – Devuelta por Usuario X – Fecha/Hora. El inventario se actualiza automáticamente marcando esa herramienta como “Disponible” nuevamente en el pañol. Nuevamente, esto no requiere ninguna acción manual más que pasar por el portal con la herramienta.

Registro de eventos y actualización de estado: Cada entrada o salida queda guardada en la base de datos. La interfaz de SICAP suele contar con un módulo de Historial o Movimientos Recientes, donde el encargado puede ver en tiempo real lo que está sucediendo. Por ejemplo: “Hace 2 min – Martillo N°5 retirado por Juan Pérez”, “Hace 1 hora – Taladro devuelto por Ana López”. Este historial permite resolver dudas comunes (¿Quién tiene tal herramienta actualmente? ¿A qué hora salió? etc.). Además, en la vista de Inventario o listado de herramientas, el estado de cada herramienta se actualiza dinámicamente: puede marcarse con un icono o color si está En uso/Fuera del pañol, o Disponible/En pañol. De esta manera, a simple vista se sabe qué herramientas no se encuentran en el depósito en ese momento y con quién.

Alertas o comportamientos adicionales: Dependiendo de la configuración del software SICAP, puede haber automatizaciones o alertas extra para casos especiales:

- Por ejemplo, si una herramienta sale sin asociar ningún usuario (caso hipotético en que una herramienta pasa por el portal pero ninguna pulsera fue detectada), el sistema podría marcar el evento como “Retiro no autorizado” o “Herramienta retirada sin identificar usuario”. En esos casos, podría notificar al encargado vía correo electrónico o mostrar el evento en la interfaz resaltado en rojo. Es buena práctica que el encargado revise estos casos, pues podría indicar que alguien no registrado tomó algo, o simplemente que el usuario olvidó llevar su pulsera.
- Otro comportamiento posible: alarmas por tiempo excedido. Por ejemplo, si una herramienta permanece fuera más allá de un tiempo predefinido, el sistema podría resaltar ese hecho (ej: “Taladro N°3 lleva 7 días fuera”). Estas reglas de negocio pueden configurarse según las necesidades de la institución (por ejemplo, si se requiere que las herramientas se devuelvan al finalizar cada jornada, etc.).
- Notificaciones en tiempo real: Si está habilitado, el sistema podría enviar mensajes o emails cada vez que ocurre un movimiento, ya sea al propio usuario, al supervisor, o al encargado. Revise la documentación de software de SICAP para ver si existen opciones de notificación que se puedan activar según sus políticas.

Consulta de historial: El encargado del pañol, desde su PC, puede consultar en cualquier momento el historial completo de movimientos. Es posible filtrar por herramienta (por ejemplo: ¿cuándo y quién sacó por última vez el taladro X?), por usuario (¿qué herramientas ha utilizado cierto operario?), o por rango de fechas (movimientos de la última semana, del último mes, etc.). Esto es sumamente útil para auditorías. Por ejemplo, al final del día se puede generar un reporte de todas las herramientas que salieron y verificar cuáles volvieron; aquellas que sigan marcadas como fuera se sabrá con quién están, gracias al registro.

Interacción mínima de los operarios: Los usuarios u operarios que toman las herramientas no necesitan operar ninguna interfaz de SICAP en el día a día; no tienen que tipear datos ni escanear manualmente códigos de barras, etc. Solo deben portar su pulsera personal y pasar normalmente por el portal con las herramientas al entrar o salir del pañol. Se aconseja instruir a los usuarios para que no intenten evadir el portal ni ocultar las herramientas, con la intención de “saltarse” el registro – además de ser un mal procedimiento, es difícil engañar al sistema ya que la lectura UHF atraviesa materiales no metálicos. De cualquier manera, promover una cultura de cumplimiento es importante: el sistema beneficia a todos porque evita pérdidas y elimina disputas sobre quién tomó qué.

Situaciones especiales:

- Préstamo entre compañeros: Si un usuario A tomó una herramienta y luego, sin devolverla al pañol, se la entrega directamente a un usuario B (es decir, un traspaso interno fuera del portal), el sistema no tendrá forma de saberlo en el momento. En los registros seguirá figurando que A tiene la herramienta hasta que esta vuelva a pasar por el portal con B. Es importante que las políticas internas establezcan que las herramientas siempre salgan y entren oficialmente por el pañol (pasando por el portal RFID) para no romper la trazabilidad que brinda el sistema.
- Herramienta extraviada o no devuelta: Si una herramienta no regresa al pañol en el tiempo esperado, el historial indicará quién fue el último en retirarla. Eso ofrece un punto de partida para recuperarla o investigar su paradero. SICAP no evita por sí solo la pérdida intencional, pero deja claros los responsables del último uso.
- Múltiples usuarios juntos: Si dos personas salen juntas por el portal llevando varias herramientas al mismo tiempo, el sistema intentará asociar cada herramienta al usuario cuya pulsera detectó simultáneamente. En el peor de los casos, si ambos usuarios pasan exactamente a la par, el sistema podría leer dos pulseras y varios tags a la vez, generando cierta ambigüedad en la asignación (por ejemplo, podría registrar todas las herramientas a un solo usuario o dividirlas incorrectamente). La recomendación operativa es: que los usuarios pasen de a uno por el portal con sus herramientas, para mayor claridad en los registros. De cualquier forma, todos los tags leídos (tanto de personas como de herramientas) quedarán registrados en la base de datos del evento bruto, lo que permite auditar después si fuera necesario.

En conclusión, el sistema SICAP automatiza la gestión del pañol: toda entrada o salida de herramientas queda registrada con fecha, hora y responsable, sin trabajo administrativo manual en ese momento. El rol del encargado del pañol se vuelve más de supervisión a posteriori mediante la interfaz, en lugar de anotar y controlar físicamente cada movimiento. Es importante, no obstante, que el encargado conozca y use la interfaz regularmente para:

- Verificar que no haya anomalías (ej. eventos de retiro sin usuario, herramientas desconocidas detectadas, etc.).
- Asegurarse de que todas las herramientas que están fuera sean devueltas en un tiempo razonable según las normas.
- Mantener actualizados los catálogos de usuarios y herramientas (altas, bajas, reemplazos de tags).

La guía de uso para los operarios podría resumirse en una sola indicación: “Siempre lleva tu pulsera RFID y no olvides pasar por el portal con las herramientas al entrar o salir.” El resto, SICAP se encarga automáticamente.

## 8. Mantenimiento y Buenas Prácticas

Para garantizar el funcionamiento confiable de SICAP a largo plazo, es necesario realizar tareas periódicas de mantenimiento y seguir ciertas buenas prácticas en el uso diario. A continuación, se enumeran recomendaciones para cuidar los equipos y el sistema en general:

- Revisiones periódicas del hardware: Establezca un cronograma (por ejemplo, mensual) para inspeccionar físicamente todos los componentes críticos del sistema:
- Verifique que las antenas RFID sigan firmemente montadas en el portal y orientadas correctamente. Si encuentra tornillos o abrazaderas flojas, ajústelos. Limpie la superficie de la antena con un paño seco (el polvo excesivo podría, en casos extremos, atenuar la señal).

- Inspeccione los cables coaxiales de antena en busca de desgaste, dobleces pronunciados, cortes en el aislamiento o conectores flojos. Cualquier signo de daño en el cable o en sus conectores debe atenderse de inmediato (reemplazo o reparación), ya que afecta críticamente el alcance de lectura.
- Revise la caja del lector/ESP32: asegúrese de que esté bien sellada, sin humedad en el interior y sin “visitantes” indeseados (insectos u otros). Confirme que los LED indicadores del lector y del ESP32 muestran actividad normal (según el manual específico de cada uno; típicamente un LED de poder encendido fijo y otro de comunicación parpadeando, en el caso del ESP32).
- Compruebe los LEDs del router y la Raspberry Pi: un router con indicadores de falla (p.ej. luz de “Internet” en rojo) no es relevante si la red es aislada sin internet; pero la luz de Wi-Fi debe estar activa mostrando que la red local funciona. La Raspberry Pi suele tener un LED verde parpadeando (actividad de la tarjeta SD) y un LED rojo fijo (alimentación correcta); si ve el LED rojo apagado o parpadeando, puede indicar problemas de voltaje (quizá fuente insuficiente o cable USB de alimentación en mal estado).
- Cuidado de la base de datos y software (Raspberry Pi): Al ser la Raspberry Pi una computadora que maneja datos importantes, requiere algunos cuidados en el ámbito de software:
- Backups regulares: Si es posible, realice copias de seguridad periódicas de la base de datos de SICAP, especialmente antes de hacer actualizaciones o cambios mayores. Esto protegerá el historial y los registros del inventario ante cualquier fallo. Puede hacerlo extrayendo el archivo de base de datos a otra ubicación segura o mediante herramientas de backup que el software SICAP provea.
- Actualizaciones controladas: Aplique actualizaciones del sistema (ya sea del sistema operativo de la Pi o del software SICAP) solo cuando sea necesario y preferiblemente fuera del horario de uso (para no interrumpir el servicio). Documente los cambios realizados. Antes de actualizar, asegúrese de tener un backup reciente y de saber cómo restaurar el sistema si algo falla.
- Integridad de la tarjeta SD: La Raspberry Pi almacena el sistema y datos en una tarjeta microSD, la cual puede degradarse con el tiempo (especialmente con escrituras constantes). Minimice los apagados bruscos para evitar corrupción de datos. Considere usar una tarjeta SD de buena calidad o incluso soluciones de almacenamiento más robustas (ej. un disco SSD externo) si el proyecto lo permite. Tener una tarjeta SD clonada de repuesto con la configuración lista sería ideal para contingencias.

- Mantenimiento de etiquetas RFID: Las etiquetas en las herramientas y pulseras requieren poca atención, pero no olvidarlas:
- Si ve alguna etiqueta despegándose de una herramienta, limpie la superficie y vuelva a adherirla con un adhesivo fuerte, o reemplace la etiqueta por una nueva si está dañada. Cada vez que reemplace una etiqueta, actualice el sistema con el nuevo ID (como se explicó en la Guía de Uso) para que esa herramienta siga siendo reconocida correctamente.
- Mantenga un pequeño stock de etiquetas de repuesto (especialmente tags on-metal y pulseras adicionales) para reponer inmediatamente si alguna se pierde o daña. Así el sistema no quedará con “agujeros” en el control por falta de etiquetas.
- Las pulseras de usuarios, si son de uso diario, podrían desgastarse con el tiempo. Revise periódicamente que el chip interno no esté expuesto ni agrietado. Reemplace la pulsera completa en caso necesario y registre el nuevo código de tag al usuario correspondiente.
- Limpieza y orden en el pañol: Aunque no es directamente parte del sistema electrónico, un pañol ordenado contribuye a un funcionamiento óptimo del SICAP:
- Trate de que las herramientas con etiquetas no queden amontonadas muy cerca de la antena cuando estén guardadas, para evitar lecturas no intencionales. Por ejemplo, si el portal está cerca de la entrada y hay estanterías pegadas al portal llenas de herramientas con tags, podría ocurrir que algunas se lean aun sin haber salido oficialmente. Mantenga cierta distancia entre el área de lectura del portal y el resto del inventario, o coloque una barrera física metálica detrás de la antena para delimitar el campo de lectura. (Esta es más bien una consideración de instalación, pero se menciona aquí como recordatorio operativo.)
- Mantenga despejada la zona del portal: no coloque contenedores metálicos, cajas de herramientas, o muchos objetos justo debajo o alrededor del portal que puedan interferir con la detección de las etiquetas cuando las personas pasan.
- Si hay puertas metálicas en el pañol cerca del portal, procure que la antena no apunte directamente hacia ellas (ya que reflejan la señal RF) o manténgalas abiertas durante el movimiento de entrada/salida de herramientas. Esto ayuda a evitar reflexiones e interferencias que podrían afectar la lectura.
- Pruebas de rutina: Es aconsejable realizar pruebas funcionales periódicas aunque el sistema esté operando normalmente:

- Cada inicio de semana (o diariamente, según la criticidad del pañol) pase intencionalmente una herramienta por el portal y verifique que el sistema la registre adecuadamente (que aparezca el evento en la interfaz). Esto confirma que todo el sistema (antena, lector, ESP32, red, servidor) esté en línea.
- Si recientemente se añadieron usuarios nuevos o se reemplazaron pulseras, pida a esos usuarios que pasen por el portal con alguna herramienta de prueba para verificar que son detectados correctamente y asociados.
- Si nota algún comportamiento extraño en las lecturas (por ejemplo, lecturas duplicadas excesivas, o herramientas que no se leen consistentemente), investigue de inmediato: podría ser señal de algún ajuste necesario en la antena (posición, ángulo), interferencias nuevas en el ambiente, o configuración del lector (quizás haya que ajustar la potencia de salida o la sensibilidad). Pequeños ajustes en la configuración de software/hardware del lector pueden resolver problemas de lectura y generalmente están disponibles en la aplicación de administración de SICAP o en la consola del lector.
- Seguridad y buenas prácticas de uso:
- Control de accesos físicos: Aunque SICAP registra quién entra con qué herramienta, no impide físicamente la salida de objetos. Si se requiere un nivel de control mayor (por ejemplo, anti-robo), podría complementarse el sistema con alarmas sonoras o con puertas de acceso controladas electrónicamente. Por ahora, SICAP asume un entorno de confianza donde el sistema actúa como disuasorio y de registro. Aun así, mantenga las cerraduras del pañol o presencia de personal encargado según las normas de su institución para prevenir accesos no autorizados.
- Privacidad de datos: Los datos sobre quién utiliza qué herramienta pueden considerarse información sensible. Asegúrese de almacenarlos de forma segura y de cumplir con las normas de privacidad que correspondan (por ejemplo, leyes de protección de datos en entornos laborales o educativos). Sólo personal autorizado debe acceder al historial completo de movimientos.
- Soporte eléctrico: Si el pañol y su operación son críticos, considere proteger todo el sistema con un UPS (Sistema de Alimentación Ininterrumpida). Un UPS mantendrá la Raspberry Pi, el router y el lector funcionando por unos minutos en caso de corte de luz, evitando caídas bruscas del sistema. Además, un UPS filtra picos de tensión, protegiendo los equipos de sobretensiones de la red eléctrica.
- Documentación: Mantenga este manual a mano y actualizado. Si realiza alguna modificación al sistema (por ejemplo, agregar una segunda antena, cambiar la IP del servidor, reemplazar el router, etc.), anótelo en la sección correspondiente del manual.

Un pañol puede ser manejado por distintas personas a lo largo del tiempo, y contar con la documentación al día será valioso para entrenar a otros y para resolver problemas rápidamente.

Siguiendo estas buenas prácticas, SICAP se mantendrá en óptimas condiciones. La tecnología RFID y los componentes involucrados requieren un mantenimiento mínimo, pero no nulo. Una atención preventiva periódica evitará sorpresas y prolongará tanto la vida útil del hardware como la confiabilidad de los datos. En caso de dudas o situaciones no cubiertas aquí, contacte al soporte técnico del proyecto (consulte la sección Contacto y Soporte Técnico) antes de intentar soluciones improvisadas.

## 9. Solución de Problemas Básicos

A continuación, se presentan algunos problemas comunes que podrían surgir durante el uso de SICAP, junto con posibles causas y soluciones. Ante cualquier inconveniente, verifique estas sugerencias:

- El sistema no detecta ninguna etiqueta (no lee herramientas ni pulseras):
- Posibles causas: Lector RFID sin alimentación, antena mal conectada o dañada, cables de RF sueltos, ESP32 desconectado o sin comunicación, o la placa conversora RS232-TTL mal conectada (en caso de usarse).
- Soluciones: Verifique que el lector RFID esté encendido y que su LED de funcionamiento indique actividad. Confirme la conexión firme de la antena al lector (y que el puerto de antena usado esté habilitado en la configuración del lector). Revise el cableado entre el lector y el ESP32/conversor: que los cables TX/RX estén correctamente cruzados y en buen estado, y que la placa conversora esté alimentada. Compruebe que el ESP32 esté encendido (LED de power) y conectado a la red (por Wi-Fi). Si todo el hardware parece correcto, reinicie el sistema en el orden adecuado (Pi, luego lector/ESP32) y vuelva a probar.
- Se puede acceder al sistema, pero no aparecen datos de lecturas (herramientas no figuran al pasar):
- Posibles causas: El ESP32 no está enviando datos al servidor (quizás no conectado a Wi-Fi o con el programa detenido), o la comunicación entre ESP32 y lector está fallando. También puede ser que las etiquetas no estén registradas (aparecerían como desconocidas).
- Soluciones: Verifique en la interfaz web si el ESP32 aparece “online” o conectado. Si no, compruebe las credenciales Wi-Fi configuradas en el ESP32 y la cobertura de la señal. Si el ESP32 está conectado pero no llegan lecturas, intente revisar la consola serial del ESP32 (si tiene acceso) para ver si está recibiendo datos del lector. Asegúrese de que la placa conversora RS232-TTL esté correctamente instalada si el lector lo requiere (sin ella, no habría comunicación serial entendible). Si las lecturas sí ocurren pero las herramientas salen listadas como ID desconocido, significa que los tags se detectan pero esas etiquetas no fueron registradas en el sistema: deberá registrar o asignar nombres a esos IDs en la base de datos (ver sección de Registro de herramientas).
- No se puede acceder a la interfaz web (no carga la página de SICAP):
- Posibles causas: Problemas de red o del servidor. La Raspberry Pi puede estar apagada, congelada, sin conexión a la red, o la IP puede haber cambiado. Alternativamente, el servicio web (la aplicación SICAP) no se inició correctamente.
- Soluciones: Compruebe que la Raspberry Pi esté encendida y funcionando (luces LED normales). Intente hacer ping a la IP de la Pi desde otro dispositivo de la red para ver si responde. Si la Pi no responde, conecte un monitor/teclado para verificar su estado, reiniciándola si es necesario. Confirme que el dispositivo desde el que accede esté conectado a la red correcta. Verifique la dirección IP de la Pi nuevamente (por si hubiera cambiado al reiniciar el router, en caso de IP dinámica). Si la Pi está activa en red pero la página web no carga, puede que el servidor de SICAP (servicio backend) no esté corriendo: acceda por SSH o en la propia Pi y reinicie el servicio correspondiente (según indicaciones técnicas del software). Si no tiene esos conocimientos, reiniciar la Raspberry Pi suele reactivar la aplicación en muchos casos.
- El ESP32 aparece desconectado en la interfaz (o no figura en la red):
- Posibles causas: Credenciales Wi-Fi incorrectas en el ESP32, señal Wi-Fi débil, o el ESP32 no inició correctamente su programa.
- Soluciones: Acerque físicamente el ESP32 (portal) más cerca del router para descartar problemas de señal. Verifique que el SSID y contraseña programados en el firmware del ESP32 coinciden con los del router (si no, deberá reprogramar el ESP32 con los datos correctos). Reinicie el ESP32 (cortando y restaurando su alimentación) y observe si se conecta al router (puede mirar en la lista de clientes del router si aparece). Si sigue sin conectarse, puede ser necesario depurar el ESP32 mediante conexión USB para ver mensajes de error en el arranque.

- Lecturas RFID erráticas o inestables:
- Situaciones: El sistema a veces no detecta una herramienta que pasó, o al contrario, registra múltiples veces la misma cuando solo pasó una vez; también pueden aparecer lecturas fantasma de herramientas que en realidad están cerca del portal pero no salieron.
- Posibles causas: Potencia del lector demasiado alta o configuración de sensibilidad que causa lecturas de entornos no deseados; interferencia de materiales metálicos cerca; múltiples reflexiones de la señal; o la antena mal orientada. También un cable coaxial deteriorado puede causar fluctuaciones.
- Soluciones: Revise la configuración del lector RFID: si hay parámetros de potencia o sensibilidad, ajústelos para lograr lectura fiable solo en la zona deseada (por ejemplo, reducir ligeramente la potencia para no leer herramientas que estén guardadas inmediatamente detrás del portal). Asegúrese de que la antena esté firmemente orientada hacia la zona de paso y no hacia estantes de herramientas. Compruebe las recomendaciones de la sección Limpieza y orden en el pañol para reducir lecturas no intencionales (alejar estanterías o colocar pantalla metálica de fondo). Verifique también las conexiones coaxiales y reemplácelas si sospecha de algún defecto.
- El lector RFID no enciende (no se observan luces ni lecturas y debería):
- Posibles causas: Falta de alimentación o falla de la fuente. Cable de poder desconectado. Fusible interno del lector quemado (algunos tienen protección).
- Soluciones: Compruebe la salida de la fuente de alimentación con un multímetro (que entregue el voltaje esperado). Revise que el conector de alimentación esté bien inserto en el lector y con la polaridad correcta. Asegúrese de que la toma eléctrica 220V funciona (pruebe otro dispositivo o use otro enchufe). Si la fuente tiene un LED indicador, vea si está encendido. En última instancia, probar con otra fuente compatible descartará si la original está defectuosa. Si nada enciende en el lector, contacte a soporte técnico ya que podría ser un daño interno del equipo.
- Una herramienta aparece con código en los registros en vez de nombre (ID numérico incomprensible):
- Causa: Esa etiqueta fue leída pero no está registrada con nombre en el sistema. Esto ocurre típicamente cuando pasa por el portal una herramienta nueva que no fue dada de alta, o una etiqueta no reconocida.

- Solución: Diríjase a la sección de Inventario/Herramientas y verifique si hay algún item pendiente o registre una nueva herramienta con ese ID (puede copiar/pegar el código visto en el historial). Asigne el nombre correcto a ese código y guarde. A partir de entonces, las futuras lecturas de ese tag mostrarán el nombre de la herramienta. Puede editar el registro histórico para corregirlo si el sistema lo permite, pero lo importante es que quede registrada para el futuro.

Si el problema persiste después de revisar estos puntos básicos, consulte la sección de Contacto y Soporte Técnico para obtener ayuda especializada. Es mejor no dejar de usar el sistema con fallas prolongadas; una atención temprana garantiza la continuidad y exactitud del control del pañol.

## 10. Contacto y Soporte Técnico

Si enfrenta dificultades técnicas con el sistema SICAP, o tiene preguntas que este manual no responde, no dude en buscar soporte. A continuación, se brindan los datos de contacto para asistencia técnica, así como recursos adicionales de ayuda:

- Equipo desarrollador de SICAP: Para consultas directas al equipo que diseñó e implementó el proyecto (por ejemplo, dudas de configuración avanzada, reporte de bugs en el software, solicitudes de mejora):
- Correo electrónico: proyecto.sicap08@gmail.com
- Instagram (Proyecto SICAP): @proyecto.sicap – Aquí el equipo publica novedades y se puede contactar vía mensaje directo. Es útil para ver actualizaciones o soluciones que compartan con la comunidad de usuarios.
- GitHub del proyecto: github.com/impatrq/SICAP – Repositorio de código fuente. Para reportar issues relacionados con software o colaborar con el desarrollo.
- Materiales de referencia: Documentación y manuales complementarios que pueden ser de ayuda para resolver dudas específicas:
- Manual del lector RFID UHF: Consulte el manual técnico del modelo de lector instalado para detalles sobre sus puertos, indicadores LED, comandos de configuración y solución de problemas comunes del lector (por ejemplo, significados de códigos de error, ajustes de potencia, etc.).
- Guía de usuario de la interfaz SICAP: Si existe documentación específica de la aplicación web (ayuda integrada, sección “?” de ayuda en el menú del sistema), revísela para entender a fondo las funciones del software, ya que este manual se enfocó en la instalación y uso general.
- FAQ sobre tecnología RFID: En el sitio web de SICAP o en recursos generales de RFID (por ejemplo, las preguntas frecuentes de tecnología RFID de proveedores como HID Global) se explican conceptos que pueden clarificar dudas sobre alcance de lectura, interferencias, elección de etiquetas, etc., en caso de tener problemas de rendimiento.
- Servicio técnico in-situ: Si ocurre una falla de hardware que usted no pueda resolver (por ejemplo, una antena averiada, la Raspberry Pi no inicia, el lector RFID presenta una falla interna), coordine con el soporte técnico del proyecto para una visita en sitio. No intente reparar componentes electrónicos avanzados por su cuenta sin la capacitación adecuada, ya que podría invalidar garantías o empeorar la situación.
- Al contactar al soporte: Tenga a mano información clave sobre su instalación para agilizar la asistencia. Por ejemplo: la versión del software SICAP instalada (si aparece en la interfaz, anótela), la fecha de instalación o última actualización, una descripción precisa del problema, y los pasos que llevaron a ese error o falla (si es reproducible). Mientras más detalles provea, más rápida y eficaz podrá ser la ayuda brindada por el equipo de soporte.

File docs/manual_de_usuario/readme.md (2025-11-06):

# 📘 Manual de Usuario – SICAP

**Sistema Integral de Control Automatizado del Pañol**  
**Versión:** 2025  
**Autores:** Lautaro Santolucito, Pablo Osores, Facundo Spagnoletta, Facundo Ledesma, Tiziano Patella  
**Curso:** 7mo 1ra Aviónica – E.E.S.T. N°7 “Taller Regional Quilmes”

---

## 📄 Descripción General

El **Manual de Usuario de SICAP** ofrece una guía completa para la **instalación, configuración y uso** del sistema desarrollado por el equipo.  
SICAP es una solución tecnológica que automatiza el control de herramientas mediante **tecnología RFID**, eliminando registros manuales y aumentando la trazabilidad dentro de talleres, pañoles o empresas.

El documento fue creado para asistir tanto a técnicos instaladores como a usuarios del sistema.

---

## 🧩 Contenidos del Manual

El manual incluye las siguientes secciones:

1. **Glosario:** Definiciones técnicas de todos los componentes (ESP32, RFID, Router, Antena, Raspberry Pi, etc.).  
2. **Introducción:** Explicación del propósito, objetivos y posibles aplicaciones del sistema.  
3. **Hardware del Sistema:** Lista detallada de todos los componentes con su función y conexión correspondiente.  
4. **Precauciones Generales:** Advertencias de seguridad para evitar daños en los equipos o lecturas incorrectas.  
5. **Instalación Física:** Paso a paso para el montaje del portal RFID, conexión del lector, antenas, ESP32 y servidor.  
6. **Configuración Inicial:** Guía para acceder al sistema desde el navegador y ajustar los parámetros de red.  
7. **Guía de Uso:** Registro y administración de herramientas, usuarios y operaciones automáticas de entrada/salida.  
8. **Mantenimiento:** Buenas prácticas, rutinas de revisión y respaldo de datos.  
9. **Solución de Problemas:** Tabla de fallas comunes con causas y soluciones.  
10. **Contacto y Soporte Técnico.**

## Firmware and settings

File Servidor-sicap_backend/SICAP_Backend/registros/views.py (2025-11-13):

from django.http import JsonResponse
from rest_framework.decorators import api_view, permission_classes
from django.views.decorators.csrf import csrf_exempt, ensure_csrf_cookie
from django.views.decorators.http import require_GET
from django.db.models import Q, Max
from django.shortcuts import get_object_or_404
from django.utils import timezone
from django.utils.timezone import localtime
from rest_framework.response import Response
from rest_framework.permissions import AllowAny
from rest_framework.viewsets import ModelViewSet
from rest_framework import mixins, viewsets
from .models import RegistroTag, Panol, Asignacion, PersonaSesion
from .serializer import PanolSerializer, RegistroTagSerializer, AsignacionSerializer
import json


def _norm_cat(raw):
    """Normaliza categoría: solo 'persona' o 'insumo'."""
    if raw is None:
        return None
    k = str(raw).strip().lower()
    if k in (
        "objeto",
        "object",
        "item",
        "herramienta",
        "herramientas",
        "tool",
        "tools",
    ):
        return "insumo"
    if k in ("persona", "person", "usuario", "user", "empleado", "empleados"):
        return "persona"
    if k == "insumo":
        return "insumo"
    return None


@csrf_exempt
def recibir_tag(request):
    """Endpoint principal para recibir tags escaneados."""
    if request.method != "POST":
        return JsonResponse({"error": "método no permitido"}, status=405)
    try:
        data = json.loads(request.body or "{}")
    except Exception as e:
        return JsonResponse({"error": f"json inválido: {e}"}, status=400)

    tag = str(data.get("tag", "")).strip()
    if not tag:
        return JsonResponse({"error": "tag faltante"}, status=400)

    nombre = (data.get("nombre") or "").strip() or None
    categoria_recibida = _norm_cat(data.get("categoria"))
    now = timezone.now()

    reg, created = RegistroTag.objects.get_or_create(
        tag=tag,
        defaults={"nombre": nombre, "categoria": categoria_recibida, "fecha_hora": now},
    )

    if not created:
        if nombre:
            reg.nombre = nombre
        if categoria_recibida in ("persona", "insumo"):
            reg.categoria = categoria_recibida
        reg.fecha_hora = now
        reg.save(update_fields=["nombre", "categoria", "fecha_hora"])
        RegistroTag.objects.filter(tag=tag).exclude(id=reg.id).delete()

    categoria = reg.categoria

    # Lógica para personas
    if categoria == "persona":
        PersonaSesion.objects.filter(activa=True).update(activa=False, fin=now)
        sesion = PersonaSesion.objects.create(
            persona_tag=tag, nombre=nombre, inicio=now, activa=True
        )
        return JsonResponse(
            {
                "status": "ok",
                "accion": "sesion_abierta",
                "persona_tag": tag,
                "sesion_id": sesion.id,
            }
        )

    # Lógica para insumos
    if categoria == "insumo":
        sesion = PersonaSesion.objects.filter(activa=True).order_by("-inicio").first()

        if not sesion:
            return JsonResponse({"status": "ok", "accion": "sin_sesion_persona"})

        asig_activa = Asignacion.objects.filter(item_tag=tag, activo=True).first()

        if asig_activa:
            # Toggle: devolver
            asig_activa.activo = False
            asig_activa.devuelto_en = now
            asig_activa.save()
            return JsonResponse(
                {
                    "status": "ok",
                    "accion": "asignacion_cerrada",
                    "item_tag": tag,
                    "item_nombre": asig_activa.item_nombre,
                    "persona_tag": asig_activa.persona_tag,
                    "persona_nombre": asig_activa.persona_nombre,
                }
            )
        else:
            # Toggle: asignar
            asig = Asignacion.objects.create(
                persona_tag=sesion.persona_tag,
                persona_nombre=sesion.nombre,
                item_tag=tag,
                item_nombre=reg.nombre,
                asignado_en=now,
                activo=True,
            )
            return JsonResponse(
                {
                    "status": "ok",
                    "accion": "asignacion_creada",
                    "item_tag": tag,
                    "persona_tag": sesion.persona_tag,
                }
            )

    return JsonResponse({"status": "ok"})


@csrf_exempt
def editar_tag(request, id):
    """Edita nombre y/o categoría de un tag."""
    if request.method != "PUT":
        return JsonResponse({"error": "Método no permitido"}, status=405)

    tag_obj = get_object_or_404(RegistroTag, pk=id)
    try:
        data = json.loads(request.body or "{}")
    except Exception:
        return JsonResponse({"error": "JSON inválido"}, status=400)

    if "nombre" in data:
        tag_obj.nombre = data["nombre"]

    if "categoria" in data:
        raw = data["categoria"]
        if raw in (None, "", "null"):
            tag_obj.categoria = None
        else:
            categoria = str(raw).lower().strip()
            if categoria not in ["persona", "insumo"]:
                return JsonResponse(
                    {"error": 'Categoría debe ser "persona" o "insumo"'}, status=400
                )
            tag_obj.categoria = categoria

    tag_obj.save()
    return JsonResponse(
        {
            "status": "ok",
            "id": tag_obj.id,
            "nombre": tag_obj.nombre,
            "categoria": tag_obj.categoria,
        }
    )


@csrf_exempt
def eliminar_tag(request, id):
    """Elimina un tag. Requiere force=1 si hay asignaciones activas."""
    if request.method not in ("DELETE", "POST"):
        return JsonResponse({"error": "Método no permitido"}, status=405)

    tag_obj = get_object_or_404(RegistroTag, pk=id)
    force = False

    try:
        if request.method == "POST":
            body = json.loads(request.body or "{}")
            force = bool(body.get("force", False))
    except Exception:
        pass

    if request.GET.get("force") in ("1", "true", "True", "yes", "y"):
        force = True

    tiene_activos = Asignacion.objects.filter(
        Q(persona_tag=tag_obj.tag) | Q(item_tag=tag_obj.tag), activo=True
    ).exists()

    if tiene_activos and not force:
        return JsonResponse(
            {"error": "Hay asignaciones activas. Usa force=1 para forzar"}, status=409
        )

    tag_obj.delete()
    return JsonResponse({"status": "ok", "borrados": 1})
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

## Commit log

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2025-06-22 Prueba 1
    Este es el código con el cual recibimos devuelta el Número asociado al Tag en crudo.
2025-06-25 Actualización de código
    Hubo líneas que no se habían guardado y a su vez, lo hice más compacto para que sea más legible, ahora leo en la misma línea, los datos en crudo y el número del tag.
2025-06-25 COOLDOWN
    Agrego un cooldown, para que cada vez que pase una etiqueta, pase un cierto tiempo hasta que la puedas pasar devuelta.
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2025-06-27 Agregar la info. de la plaqueta y el porque de su existencia
2025-06-27 Se agregaron los archivos de la placa
    Se adjuntaron los archivos que utilizamos para hacer la placa.
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2025-06-27 Donde dice info. de contacto el link de instagram aparecia mal, no como yo queria
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2025-06-27 Me habia equivocado a la hora de subirlo, ahora si le agregue el resto de informacion de contacto
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2025-06-28 Nuevos modales
    Ante la problemática que generaban los modales a la pagina busque una forma de solucionar el trabado que generaban el mal funcionamiento de la pagina. Tras hablar con el profe Medina el me recomendó que el problema podría estar en las imágenes y no en el modal como tal, por lo que tras reducir el peso de la imágenes y ajustar otros valores para que queden mejor las nuevas imágenes se logro solucionar la problemática de los modales.
2025-06-28 Arreglos
    En esta nueva prueba intento arreglar el cooldown y a su vez acomodo los tags de manera que si un tag me sale repetido no se me printee, sino que se me muestre solo ese tag y la cantidad de veces que se detectó.
2025-06-30 Sección de contacto funcional
    Mediante una API logre que se pueda contactar a sicap desde la aplicación web para poder entrar en contacto con personas interesadas en nuestro proyecto.
2025-06-30 Redirección a la pagina web tras envió de formulario
    Hice una pagina para que al enviar el correo a la persona le salga un mensaje de agradecimiento por haberse puesto en contacto con nosotros.
2025-06-30 Ajuste titulo y subtitulo principal
    A los chicos no les gusto el color y el tamaño que tenían el titulo y el sub así que los tuve que cambiar.
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2025-07-01 Actualización Reader
    Corregí el código para que, en lugar de imprimir una línea nueva cada vez que detecta el mismo tag, ahora agrupe todas esas lecturas en una sola. Al lado, le puse un contador que te dice cuántas vece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
2025-07-01 Volviendo a publicar mi parte por que se borraron cosas con otro commit de los chicos
2025-07-01 web-app x Ionic
    cree una carpeta web-app para poder conectarla a ionic y comenzar con el desarrollo de la app
2025-07-01 Segunda Placa Conversora RS232
    Esta es la segunda Placa Concluida solucionando detalles de la anterior.
2025-07-01 Placa RS232
    Agregué los archivos restantes acerca de las dos placas y acomodé en carpetas todo.
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2025-07-02 Cree el archivo de la carpeta de campo de JULIO y agregue mi parte.
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2025-07-02 Agregue mi parte del dia de hoy a la madrugada, todavia nisiquiera fui a la escuela
2025-07-02 Sección Login creada.
    Sección de login creada para conectar con Django y almacenar datos de inicio de sección.
2025-07-02 archivos .py implementados
    hago el commint en caso de error y tener que volver a una etapa previa.
    [urls.py]
2025-07-02 Actualice la carpeta de campo con mi contribucion el dia de hoy
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2025-07-02 web-app "sicap" eliminada
    al comienzo del desarrollo de la webapp cree una aplicación llamada sicap la cual no termine usando al final por lo que la elimino para evitar confusiones y mejorar la organización de los archivos.
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2025-07-04 Web app x DJango para sección de login conectada exitosamente
    Logre conectar la web app con el servidor creado por lauty, cree una app en django para almacenar todos los datos de login. Esta es la primera versión del código (debe seguir siendo refinado)
2025-07-04 Envío de datos de login guardados exitosamente en el Django
    La anterior actualización había sido de cuando logre levantar el servidor con la web-app. Lo que logre hacer ahora fue que pueda completar un formulario en una pagina creada en Django y que me guarde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
2025-07-06 Fetch aplicado al codigo de la web-app
    Fetch es el encargado de que el envió de datos de usuario se hagan desde el html de la aplicación y no desde el formulario del server de Django.
2025-07-07 Traspaso a Ionic
    Me puse a dar más estilo con funciones de ionic y dando estilo a el formulario.
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2025-07-13 Animación
    Haciendo pruebas para intentar añadir animaciones de inicio en el login
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2025-07-13 Animación Final
    A prueba y error, pude crear la animación al iniciar la app
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2025-07-14 fetch implemetado (todavia no se si funciona)
    commiteo todo x las dudas de que se rompa la app
2025-07-14 Por culpa del codigo anterior dejo de funcionar la app y el server pero ya lo solucione
    no me levantaba las cosas pero ahora lo hace
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2025-08-13 Zonas personalizadas añadidas
    Se pueden añadir zonas de trabajo personalizadas con los nombres que cada uno quiera.
2025-08-13 feat: login por API + login HTML y dashboard con registros; CORS/CSRF y limpieza de URLs
2025-08-13 Añadi carpetas que elimine sin querer al subir con las que habia trabajado hoy.
2025-08-13 Agregue mi parte del dia de hoy a la carpeta de campo
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2025-08-21 LOGIN FUNCIONAL
    logre qque es el login ya registre los usuarios de mi api, entonces cuando los ingresas en el form, te los verifica y te redirige hacia el home de la web-app
2025-08-21 Creo URL y clase
    Las creo definiendo los pañoles y la nueva url para el nuevo inicio
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2025-08-21 Agregar espacios de trabajo añadido( en discusión de mantenerlo o moverlo al menú de inicio).
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2025-08-29 Arreglo en mi Django que dejo de funcionar
2025-09-09 Corrección de código de ESP funcional
    A la fecha de hoy tras todas las modificaciones que hicimos del código del ESP32, este es que anda. Lo único que le falta a este código es verificar el problema de que a pesar de que detecta los tags y nos dice que los envían al servidor, estos realmente no aparecen como nuevos tags en el servidor de Django
    [Reader.py, app.py, wifi.py]
2025-09-09 arreglando temas de endpoint
    [models.py, urls.py]
2025-09-10 Cambie una de las urls para verificar y probar que se puedan enviar de forma exitosa los tags con la raspi
2025-09-17 Arreglos funcionamiento Backend
    Estos son todos los arreglos que hicimos con fabri para poder arreglar el problema de que el ESP no podía ingresar de manera correcta al Sevdidor
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2025-09-19 Solucinando un problema dentro de la url del listado SQL
    [views.py]
2025-09-20 Arreglos para ver si funciona el menu
2025-09-20 mas y mas arreglos
    [serializer.py, urls.py, views.py]
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2025-09-26 server funcionando optimamente y haciendo arreglos de zona horaria
    [models.py, serializer.py, urls.py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]
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2025-09-30 Arreglos en modificaciones para edicion en nombre
    [views.py]
2025-10-01 arreglo error de que ya no levanta la pagina web
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2025-10-02 Arreglo errores que faltaban del modelo categoría
2025-10-02 Modifico la seccion de categoria para garantizar un envio correcto de los datos
    [models.py, serializer.py, views.py]
2025-10-06 Cambie lógica del ts para corregir un problema entre pasaje de tags entre afuera y adentro del pañol
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2025-10-06 arreglo errores que tuve
    [serializer.py, views.py]
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2025-10-12 Arreglos que hacen que funcionen coopertivamente cada apartado del home
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2025-10-12 Hice un arreglo de autoasignaciones, así se pueden devolver automaticamente, sin que nadie lo tenga que hacer, que sea todo automático
    [views.py]
2025-10-15 Nuevo codigo lector de antenas.
    Tras muchos errores, descubrimos que todo este tiempo al detectar los tags, nuestro codigo nos enviaba un nuemero de tag falso de el que realmente era. Tras recibir la ayuda de Medina y modificar la logica completa de todos los codigos logramos recibir los tags con su identificador verdadero, enviarlos al servidor de manera correcta, que intercalen entre pañol y fuera de pañol y que no se le generen dobles identidades a los tags
    [Reader.py, app.py, wifi.py]
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2025-10-22 Implementacion de botones en el README y error menor con sponsor
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2025-10-22 Carpeta de campo: 14 correcto
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2025-10-28 Con Pablo resolvimos problema del lector defectuoso
    [Reader.py, app.py]
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2025-11-06 Revert "cambio de forma de almacenamiento de tags de frontend(forma local) a backend para que todos los dispositivos que ingresen a la app vean lo mismo"
    This reverts commit 4212486bcb2a297be064dd115642c5f63fae2cd9.
    [views.py]
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2025-11-11 tratando de recupera logica de movimiento en interfaz visual
    debido a todos los camios que estuve haciendo sobre el almacenamiento, la interfaz visual dejo de funcionar correctamente por lo que debo recuperar el funcionamiento
    [views.py]
2025-11-11 Ultimos arreglos de raspberry
    [urls.py]
2025-11-11 migraciones nuevas para corregir nuevo error de duplicado de tags
    [views.py]
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2025-11-12 Corrección error de actualización de tags
    Debido a los últimos cambios de lógica que estuve haciendo, al volver a pasar tags que ya habían sido registrados previamente, estos actualizaban su estado al de tags nuevos por lo que nunca se terminaban de guardar. Acabo de corregir eso y los tags que ya están registrados no actualizan su estado.
    [views.py]
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2025-11-12 nueva lógica funcional de pasaje en interfaz visual
    la anterior lógica que había aplicado para el movimiento de tags no funcionaba como correspondía lo que provocaba que no pueda cumplir la función de ver que esta en almacenamiento y que no. Ahora funciona correctamente sin fallas.
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2025-11-12 Cambios de visualización en interfaces porque facu no sabe programar
    Ajusto tonalidad de algunos botones los cuales no se veían de forma correcta y complicaba su localización
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2025-11-14 Revert "Versión final de Asignaciones 3.0"
    This reverts commit e67c7ebbf939887db14771fe0a2405519d069444.
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
